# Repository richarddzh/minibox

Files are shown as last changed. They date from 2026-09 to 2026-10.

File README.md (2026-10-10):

# Minibox

| 目录 | 内容 |
|---|---|
| [`models`](models/enclosure-v2.md) | 四件式 3D 外壳模型、打印文件、尺寸说明及模型检查脚本 |
| [`assets`](assets) | 开发板[尺寸与天线图](assets/esp32s3_devkit_01.jpg)、[5.08 mm 接线端子](assets/crimp_terminal.jpg)、麦克风、功放、RTC、[TFT SPI](assets/tft_spi.jpg)、[摇杆](assets/joystick.jpg)与[三键键盘](assets/keypad.jpg)参考图片（TFT 型号与当前固件配置未核对） |
| [`docs`](docs/hardware-connections.md) | 主控、屏幕和摇杆的模块参数、GPIO 接线及供电注意事项 |
| [`kicad`](kicad/README.md) | KiCad 10 双层模块载板：[正面图例](kicad/renders/minibox-carrier-front-legend.png)、[背面图例](kicad/renders/minibox-carrier-back-legend.png)、GPIO 丝印与 Gerber；实物核对后方可制板 |
| [`esp32_idf_s3n16r8`](esp32_idf_s3n16r8/README.md) | ESP32-S3 N16R8 的麦克风、按钮、屏幕和扬声器测试固件 |

固件项目参考 `C:\gitroot\talking-alarm` 的 ESP-IDF 结构，独立构建，
不依赖该目录；当前默认测试 GPIO4/5/6/7 按钮，以 GPIO5 控制录放音。
当前接线为 RTC SDA=GPIO15、SCL=GPIO16，INMP441 SD=GPIO21，
MAX98357 GAIN=GPIO42、SD/MODE=GPIO47；GPIO17 悬空 NC，
摇杆按压焊脚保持 NC，GPIO42 不用于摇杆按压。

模型文档中的导出和检查命令均在 `models` 目录执行：

```powershell
Set-Location C:\gitroot\minibox\models
python -m unittest discover -s .\tests -p test_mesh_checks.py
```

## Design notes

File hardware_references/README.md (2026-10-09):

# Reference archive

本目录按用户要求保留集成工程的原始资料及关键图纸，方便换机。
PDF 保留原版权声明；TXT 和 PNG 为查阅用提取，不替代原 PDF。
`manifest.json` 记录 SHA-256、大小及 PDF 页数，以便核对迁移完整性。

| 归档文件 | 来源/用途 |
|---|---|
| esp32-s3-wroom.pdf | [Espressif](https://www.espressif.com/sites/default/files/documentation/esp32-s3-wroom-1_wroom-1u_datasheet_en.pdf)，N16R8 模块 |
| max98357.pdf | [Analog Devices](https://www.analog.com/media/en/technical-documentation/data-sheets/MAX98357A-MAX98357B.pdf)，裸功放 |
| inmp441.pdf | [TDK 产品](https://invensense.tdk.com/products/digital/inmp441/)，底部声孔/九焊盘；归档 PDF 为此前获取副本 |
| ap63203.pdf | [Diodes](https://www.diodes.com/assets/Datasheets/AP63200-AP63201-AP63203.pdf)，3.3V 降压 |
| ds3231.pdf | [Analog Devices](https://www.analog.com/media/en/technical-documentation/data-sheets/DS3231.pdf)，SN 内置晶体版本 |
| ch340.pdf | [WCH](https://www.wch.cn/downloads/CH340DS1_PDF.html)，C 型内置时钟及 3.3V 接法 |
| thb001p.pdf | C&K THB001P，[LCSC C2685355](https://www.lcsc.com/product-detail/C2685355.html)，裸摇杆针位/机械图 |
| cpg151101d13.pdf | HanElectricity CPG151101D13，[LCSC C49234235](https://www.lcsc.com/product-detail/C49234235.html)，MX 开关 |
| myoung-bs-12-b3aa003.pdf | MYOUNG，[LCSC C964723](https://www.lcsc.com/product-detail/C964723.html)，CR1220 座极性和尺寸 |
| sn74lv1t34.pdf | [TI](https://www.ti.com/lit/ds/symlink/sn74lv1t34.pdf)，RGB 电平转换 |
| tps25947.pdf | [TI](https://www.ti.com/lit/ds/symlink/tps25947.pdf)，已撤销的 eFuse 研究，非当前 BOM |
| tlv7034.pdf | [TI](https://www.ti.com/lit/ds/symlink/tlv7034.pdf)，已撤销的分立 CC 检测研究 |
| tlv431.pdf | [TI](https://www.ti.com/lit/ds/symlink/tlv431.pdf)，已撤销的 CC 参考电路研究 |
| sn74lvc2g02.pdf | [TI](https://www.ti.com/lit/ds/symlink/sn74lvc2g02.pdf)，已撤销的 CC 窗口逻辑研究 |
| sn74lvc1g11.pdf | [TI](https://www.ti.com/lit/ds/symlink/sn74lvc1g11.pdf)，逻辑研究参考 |
| sn74lvc1g02.pdf / sn74lvc1g08.pdf / sn74lvc1g27.pdf / sn74lvc1g32.pdf / sn74lvc14a.pdf | TI 逻辑研究，未采用或已撤销，非当前 BOM |
| panasonic-zk.pdf | Panasonic 储能电容研究，已撤销，非当前 BOM |
| tusb320.pdf / tusb320lai.pdf | [TI](https://www.ti.com/lit/ds/symlink/tusb320lai.pdf)，未采用的 Type-C 控制器研究；内部 Rd 不可与额外 5.1k 并联 |
| pcf8563.pdf / rkjxv.pdf | 早期 RTC/摇杆研究，**不是当前 BOM** |

USB 实选 HRO TYPE-C-31-M-12，[LCSC C165948](https://www.lcsc.com/product-detail/C165948.html)。
供应商 PDF 返回访问限制，未将错误页伪装成 PDF，也没有归档该型号 STEP。
方向判断使用 KiCad 实际封装坐标；生产前仍须工厂核对实物图纸。

标准符号/封装来自 KiCad 10 库，版权归上游作者，遵循上游
CC-BY-SA 及电路设计例外（见库许可证）。项目自建 INMP441、THB001P、
CR1220 封装由对应器件图纸推导；标准库复制和修改不改变
上游许可。本地缓存不等于完整 3D 模型归档。

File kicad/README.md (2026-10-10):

# Minibox carrier v1.2 — 2026-10-10

This is the user's actual `kicad` carrier, not the separate integrated design.
Open `minibox-carrier.kicad_pro` in KiCad 10. There is **no schematic**:
PCB DRC/net checks do not constitute ERC or schematic-parity verification.
The direct-solder revision is implemented; final review is documented in
[the Chinese HTML guide](carrier-revision.html) and [revision checklist](layout-revision-plan.md).
**Engineering-review files are not permission to manufacture or order.**

## Layout and parts

The board is **94.5 × 117 mm, R5**, four copper layers, nominal 1.6 mm.
Four Ø3.0 mm NPTH holes have **84.5 × 107 mm** center spacing;
KiCad centers are (10,8), (94.5,8), (10,115), (94.5,115) mm.
Each hole has a 3.5 mm-radius/square conservative all-layer copper keepout.
Ø3.0 mm is a tight M3 fit: check screw size/tolerance and the new enclosure.
Bounding-rectangle area is only 1.28% smaller than the old 100 × 112 mm board.

| Placement | Required reservation |
|---|---|
| ESP32 | USB left, antenna right; estimated body stays inside PCB |
| RTC | Upright, battery included in 27.5 × 12 mm reservation; 3.03 mm to ESP32 estimate |
| MAX98357 | Flat 27 × 24 mm reservation; bottom Y=72, above keycap top Y=80.5 |
| Red boundary | Y=76; upper bodies ≤74, lower operation envelopes ≥78 |
| Joystick JS1 | Vertical, center (16.8,95.5); **30 mm diameter** motion may overhang 3.20 mm; body/pad copper retain ≥1 mm to the left copper boundary |
| Microphone | Center (44.455,90.25), Ø19.5 mm envelope; top Y80.5; horizontal maximin clearance to all keycaps and joystick motion is approximately 3.40 mm |
| Four keys | Standard 19.05 mm pitch both ways; lower row moves right 1.425 mm, retaining 8.10 mm left stagger and 0.20 mm to the screw square |
| Keycaps | Maximum accepted envelope 18 × 18 mm; neighboring gap 1.05 mm |
| Wire entries | J8/J9 left, J7 right; external wire/tool clearance still requires a fit check |

SW1–SW4 use **HanElectricity CPG151101D13 / C49234235**; JS1 uses
**YTL YV13S-L7.85-B10Ka(60)-0-DL01 / C37323747**.
Their local footprints are traced to the exact linked drawings, not generic
MX/joystick substitutes. The joystick has a press mechanism but **it is intentionally
unused**; switch and mounting leads have no net; **GPIO42 now controls amplifier GAIN**.
Reference PDFs and layout images are in [`hardware_references`](../hardware_references/carrier-revision-references.md).
The exact parts lack precise supplied 3D models; renders must not be mistaken
for complete assembled-product models. Module envelopes and keycap size are
acceptance reservations, not measured/verified models.

J11/J12 cable sockets are removed. Remaining female strips: 1×22 two,
1×14 one, 1×7 one, 1×6 one, **1×3 two**, totaling seven strips/77 contacts.
J3 is two separate 1×3 sockets, row spacing 7.62 mm, **not** a normal 2×3 socket.
Three 5.08 mm screw terminals, four direct-solder switches, one direct-solder
joystick, and two 0402 resistors complete the assembly. All components install
from the front; THT leads solder from the back.
J7 is **KANGNEX WJ500V-5.08-03P-14-00A / C72334**; J8/J9 are
**WJ500V-5.08-2P / C8465**. Exact local footprints include the 0.60 mm joining
lug, 10 mm body depth, 14.07 mm height, and a tolerance-aware courtyard.
J8/J9 move left2.5/up3.94 mm from the prior version, with anchors
(11.5,48.56)/(11.5,61.06). J8's actual body top aligns with the estimated
ESP32 body bottom at Y45.97; their wire entries and electrical order are unchanged.
The selected terminal holes are **Ø1.50 mm**, with unchanged Ø2.60 mm pads
and 0.55 mm radial annular rings. No original Phoenix 3D model is reused
to impersonate the selected WJ500V; current renders show its holes/outline,
not an exact terminal body.

## GPIO and Type-C

Keys → GPIO4/5/6/7 (active-low, internal pulls); RTC SDA/SCL →15/16;
MIC_SD →21; amplifier GAIN/SD_MODE →42/47; GPIO17 is NC. I2S WS/BCLK/DIN →39/40/41;
joystick VR1/VR2 wipers →1/2; LCD remains GPIO9–14.
Actual front silkscreen identifies each module/terminal signal and its GPIO
using digits only, for example `SDA15`, `BCLK40`, `DIN41`, and `KEY1 4`.
Power pins retain `3V3`/`5V`/`GND`; disconnected pins retain `NC`.
Labels are on `F.SilkS`, not just the non-printing fabrication layer.
See [the authoritative wiring table](../docs/hardware-connections.md).
RTC front-view order is CLK/INT/SCL/SDA/3V3/GND; only functional net names
and labels changed, retaining both original copper paths. INMP441 front-view
left top-to-bottom is L/R(GND), WS39, SCK40; right is GND, 3V3, SD21.
The lower-row centre reaches approximately58% of the upper-left key width:
the requested approximate2/3 position would overlap the lower-right screw square
with18 mm keycaps. The screw exclusion takes priority without moving the hole.
The joystick's leftmost pad copper is X7.22 mm:1.22 mm from the X6 mm
copper-pour boundary and2.22 mm from the board edge. The body gap is1.05 mm.
Octal-memory GPIO35/36/37 are unused, as are USB19/20 and UART43/44.
GPIO39–42 cannot simultaneously be used for external four-wire JTAG.
Actual clone RGB firmware remains GPIO48; official v1.1 uses38, requiring
physical board identification, not an automatic firmware change.
The requested independent GPIO audit checked all44 J1/J2 pads against the
[official v1.1 J1/J3 table](https://docs.espressif.com/projects/esp-dev-kits/zh_CN/latest/esp32s3/esp32-s3-devkitc-1/user_guide_v1.1.html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):
no mapping errors or peripheral conflicts were found. Verify the clone's
actual pinout/RGB before production. The user has tested the actual INMP441
module and confirmed no additional SD pull-down is needed; keep the carrier,
firmware and BOM unchanged. This does not establish the module's internal
resistor arrangement or apply to other module variants.

External Type-C VBUS/GND →J8; independent CC1/CC2 →J9 pads1/2.
R1/R2 each pull their own CC to GND through **5.1 kΩ, 0402, 1%**.
Do not short CC1/CC2 or parallel Rd already present on a Type-C breakout.
This identifies a ordinary **5 V sink**, not USB-PD or a 3 A guarantee.
No USB data traces are routed. Check regulator current and USB/external-5V
backfeeding before connecting two sources.

## Routing and manufacturing review

F.Cu signals/GND; In1 continuous GND; In2 separated power corridors/GND;
B.Cu signals/GND. I2S prefers F.Cu/In1, with limited B.Cu/In2-ground-reference
branches. The router checks actual filled reference copper every ≤0.1 mm
outside necessary same-net antipads and requires one connected In1 region.
Signal vias receive nearby GND stitching. This is not a signal-integrity test.
Ground stitching was pruned from41 to23 vias after rerouting;18 redundant
vias were removed, with candidate-by-candidate connectivity/refill checks.
The current manifest records the final counts: retain return paths within
3 mm of every signal/power via and connections to separate ground-copper regions.
Do not add periodic stitching along same-layer I2S traces merely for their length;
the continuous reference plane carries their return current.

Signals/clearance **0.20/0.20 mm**, 3V3 feeders0.65 mm, 5V feeders0.80 mm;
ordinary vias **0.60/0.30 mm**. Copper-edge0.50 mm; PTH hole spacing0.45 mm;
Track-to-other-net pad clearance is **0.30 mm**, or **0.50 mm** at 5V pads.
The upper keys retain their previous positions; rightmost keycap-to-edge gap0.60 mm.
These tighter mechanical edge margins require an enclosure/cap tolerance check.
silk ≥1.0 mm with0.15 mm strokes. Header holes1.0/pads1.7 mm;
terminal holes1.5/pads2.6 mm; switch holes1.5/pads2.1 mm.
Do not treat signal width or these power feeders as a 3 A qualification.
Actual factory stackup/copper thickness, temperature rise and power bottlenecks
remain review items. [Domestic JLC capability rules](../docs/jlc-pcb-design-spec.md)
distinguish limits from recommendations.

Actual latest DRC/mechanical metrics and hashes belong in
`assembly\manifest.json` and `drc.json`;
an absent report or failed gate means export is incomplete.
Only a clean saved board may pass `export_revision.py`.
The exporter checks all plated-pad/via centers on all four copper CAM layers
against the saved PCB, and checks PTH/NPTH drill coordinates and diameters using
the same lower-left origin. This is digital alignment, not factory registration certification.
R1/R2 use verified UNI-ROYAL 0402WGF5101TCE/C25905, 5.1 kΩ ±1%;
domestic catalog stock is not reserved. Full-assembly BOM now identifies all
17 physical pieces with C numbers, including the five LAIL female-strip sizes.
Factory insertion/soldering approval, actual fit and final supply leave the BOM
**review-only**, even if DRC is clean.

### JLC placement-library mapping

Use `assembly\positions-jlc-review.csv` for the selected
domestic JLC library, together with the full BOM and the unchanged Gerber ZIP.
`positions-all-review.csv` records KiCad pad centres/footprint angles; it is
**not directly interchangeable** with the JLC file. In the factory library,
the seven female strips have a different zero angle and JS1 has a different
head datum. The exporter fits numbered library pads to actual saved PCB pads,
including the two separate J3 strips, and rejects mismatched parts or geometry.
`jlc-placement-review.json` records each angle, origin and pad-fit residual.
It also records the KiCad centre/angle and the factory origin/angle corrections.
`jlc-saved-placement.json` preserves the actual factory-saved, refreshed readback
for this board hash. Generated placements are checked against that snapshot at
the website's coordinate precision. After changing the layout, regenerate from
the new PCB: reuse library datum definitions, never copy old absolute positions.
The old snapshot is then historical evidence, not approval of the new layout.

This corrects assembly instructions, not copper or holes. Gerber has no
component-library rotation/model mapping; do not rotate PCB footprints or
change Gerber geometry to repair a factory preview. Missing J4/J6 3D models
are not missing parts. Verify the website's rotation convention and saved
positions against the actual Gerber pads before approving factory DFM.
The files remain engineering review inputs, not production approval.

Regenerate only these placement files without rerouting or re-exporting CAM:

```powershell
& 'C:\Program Files\KiCad\10.0\bin\python.exe' .\kicad\export_jlc_positions.py
```

## Current outputs and Git history

| Current revision | Purpose |
|---|---|
| `renders\assembly-layout.svg` | Reservation layout, not exact assembled geometry |
| `renders\minibox-carrier-front.png` / `back.png` | Genuine saved-board renders |
| `renders\minibox-carrier-isometric.png` | Genuine saved-board perspective |
| `renders\minibox-carrier-front-legend.png` / `back-legend.png` | Current Chinese material legends and board/hole dimensions |
| `assembly` | DRC, manifest, SMT BOM/CPL, separate THT positions, pin map |
| `fabrication` | Four-copper-layer Gerbers and separate PTH/NPTH drills |
| `fabrication\minibox-gerber-review.zip` | PCB CAM review archive |

Only fixed current paths are retained. Previous quote CSVs, dated revision
directories and older archives are recoverable from Git history, not alternate
submission inputs. The manifest records PCB/artifact hashes rather than a date
as a version identifier. Do not embed the current commit SHA in generated files:
it would describe the pre-export commit and change again when those files commit.
No order, upload, purchase or payment is authorized by these files.

## Reproducible commands

From `C:\gitroot\minibox`, after explicitly backing up the routed board:

```powershell
& 'C:\Program Files\KiCad\10.0\bin\python.exe' .\kicad\generate_board.py --replace-routed
& 'C:\Program Files\KiCad\10.0\bin\python.exe' .\kicad\route_board.py
& 'C:\Program Files\KiCad\10.0\bin\python.exe' .\kicad\prune_ground_vias.py
& 'C:\Program Files\KiCad\10.0\bin\python.exe' .\kicad\export_revision.py
```

Generation replaces routing, so its default guard refuses to overwrite tracks.
Inspect every command's result; do not continue after a failure.
For PNGs, use KiCad `pcb render --side top|bottom --quality basic` (high is optional).
Then run `python .\kicad\add_render_legends.py`; its dimensions are read
from the saved PCB, and the legends now correctly identify four copper layers.
After updating renders or documentation, run `python .\kicad\package_review.py`
to refresh `assembly\minibox-assembly-review.zip` and all artifact hashes.
Every PCB/part change requires the full export, not only the coordinate command.
The full exporter now also renders the saved board's front/back/isometric PNGs
and regenerates both Chinese dimension/legend images before packaging.
`render_source_board_sha256` binds that render batch to the exported PCB.
After partial rerouting, the pruning command removes only redundant GND vias,
refilling and checking each candidate's connectivity and actual I2S reference
copper. It preserves a GND return via within3 mm of every signal/power via.
Its reduction report is in `assembly\ground-stitching-review.json`; run the
full export afterwards to renew DRC, renders, CAM, placements and hashes.

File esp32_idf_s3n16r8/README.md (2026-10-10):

# ESP32-S3 N16R8 microphone test

当前固件配套 2026-10-09 载板改版，开机初始化 ST7796 屏幕，
显示 GPIO4/5/6/7 四个按钮的状态。旧载板不能直接使用本接线配置。
**按住 GPIO5** 按钮立即开始录音（消抖约 30 ms），最多录制 3 秒；
录满会停止采集并等待松开。**松开 GPIO5** 后从 MAX98357 播放录音。
播放期间的按键不触发新录音，播放完成并松开后可再次测试。GPIO4 和
GPIO6、GPIO7 只显示按键状态，不触发录音；不需要摇杆。
串口会报告麦克风采样数、幅度和音频错误。先前的电台模块代码仍在工程，
但当前启动不连接 Wi-Fi，也不播放电台。

## 接线

| 模块 | 信号 | ESP32-S3 |
|---|---|---|
| 四个直焊机械轴 | 两个常开触点 | 分别接 GPIO4/5/6/7 与 GND，不接 VCC |
| INMP441 麦克风 | SD / WS / SCK / L/R | GPIO21 / GPIO39 / GPIO40 / GND |
| MAX98357 放大器 | DIN / LRC / BCLK | GPIO41 / GPIO39 / GPIO40 |
| MAX98357 放大器 | SD/MODE / GAIN | GPIO47 / GPIO42 |
| 摇杆（当前不初始化） | X / Y | GPIO1 / GPIO2 |
| 摇杆按压（不使用） | K | 按压焊脚 NC，驱动不配置按压 GPIO；GPIO42 用于功放 GAIN |
| RTC（当前未实现驱动） | SDA / SCL | GPIO15 / GPIO16 |
| 未连接 GPIO | GPIO17 | 悬空 NC，不配置 |

INMP441 正面视角左列从上到下为 L/R、WS、SCK，右列为 GND、VCC、SD；
此处描述信号位置，不改变模块物理焊盘编号。

直焊机械轴按下接地，必须使用 GPIO 内部上拉及低有效配置。若改接高有效模块，
先在 `idf.py menuconfig` → `Minibox hardware test` 关闭
`GPIO4/5/6/7 buttons pressed at low level`，再构建烧录。不要让按钮
OUT 超过 3.3 V；四路按钮共地。录音和回放共用 GPIO40/39 时钟线，
固件先释放麦克风 I2S 通道再启用放大器。GPIO47 在回放时使能放大器；
GAIN=GPIO42 默认高阻；菜单中的 12 dB 选项将 GPIO42 输出为低电平。
扬声器接 SPK+/SPK-，模块按额定电压供电。
屏幕 GPIO9–14、完整模块参数和注意事项见
[`docs/hardware-connections.md`](../docs/hardware-connections.md)。
GPIO40/41 没有 ADC，不能用于摇杆 X/Y；摇杆配置默认值已改为
GPIO1/2，按压功能关闭。旧本地 `sdkconfig` 必须同步轴配置。编译检查会拒绝
摇杆与键盘或音频引脚冲突的配置。现有实物接线必须与新分配同步，
不能只更新固件而保持原接线。

## 构建与观察

使用 ESP-IDF 5.3.5 PowerShell 环境：

```powershell
Set-Location C:\gitroot\minibox\esp32_idf_s3n16r8
idf.py build
```

明确准备覆盖板上固件时才执行 `idf.py -p COM8 flash`，之后可执行
`idf.py -p COM8 monitor` 查看串口（`Ctrl+]` 退出）。烧录会同时写入
SPIFFS 字体分区；屏幕缺字或初始化失败时核对字体镜像、GPIO9 背光和
供电。电台模式曾在 Wi-Fi 启动时触发欠压复位，本测试不启动 Wi-Fi；
如仍发生 brownout，请先检查 USB 线、供电和外设负载，而非关闭欠压保护。
构建或串口日志不能代替现场检查屏幕、麦克风和扬声器。

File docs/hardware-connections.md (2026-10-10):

# 模块参数与接线

本文集中维护 Minibox 的实际模块接线。修改硬件时同步更新本文和固件配置，
避免文档与接线不一致。

## 主控：ESP32-S3 N16R8

| 参数 | 值 |
|---|---|
| 芯片 | ESP32-S3，实板识别 revision v0.2 |
| Flash | 16 MB，Quad SPI，3.3 V |
| PSRAM | 8 MB，Octal，3.3 V |
| 固件 Flash 配置 | DIO，80 MHz |
| 固件 PSRAM 配置 | Octal，40 MHz |
| 当前电脑串口 | **COM8**，USB-Enhanced-SERIAL CH343 |
| 串口日志 | UART0，115200 波特率 |
| 固件项目 | [`esp32_idf_s3n16r8`](../esp32_idf_s3n16r8/README.md) |

COM8 是当前 Windows 分配的端口，更换电脑或 USB 接口后可能变化。
GPIO19/20 保留给原生 USB；不使用 GPIO35/36/37，以避免与 N16R8
Octal PSRAM 冲突。

## 按载板布局分配 GPIO

依据 [ESP32-S3-DevKitC-1 v1.1 官方排针表](https://docs.espressif.com/projects/esp-dev-kits/zh_CN/latest/esp32s3/esp32-s3-devkitc-1/user_guide_v1.1.html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)
分配：左侧摇杆使用 GPIO1/2 的 ADC1，左侧功放的时钟和 DIN 使用
GPIO39/40/41，RTC 使用 SDA15 / SCL16；四个机械轴使用 GPIO4/5/6/7，
屏幕仍使用 GPIO9–14。GPIO40/41 **没有 ADC**，不能直接读取模拟摇杆。
GPIO0/3/45/46 启动配置脚、GPIO19/20 原生 USB、GPIO43/44 UART0、
GPIO35/36/37 Octal 存储器，以及 GPIO38/48 板载 RGB 候选脚均不接外设。
GPIO39–42已用于I2S及GAIN，不能同时使用这些排针做外部四线JTAG调试。
GPIO42 接功放 GAIN，摇杆按压功能不用；GPIO8/17/18 悬空 NC。
GPIO21 接麦克风 SD。官方 v1.1 的 RGB 使用 GPIO38，
当前实板固件仍保持 GPIO48，须按实际开发板确认，不因网页版本自动改动。

与旧载板相比，音频、键盘、摇杆及 RTC 的 GPIO 分配已变化；
**新 PCB、固件和实物线缆必须配套使用**，不要混用旧接线。

载板外部 5 V 正极先接三针开关的电源端，外部 GND 接开关 GND；
开关负载端给开发板 **5V** 排针及 MAX98357A VIN 供电。开发板的
**3V3** 排针再给屏幕、麦克风、RTC 和摇杆供电；机械轴仅接 GPIO/GND。
载板 J8 为 5.08 mm 双位接线端子（正面从上到下：5V 输入、GND），
J7 为 5.08 mm 三位接线端子（正面从上到下：开关 GND、
开关负载端、开关电源端）；请优先按焊盘号及网名核对，不沿用旧方向。
J9 是独立 CC1/CC2 双位端子；J8/J9 进线向左，J7 进线向右。
键盘轴及摇杆直接焊接；其余模块维持 2.54 mm 母座。
[`接线端子参考图`](../assets/crimp_terminal.jpg)仅确认节距，
购料前还要核对所购接线端子的实物针脚与 KiCad 封装。
端子采购型号为 KANGNEX：J7 使用 WJ500V-5.08-03P-14-00A / C72334，
J8/J9 使用 WJ500V-5.08-2P / C8465。按厂家图纸采用 Ø1.50 mm 孔，
本体深 10.00 mm、高 14.07 mm，封装包含 0.60 mm 拼接凸耳和公差空间。
2026-10-10，J8/J9 相对上一版左移2.5/上移3.94 mm，锚点为
(11.5,48.56)/(11.5,61.06) mm；J8本体上沿Y=45.97与ESP32估计下沿平齐。
J7 锚点 (88,65) mm 不变，全部进线方向及引脚网名不变。
载板所有排母和接线端子均从正面插装、背面焊接，采用双面开窗的
镀通孔焊盘：排母孔径 1.0 mm、焊盘 1.7 mm；J7/J8/J9 孔径 1.5 mm、
焊盘 2.6 mm，径向焊环 0.55 mm。四层版本的 GND 焊盘通过热焊盘连接内层地平面，
包括 J1 第 22 脚及 J5 第 6 脚，不再依赖原双层板的专用地线走线。
模块信号引脚丝印保留功能名称并标注
连接的 GPIO 编号，编号只写数字，例如 SDA15、BCLK40、DIN41、KEY1 4；
未连接信号标为 NC。实际标签位于 F.SilkS，不仅是 F.Fab 装配标注；
标签以正面视角为准，键轴触点另标数字与 GND，摇杆两轴标 X 1 / Y 2。
为背面手工焊接留出余量，J7 第 1/2 脚和 J8 第 1 脚的 5V 焊盘
在全部四个铜层与 GND 覆铜及其他网络保持至少 0.5 mm 铜间距；
其余覆铜采用 0.35 mm 间距，普通走线相互间距 0.20 mm；
走线到异网焊盘至少 0.30 mm，5V 焊盘仍至少 0.50 mm。
3.3 V 由开发板上的稳压器产生，而非 ESP32-S3 芯片自行转换。
必须核实实际开发板稳压器的可用电流，以及 USB 与外部 5 V
同时连接时是否会反灌；不能把开发板的 3V3 脚接到开关负载 5 V。

2026-10-09 改版外形为 **94.5 × 117 mm、R5 圆角**。
相对旧 100 × 112 mm，包围矩形面积减少约 1.28%，不是大幅压缩。
四个 Ø3.0 mm NPTH 安装孔为 (10,8)、(94.5,8)、(10,115)、(94.5,115)；
中心距 **84.5 × 107 mm**。旧外壳孔位不能沿用。
ESP32 USB 朝左，天线朝右；估算本体完整留在板内，四层天线禁铜区
X=81–99.5、Y=20.6–42.1 mm。估算外形不等于厂商机械图，实物须复核。
RTC 位于 ESP32 上方，含电池预留 27.5 × 12 mm，至 ESP32 约 3.03 mm；
MAX98357 平放预留 27 × 24 mm，下缘 Y=72，上排键帽上缘 Y=80.5。
水平分界线 Y=76，两侧各留 2 mm 安装隔离带：上方本体不超过 Y=74，
下方操作包络不早于 Y=78；该约束不禁止信号走线跨分界。
四轴中心距 19.05 mm，下排相对上排左错8.10 mm；
18 × 18 mm 是键帽允许最大包络，不是已确认键帽型号，邻帽间隙 1.05 mm。
上排不动，最右键帽距板边0.60 mm；下排两键右移1.425 mm，中心为
(62.75,108.55)/(81.8,108.55)，与右下螺丝方形保护区留0.20 mm。
整排中心对齐左上键宽度约58%处：精确2/3会与该螺丝区冲突，未缩小18 mm键帽。
摇杆竖放，中心(16.8,95.5)，相对上一版左移3.95/上移2 mm；
最左焊盘铜边X=7.22 mm，距X=6 mm左侧覆铜边界1.22 mm，
距X=5 mm板边2.22 mm；实体至覆铜边界1.05 mm，不把焊盘挪到板边。
预留 **直径30 mm / 半径15 mm** 活动圈允许越出板边3.20 mm，
但实体和焊接孔位不越界；至左下螺丝方形保护区约1.34 mm。
麦克风预留圈中心(44.455,90.25)、直径19.5 mm；
上沿 Y=80.5，与上排键帽齐平，不高于键盘。
固定该Y时，水平移动采用最大化最近控制件边缘间隙的位置：
至最近键帽及摇杆活动圈均约3.40 mm，而非仅比较中心距离。
靠近板边的新间隙是用户指定移动后的接受包络，须用外壳、帽沿和公差实测。
模块外形及 RTC 厚度是安装接受包络，必须用实际模块及电池确认。
麦克风安装两个独立 1×3 母座，排距 7.62 mm，不是普通 2×3 母座。
保留母座总计 7 条、77 个接点；另装三个压线端子、四个机械轴、
一个摇杆及两个 0402 电阻。所有器件从正面安装，插件背面焊接。
四层为顶层信号 / In1 连续 GND / In2 电源走廊及 GND / 底层信号；
I2S 顶层参考 In1，必要的底层分支参考 In2 地通道，换层附近缝合地。
本轮重布线后地过孔由41个减至23个，删除18个冗余孔；
候选删除逐次填铜检查，数量及报告以本版manifest为准。保留所有信号/电源
过孔 3 mm 内的地回流孔，以及连接分区地铜的孔。不再沿同层 I2S 走线
按固定间距增加地孔；同层走线依靠连续参考地平面回流。
信号 0.20 mm，3V3 0.65 mm，5V 0.80 mm，普通过孔 0.60/0.30 mm；
这些电源宽度不构成 3 A 载流承诺。名义板厚 1.6 mm，实际铜厚、
叠层、热设计及四层报价须经工厂复核。
实际状态、效果图及资料见 [`kicad/README.md`](../kicad/README.md)。

### Type-C 5 V 识别

外部 Type-C 母座的 VBUS/GND 接 J8，CC1/CC2 分别接 J9 第 1/2 脚；
R1/R2 各为 5.1 kΩ、0402、1%，独立从各 CC 拉到 GND，不得短接 CC1/CC2。
该电路只是普通 5 V 受电端 Rd 标识，不进行 USB-PD 协商，也不保证 3 A。
使用的外接 Type-C 小板若已带 Rd，不得再并联本板电阻。
本载板不接 USB 数据线。焊好后断电测量每条 CC 对地约 5.1 kΩ，
再用限流电源检查 5 V 极性、开关和稳压输出。

## 屏幕模块：ST7796 SPI

| 参数 | 值 |
|---|---|
| 控制器 | ST7796 |
| 显示分辨率 | **480 × 320**，横屏 |
| 显示朝向 | 横屏交换坐标轴（MV），清除 MX/MY 镜像；BGR 开启时 MADCTL=0x28 |
| 接口 | SPI，模式 0，SPI2_HOST |
| 默认 SPI 时钟 | 40 MHz，可配置为 1–40 MHz |
| 屏幕驱动 | 乐鑫 `espressif/esp_lcd_st7796` 1.4.0，纯 ESP-IDF |
| 像素格式 | RGB565，16 bit，高字节先发送 |
| 字体 | 24 px 中英文抗锯齿字体，存放在 SPIFFS，见[字体说明](display-fonts.md) |
| 默认色序 | BGR，可配置 |
| 默认反色 | 关闭，可配置 |
| 背光控制 | 默认高电平点亮，可配置极性 |
| 背光调制 | 无 PWM；启动点亮后保持恒定电平 |

| 屏幕引脚标识 | ESP32-S3 引脚 | 作用 |
|---|---|---|
| LED / BL | **GPIO9** | 背光控制 |
| SCK / CLK | **GPIO10** | SPI 时钟 |
| SDI / MOSI | **GPIO11** | 主控向屏幕发送数据 |
| DC / RS | **GPIO12** | 命令 / 数据选择 |
| Reset / RST | **GPIO13** | 硬件复位，低电平有效 |
| CS | **GPIO14** | 片选，低电平有效 |
| SDO / MISO（若有） | 不接 | 当前固件只写屏幕，不读取 ID |
| GND | GND | 与主控共地 |
| VCC | 3.3 V | 用户指定屏幕使用 3.3 V；实际模组额定范围和开发板 3.3 V 稳压器负载能力仍须核实 |

用户确认屏幕排针顺序与 [`tft_spi.jpg`](../assets/tft_spi.jpg)
相同：1 VCC、2 GND、3 CS、4 RESET、5 DC/RS、6 SDI(MOSI)、
7 SCK、8 LED、9 SDO(MISO)、10 T_CLK、11 T_CS、12 T_DIN、
13 T_DO、14 T_IRQ。当前固件不用 SDO 和触摸功能，9–14 脚不接。
参考图标为 **2.8 英寸 240×320**，本项目屏幕记录为
**4 英寸 480×320**；只据用户确认采用排针顺序，屏幕实际控制器、
排距、孔位和供电仍需核实，不能据参考图推断显示模组完全相同。

屏幕逻辑信号必须兼容 **3.3 V**。GPIO9 只能连接背光控制输入：
如果模块 LED 引脚是裸背光供电端，需采用额定限流和晶体管/MOSFET 驱动，
不能直接由 GPIO 承担背光电流。

屏幕接线常量位于
[`main/app_config.h`](../esp32_idf_s3n16r8/main/app_config.h)。
SPI 时钟、色序、反色和背光极性位于
`idf.py menuconfig` → `Minibox hardware test`。

## 四个直焊机械键盘轴

SW1–SW4 使用用户指定 HanElectricity **CPG151101D13 / C49234235**，
每轴触点 1 接各自 GPIO、触点 2 接 GND，按下闭合，无 VCC 接点。
取消 J11/J12 母座。触点孔 Ø1.50 mm，中心定位 NPTH Ø3.90 mm；
孔位由该型号图纸核对，不采用带额外 LED/定位柱的通用 MX 封装。

| 模块信号 | ESP32-S3 接线 | 当前功能 |
|---|---|---|
| SW1 触点 1 | **GPIO4** | 屏幕显示按下/松开 |
| SW2 触点 1 | **GPIO5** | 按住录音，松开回放 |
| SW3 触点 1 | **GPIO6** | 屏幕显示按下/松开 |
| SW4 触点 1 | **GPIO7** | 屏幕显示按下/松开 |
| 各轴触点 2 | **GND** | 共地；不能接 3.3 V |

默认按下输出低电平，使用 GPIO 内部上拉，每 10 ms 采样并做 30 ms
消抖。直焊轴必须保持菜单 `GPIO4/5/6/7 buttons pressed at low level`
开启；高有效选项仅保留给兼容的外接模块。

## 直焊摇杆：YV13S-L7.85-B10Ka(60)-0-DL01

JS1 为用户指定 YTL **C37323747**。六个电位器引脚为 Ø1.0 mm PTH，
VR1 滑动端 X2 接 GPIO1、VR2 滑动端 Y2 接 GPIO2；各自端点 1 接 GND，
端点 3 接 3.3 V。四个固定焊脚及四个按压焊脚保持无网络。
该型号本身有按压开关，但用户决定不用；按压焊脚保持 NC，**GPIO42 用于功放 GAIN**，
固件不配置或读取按压 GPIO。当前应用不初始化摇杆，两轴实体方向、
旋转后的正负方向与校准仍须装配后核对，不能当成已通过硬件测试。
GPIO1/2分别是ADC1_CH0/CH1。ESP32-S3在12 dB衰减下的标称有效测量
上限约2.9 V，3.3 V供电的电位器上端可能饱和；启用摇杆时需要端点标定，
不能将全程读数视为线性电压计。

## RTC：PCF8563T

载板 J5 SDA 接 GPIO15、SCL 接 GPIO16；
VCC 接 3.3 V、GND 共地；
CLK 和 INT 保留物理孔位但不接信号。确认模块的 I2C 上拉接到 3.3 V，
没有上拉时须补齐。固件 `RTC_SDA_PIN` / `RTC_SCL_PIN` 已预留对应编号，
当前应用尚未初始化 RTC，也没有新增 RTC 驱动。

## 麦克风：INMP441（I2S）

模块正面视角：左列从上到下为 **L/R、WS、SCK**，
右列从上到下为 **GND、VCC、SD**（VCC 即下表的 VDD）。
这是信号位置说明，不重新定义模块物理焊盘编号。

| 模块信号 | ESP32-S3 接线 | 作用 |
|---|---|---|
| SD | **GPIO21** | 麦克风串行数据输入 |
| WS | **GPIO39** | 声道选择 / 帧时钟 |
| SCK | **GPIO40** | 位时钟 |
| L/R | GND | 选择左声道，与固件的左声道采集一致 |
| VDD | **3.3 V** | 按模块额定电压供电，不接 5 V |
| GND | GND | 共地 |

录音使用 16 kHz、32-bit I2S 左声道采样，转换为 16-bit 单声道 PCM。
SD 是麦克风输出，不能与放大器 DIN 相接。
用户已实测当前INMP441模块，确认不需要额外增加SD下拉电阻。
本载板和固件保持不新增下拉，BOM不增加元件；取消此项生产前待确认条件。
该结论适用于已测试的实际模块，不据此推断模块内部是否已有下拉，
也不推广到裸芯片或其他模块型号。

## 扬声器放大器：MAX98357（I2S）

| 模块信号 | ESP32-S3 接线 | 作用 |
|---|---|---|
| DIN | **GPIO41** | 音频数据输出 |
| BCLK | **GPIO40** | 与麦克风 SCK 共用位时钟 |
| LRC / LRCLK | **GPIO39** | 与麦克风 WS 共用帧时钟 |
| VIN | **开关输出 5V（5V_SW）** | 载板 J4 第 7 脚接 J7 第 2 脚，并与开发板 5V 共用该网络；核对模块额定范围，逻辑信号仍为 3.3 V |
| GND | GND | 与主控和麦克风共地 |
| SD / MODE | **GPIO47** | 平时输出低电平关断；播放时输出 3.3 V 高电平使能左声道 |
| GAIN | **GPIO42** | 默认设为无上下拉的输入（高阻），模块使用约 9 dB 默认增益；可在菜单切换为输出低电平（约 12 dB） |
| SPK+ / SPK- | 扬声器两端 | 不将扬声器负极接主控 GND |

播放使用 16 kHz、16-bit 双声道（同一单声道样本送至左右声道），
适配放大器不同声道选择配置。**只接 DIN/BCLK/LRC 不够**：
VIN 和 GND 必须有正确供电，确认 SD/MODE 没有被拉低（关断）。
GPIO47 控制 SD/MODE，只在播放 I2S 数据时拉高；GPIO42 控制 GAIN，
默认高阻，不对模块施加 3.3 V；如需提高增益，可在
`idf.py menuconfig` → `Minibox hardware test` 启用 12 dB 设置。
这两个引脚不能再用作摇杆输入；不应同时将 SD/MODE 硬接 3.3 V 或 GND。
若实际模块并非 MAX98357A，请先核对其 SD/MODE 与 GAIN 的电气定义。
供电和扬声器阻抗须符合模块额定值；不要直接由 ESP32 GPIO 驱动扬声器。
GPIO40/39 仅供这两个模块共享，固件先停止并释放麦克风 I2S 通道，
再配置放大器 I2S 通道，两者**不会同时工作**。空闲和录音时放大器
SD/MODE 拉低、DIN 保持低电平。

## 音频半双工测试

按住 GPIO5 按钮后，稳定 30 ms 立即开始录音；继续按住最多录制
**3 秒**，满时停止采集并等待松开。松开后播放本次录音，提前松开则
立即停止录音并播放。播放期间新的按钮操作不触发新录音；播放完毕、
GPIO5 松开后重新就绪。GPIO4/6/7 不参与音频控制。
屏幕显示四个按钮和录音、等待松开、播放或错误状态。
录音在 8 MB PSRAM 中使用 **96000 字节（约 94 KiB）** 的缓冲区，
不写入 Flash；音频报错时屏幕保持错误状态，排查串口日志后复位。
未连接麦克风或声道选择不正确时可能录到静音。
若串口显示 `Mic: ... nonzero=...` 且 `Playing ...`，却没有声音，
优先测量放大器 VIN 对 GND 电压及播放期间 SD/MODE 对 GND 电压（约 3.3 V），
然后检查 SPK+/SPK-、扬声器阻抗与 DIN=GPIO41；I2S 软件调用成功
不能证明模块已经上电或解除关断。

## 板载 RGB LED

| 参数 | 值 |
|---|---|
| 控制引脚 | **GPIO48** |
| 控制方式 | WS2812 单线时序，RMT 输出 |
| 固件行为 | 启动时发送全零 RGB 数据，将板载灯熄灭，随后保持引脚低电平 |

仅拉低 GPIO 不会清除 WS2812 已锁存的颜色，因此固件会先发送黑色数据。
GPIO48 与屏幕背光 GPIO9 独立；关闭板载灯不影响屏幕。
板上若还有独立电源指示灯，则不能通过 GPIO48 关闭。

## 接线检查与上电

1. 断电检查 GPIO9–14 的屏幕信号顺序，确认 LED 是控制端还是供电端。
2. 检查四个机械轴触点分别接 GPIO4/5/6/7 与 GND，无 VCC；CC1/CC2 各自 5.1 kΩ 下拉。
3. 检查麦克风 SD=21、WS=39、SCK=40，放大器 DIN=41、LRC=39、BCLK=40、
   SD/MODE=47、GAIN=42，RTC SDA=15/SCL=16；
   GPIO17 悬空 NC，摇杆按压焊脚 NC，INMP441 L/R 接 GND，
   扬声器两端只接放大器输出。
4. 连接开发板 USB-UART 接口，在当前电脑使用 COM8 烧录。
5. 上电确认屏幕显示四个按钮状态；按住 GPIO5 录音，松开后听回放。

完整的构建、烧录及测试操作见
[`固件说明`](../esp32_idf_s3n16r8/README.md)；
模块机械尺寸及外壳安装参数见
[`模型尺寸说明`](../models/module-dimensions.md)。

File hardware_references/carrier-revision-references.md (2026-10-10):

# 载板改版元件资料

核对日期：2026-10-09。用于 `C:\gitroot\minibox\kicad` 的布局改版，
不是生产批准文件。原 `hardware\_references` 已合并到本目录，
重复文件逐一核对 SHA-256 后去重，原有资料及索引保留。
PDF 版权及使用条件归原作者；本目录只保存设计参考副本。

| 元件 | 数量 | 已核对的信息 | 来源 |
|---|---|---|---|
| HanElectricity CPG151101D13 | 4 | 立创 C49234235，直插机械键盘轴；孔位及定位孔须按 PDF 核对 | [立创商品页](https://item.szlcsc.com/51650377.html) |
| YTL YV13S-L7.85-B10Ka(60)-0-DL01 | 1 | 立创 C37323747，插件-14P、21 × 17 mm，10 kΩ、自复位 | [立创商品页](https://item.szlcsc.com/39051754.html) |
| 5.1 kΩ R0402 电阻 | 2 | CC1/CC2 独立 Rd；UNI-ROYAL 0402WGF5101TCE / C25905，±1%；保留原选型 | [用户最新指定商品页](https://item.szlcsc.com/26648.html) |
| CC1/CC2 接线端子 | 2 个接线位 | 拟用一个双位端子；5.08 mm 节距沿用现有端子系列，实际型号待定 | 用户要求；不能据现有 J7/J8 推断实购端子完全相同 |

## 本地文件

- `datasheets/cpg151101d13.pdf`：原归档副本，8 页；
  已核对当前商品页仍指向该型号的手册。
  当前公开下载地址：
  <https://atta.szlcsc.com/upload/public/pdf/source/20250618/D1C12809F8EDF275373534C56A4C291D.pdf>。
- `datasheets/yv13s-l7.85-b10ka-60-0-dl01.pdf`：从精确型号商品页下载，8 页。
  <https://atta.szlcsc.com/upload/public/pdf/source/20240806/1B8487ADF5BD9B353C3D03081821B46D.pdf>。
- `drawings/cpg151101d13-6.png`、`drawings/cpg151101d13-8.png`：
  原归档的机械图查阅副本，以 PDF 为准。
- `drawings/requested-layout.png`：用户提供的清晰布局图。

| PDF | 字节数 | SHA-256 |
|---|---|---|
| cpg151101d13.pdf | 3197551 | e49ad1b9f11d9e9d84fdec678f7172b31c23b63f83691d27e11b6a447deb1824 |
| yv13s-l7.85-b10ka-60-0-dl01.pdf | 638156 | 954709ccaf0202879e64b1c17a8ba384c11486283fe826515f4fd022c0393874 |

## 电气及装配注意

摇杆电位器手册给出的额定值为 AC 50 V 或 DC 5 V，按键接点额定值为
DC 12 V / 50 mA；不要把按键接点的 12 V 误用为模拟轴供电。
本项目两轴电位器端点接 3.3 V/GND，滑动端分别接 GPIO1/2，
该型号具有按压按键：第 1 页 S1/S2 常开开关，第 6 页开关机械性能。
用户决定**不使用按压功能**，GPIO42改接功放GAIN，不作按压预留；
按压焊脚保持无网络，不需要猜测手册未标明的物理触点分组。
PCB 中 SWA/SWB/SWC/SWD 按设计均无网络，固定脚 M1–M4 亦不擅自接地。
14 个物理引脚不等于 14 个独立信号。

## CC 下拉电阻采购标识

R1/R2：**UNI-ROYAL 0402WGF5101TCE / C25905**，
5.1 kΩ、±1%、英制0402/公制1005。
[LCSC 型号页](https://www.lcsc.com/product-detail/C25905.html)与官方检索结果
匹配这些参数；这是型号确认，不是国内嘉立创装配库存或价格承诺。
生产前仍核对国内选料、回流规格及备料。每条 CC 独立一个 Rd，不并联已有 Rd。

原厂手册记录焊锡性 235±5 °C、3±0.5 秒，焊锡耐热性 260±5 °C、
5 秒；这些是测试条件，不是整件可经过 SMT 回流炉的证明。
按键轴及摇杆拟从正面插装、背面焊接，电阻放正面贴装。

CC1 和 CC2 各自通过一只 5.1 kΩ 接 GND，不能短接两条 CC，
也不能用一只电阻共用。仅适用于外接 Type-C 母座把两条 CC 独立引出的情况。
若外接母座已有 Rd，不得重复并联；若只有 VBUS/GND 两线，
此板上的电阻无法替代缺失的 CC 连接。
Rd 用于声明受电端，不是 PD 控制器，也不保证获得 3 A。
本目录不记录实时价格或库存承诺。

## 全焊装配采购候选

以下为选料记录，不是工厂生产批准。用户已选择 WJ500V 两位/三位端子，
PCB 和审核 BOM 已适配；不表示已经采购或获准生产。
普通商城有商品、装配库有库存、封装兼容、工厂承接是四个独立核对项。
库存与报价随时变化，下单时重新查询。

| 位号 | 数量 | 精确型号 | 立创编号 / 国内装配目录 |
|---|---:|---|---|
| J1/J2 | 2 | LAIL-PM2.54-22P-L | [C54973843](https://www.jlc-smt.com/lcsc/detail/C54973843.html) |
| J3A/J3B | 2 | LAIL-PM2.54-3P-L | [C54973828](https://www.jlc-smt.com/lcsc/detail/C54973828.html) |
| J4 | 1 | LAIL-PM2.54-7P-L | [C54973832](https://www.jlc-smt.com/lcsc/detail/C54973832.html) |
| J5 | 1 | LAIL-PM2.54-6P-L | [C54973826](https://www.jlc-smt.com/lcsc/detail/C54973826.html) |
| J6 | 1 | LAIL-PM2.54-14P-L | [C54973850](https://www.jlc-smt.com/lcsc/detail/C54973850.html) |
| J7 | 1 | WJ500V-5.08-03P-14-00A | [C72334](https://www.jlc-smt.com/lcsc/detail/C72334.html) |
| J8/J9 | 2 | WJ500V-5.08-2P | [C8465](https://www.jlc-smt.com/lcsc/detail/C8465.html) |

五种排母均在国内装配目录显示为扩展库。22P 用户指定件的机械图已读取：
本体长 56.38±0.30 mm、宽 2.50±0.20 mm、高 8.50±0.20 mm，
针脚长 3.00±0.20 mm、截面 0.60×0.25 mm，节距 2.54 mm，推荐孔 Ø1.02 mm。
现板排母孔 Ø1.00 mm，须结合成品孔公差、针脚公差、全排定位和模块插入高度核对。
另外四种针数已逐份读取精确商品页的机械图，节距、宽、高、针脚和推荐孔一致。
3P/6P/7P/14P 本体长度分别为 8.12/15.74/18.28/36.06 mm，图示公差均 ±0.30 mm。
这些核对仍不代替全排针脚实物配合和工厂装配批准。
J3 必须是两个独立 1×3，不是普通 2×3。

WJ500V 两位和三位精确商品页指向同一厂家系列图：
严格 5.08 mm 节距；针脚截面 0.90×0.80 mm；厂家推荐孔 Ø1.50 mm，
本体深 10.00 mm、高 14.07 mm，长度 N×5.08 mm，另有拼接凸耳。
原板端子孔 Ø1.30 mm，且 F.Fab 使用 Phoenix 通用外形，不能直接替换。
用户现已明确采用 WJ500V，J7/J8/J9 七孔改为 Ø1.50 mm，保留 Ø2.60 mm 焊盘；
本地封装包含真实 10 mm 本体深度、拼接凸耳以及 0.50 mm 公差/0.25 mm 装配余量。
2026-10-10，J8/J9相对上一版左移2.5/上移3.94 mm，进线向左及网名不变；
本体上沿与ESP32估计下沿对齐。相关电源/CC入口重新布线，
实际DRC、机械门槛、四层CAM与钻孔对齐以当前manifest为准。

本地新增参考副本：

- `datasheets/lail-pm2.54-22p-l.pdf`：
  <https://atta.szlcsc.com/upload/public/pdf/source/20260526/5D0113ABF8CBF84CECFA584A6B591EE8.pdf>。
- `datasheets/lail-pm2.54-3p-l.pdf`：
  <https://atta.szlcsc.com/upload/public/pdf/source/20260526/F3D3938F29D8A6EAE0E0D2BECC10646B.pdf>。
- `datasheets/lail-pm2.54-6p-l.pdf`：
  <https://atta.szlcsc.com/upload/public/pdf/source/20260526/6E3B6C74074951B2DAB1C0B345B54AFF.pdf>。
- `datasheets/lail-pm2.54-7p-l.pdf`：
  <https://atta.szlcsc.com/upload/public/pdf/source/20260526/D00015F7937B9DDCB4D54B862B49BB0D.pdf>。
- `datasheets/lail-pm2.54-14p-l.pdf`：
  <https://atta.szlcsc.com/upload/public/pdf/source/20260526/E301E5DB0DC2B32F8C4DF97E16C2D142.pdf>。
- `datasheets/wj500v-5.08-series-candidate.pdf`：
  <https://atta.szlcsc.com/upload/public/pdf/source/20260331/4C76CA2ACF4350D93F8DAE8387658BA0.pdf>。

型号搜索可能返回 5.00 mm 的 KF301/KF128/DG301/WJ301V 或无关电阻。
不得仅凭搜索词“5.08”认定实际节距，也不得用“邮寄专用”条目满足商城供料要求。

### 未采用的 Phoenix 两位备选（适配前核对记录）

用户进一步提供的 [MKDS 1,5/ 2-5,08 商品页](https://item.szlcsc.com/5848879.html)
对应 Phoenix Contact **1715721 / C5183929**。
[国内装配目录](https://www.jlc-smt.com/lcsc/detail/C5183929.html)可查到精确型号。
厂家图纸第 2–3 页与实际 J8/J9 核对结果：节距 5.08 mm、推荐孔 Ø1.30 mm、
本体深 9.80 mm、进线侧到引脚中心 4.60 mm、端部到首脚中心 2.54 mm，
均匹配适配前的 Phoenix 两位封装。高度 13.80 mm、焊脚长 3.50 mm。
曾作为不改板的直接匹配候选；用户后续选择 WJ500V，不把这个备选放入采购 BOM。

这是固定式 PCB 螺钉端子，厂家不是把它定义为需要另配插头的插拔端子；
不能仅按商城“插拔式”分类采购额外配件。它只有两位，不能替代三位 J7。
此兼容性记录不代表用户选择了这个备选、已采购或工厂已批准插件焊接。
本地手册 `datasheets/phoenix-mkds-1.5-2-5.08.pdf`：
<https://atta.szlcsc.com/upload/public/pdf/source/20220930/5ACAA47A5DCD35493AC7A52B30D3CF94.pdf>。

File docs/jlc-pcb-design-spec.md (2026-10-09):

# 嘉立创工艺规格与 Minibox PCB 设计规范

核对日期：2026-10-09。适用于嘉立创国内站常规 FR-4 PCB 和 Minibox 四层板。
本文是相关工艺参数的摘要，不是工厂验收承诺；下单时以所选板厚、铜厚、
阻焊颜色、服务类型和工程审核为准。特殊工艺不能直接套用常规数值。

## 官方来源

| 来源 | 用途 |
|---|---|
| [PCB/SMT 工艺能力](https://www.jlc.com/portal/vtechnology.html) | 本文数值来源；分别查看“PCB工艺能力”和“SMT工艺能力”标签 |
| [层压结构说明](https://www.jlc.com/portal/server_guide_36372.html) | 核对四层叠层与可选结构 |
| [层压结构工具](https://tools.jlc.com/jlcTools/#/impedanceDefaultTemplate) | 选择订单对应结构 |
| [阻抗计算工具](https://tools.jlc.com/jlcTools/index.html#/impedanceCalculatenew) | 依实际介质、铜厚、参考层计算线宽/间距 |
| [阻焊设计说明](https://www.jlc.com/portal/server_guide_34402.html) | 细间距焊盘、阻焊桥及开窗审核 |
| [拼板指引](https://www.jlc.com/portal/server_guide_71.html) | 拼板、工艺边和分板方式 |
| [邮票孔拼板说明](https://www.jlc.com/portal/server_guide_10181.html) | 圆角板拼板与连接桥设计 |

已直接读取官方工艺能力页的 PCB、SMT 两张表。其余链接是该页提供的
进一步核查入口，不表示本文已验证所有可选工艺。不要用海外 JLCPCB
站点参数、促销价格或旧截图代替国内站当前订单规则。

## PCB 加工能力与推荐设计值

以下单位为 mm，铜厚单位为 oz；1 mil = 0.0254 mm。
“官方能力”可能是极限或收费选项；“项目推荐”是设计裕量，不是官方极限。

| 项目 | 官方能力/条件 | Minibox 推荐设计 |
|---|---|---|
| 层数、板料 | FR-4 支持 1–64 层 | 四层；选定实际叠层后再确定阻抗几何 |
| 板厚 | 0.4–4.8，实际以系统可选项为准 | 优先评估 1.6；先核对连接器、外壳及叠层 |
| 外/内层铜厚 | 多层外层 1/2；内层 0.5/1/2 | 不假定内层与外层等厚；载流按订单铜厚计算 |
| 多层 1 oz 最小线宽/线距 | 0.09/0.09；BGA 局部线宽可达 3 mil | 常规信号 0.20/0.20；细间距逃线需单独审核 |
| 多层 2 oz 最小线宽/线距 | 0.15/0.15 | 换铜厚必须重新检查线距、阻焊和阻抗 |
| 线宽公差 | ±20% | 不以极限线宽做大电流路径 |
| 1 oz 焊盘边到线边 | ≥0.10；多层 BGA 局部 ≥0.09 | 常规 ≥0.20；封装内部特殊间距单独确认 |
| 多层机械钻孔 | 最小 0.15，属非常规且费用高；推荐最小孔 ≥0.20 | 普通过孔钻孔 0.30 |
| 普通过孔焊盘 | 最小内/外径 0.15/0.25；外径比内径大 ≥0.10，推荐大 ≥0.15 | 外径/钻孔 0.60/0.30；径向焊环 0.15 |
| 过孔孔边间距 | ≥0.20 | ≥0.25，并保留制造裕量 |
| 多层有铜插件孔焊环，1 oz | 径向 ≥0.20 为建议值，极限 0.15 | ≥0.20；不得沿用过孔的 0.10 最小焊环 |
| 插件孔孔边间距 | ≥0.45 | ≥0.45；与普通过孔区分检查 |
| 插件孔成品孔径公差 | +0.13/−0.08 | 按引脚最大尺寸、装配余量核对最小成品孔 |
| NPTH 孔径公差 | ±0.10 | 按螺钉/定位柱最大尺寸和机械公差核对 |
| 多层有铜槽 | 最小宽 0.35、长 0.70；槽长宜 ≥2 倍槽宽 | 采用器件厂家推荐孔槽，确认 PTH 属性 |
| 无铜槽 | 最小宽 1.00 | 在唯一外形/加工定义中明确，不用禁布区代替 |
| 锣边铜到边/槽 | ≥0.20 | ≥0.50；所有铜层、焊盘、过孔均检查 |
| V 割铜到分板线 | ≥0.40 | ≥0.50；圆角板优先评估锣边/邮票孔方案 |
| 锣边尺寸公差 | 普锣 ±0.20；精锣 ±0.10，有额外条件 | 将公差计入插座、螺钉和外壳间隙 |
| 板厚公差 | ≥1.0 时 ±10%；<1.0 时 ±0.10 | 1.6 板按 1.44–1.76 评估配合 |
| 丝印字高/笔画 | ≥1.00 / ≥0.10 | ≥1.00 / ≥0.15，优先更大 |
| 丝印到露铜焊盘 | ≥0.15 | ≥0.20；不压焊盘、不被器件遮挡关键极性标记 |
| 阻焊桥，1 oz | 焊盘边距 ≥0.10：绿/红/黄/蓝/紫；≥0.13：黑/白 | 精细封装优先绿色；按实际开窗检查剩余桥宽 |
| 阻焊桥，2 oz | 焊盘边距 ≥0.20，各颜色 | 铜厚变化后重新检查 |
| 阻抗公差 | 官方表列 ±10%，收费 | USB 目标 90 Ω 差分；须确认结构、几何及订单阻抗服务 |

**焊环是径向宽度**，即外径与孔径之差的一半；不能把“外径大 0.10”
误填为“径向焊环 0.10”。过孔、插件孔、NPTH 的要求也不能互换。
官方表的插件孔/NPTH 尺寸公差不应直接当作所有过孔的通用公差。

官方能力表说明 2025 年 6 月起使用 LDI，焊盘与阻焊开窗按 1:1 制作，
也允许客户资料按单边 ≥0.02 设计后由工程调整。应结合实际封装与工厂
审核选择开窗，不能机械地给所有焊盘扩大同一个数值。
“焊盘边距门槛”不是最终阻焊桥宽；要看开窗扩张后的真实间隔。

过孔双面盖油/帐篷覆盖不等于树脂塞孔、填平和电镀盖帽。
普通四层板不默认包含盘中孔工艺；焊盘内钻孔、QFN 散热孔和细间距
焊盘附近的孔应确认吸锡、平整度、阻焊及钢网方案，未确认则避免盘中孔。

## SMT 服务：不要混用经济型与标准型

下表取自同一官方页面的 SMT 标签；封装代码沿用官网标记，下单须核对实际尺寸。

| 项目 | 经济型 | 标准型 |
|---|---|---|
| 焊接面 | 单面，贴片+插件 | 单/双面，贴片+插件 |
| PCB 层数 | 2/4/6 | 表列无限制，仍需订单审核 |
| 板厚 | 0.8–1.6 | 表列无限制，仍受 PCB 工艺约束 |
| 尺寸 | 10×10 至 470×570 | 70×70 至 460×510 |
| 数量 | 样板 ≤30(50) 大片，按平台具体方案确认 | 2 片起贴 |
| 出货方式 | 单板、邮票孔拼板 | 单板、邮票孔拼板、V 割拼板 |
| 工艺边 / Mark 点 | 官网表列不需要 | 需要 |
| 最小封装 / IC 引脚间距 | 0402 / 0.40 | 01005 / 0.35 |
| BGA 球间距 | 0.50 | 0.30 |
| 回流温度 | 255±5 °C，不可调 | 可选择低/中/高温范围，按器件与工艺确认 |
| SPI / AOI | 官网表列无 | 官网表列单独检测 |

100×88 mm、四层、正面装配在上述尺寸/层数范围内，
**但不意味着全部器件已获准贴装**。必须核对具体 MPN、立创料号、
库存、封装、焊接温度、极性、供应方式和插件/异形件工序。
LCD 母座、摇杆、MX 开关、电池座、端子及 USB 固定脚应逐项确认，
不能把“支持插件”理解为所有插件都自动完成或已包含费用。

标准型工艺边按官方 PCB 表中 SMT 说明至少 5 mm，Mark 直径 1 mm、
定位孔 2 mm，光点到板边 3.85 mm；光点距离口径、位置、数量及
阻焊避让应按工厂模板确认。经济型不能被误写为必须有这套工艺边。
工艺边通常加在拼板上，不得未经确认改动成品板外形。

## Minibox 四层布局与布线规则

### 叠层和回流

- F.Cu：器件及主要信号；In1.Cu：连续 GND；In2.Cu：电源及必要的 GND 参考区；
  B.Cu：辅助信号。`kicad_ex` 所有器件在正面，背面不新增器件。
- 连续地层不表示可以忽略天线禁铜、NPTH、孔槽和机械安全区域。
  ESP 天线禁区按模块数据手册在相关层实施。
- I2S 优先 F.Cu，参考相邻 In1 GND。B.Cu 旁边是 In2：
  若 In2 分割电源，底层高速信号不得跨分割；优先改回顶层，
  必要时规划连续 In2 GND 通道并验证其与主地的连接。
- 信号换层时安排附近 GND 回流过孔，连接实际参考地；距离按几何和
  信号边沿评估。不要把孤立、悬空的地过孔当作回流路径。
- GND 包地是辅助，不能替代完整参考平面。包地必须连主地、适当缝合，
  避免浮铜、狭长地颈和断续围栏；不得为包地强行压缩信号间距。

### 几何与信号质量

- **本项目禁止直角和锐角走线**，采用 45° 转角或圆弧。
  这是用户要求和项目规范，官方能力表没有将直角列为统一拒收条件。
  应检查同层相邻线段的真实转角、T 分支和铺铜尖角，不只看路由器设置。
- USB 差分对先布；保持成对、同层、相同参考、尽量相同换层次数，
  减少脱耦段、支线、无必要过孔和保护器件造成的不对称。
  Type-C 重复数据引脚要正确合并，不能横穿另一网络而短路。
- USB 的 90 Ω 是电气目标；当前候选 0.20 线宽/0.25 间距不是阻抗合格证明。
  必须按工厂叠层计算，再核对器件脚扇出、邻近铜和过孔。
  长度差预算按 USB PHY/保护器件资料和实际速率确定，不编造通用阈值。
- I2S 按信号上升沿而不是只按音频采样率评估；源端阻尼靠近真正驱动端，
  BCLK/WS 的分支尽量短，保持麦克风数据与扬声器数据方向正确。
  不强行把所有 I2S 线做等长蛇形线，按器件建立/保持时间制定预算。
- MAX 功放输出为开关功率信号，不是 I2S；扬声器两线均不是 GND。
  远离 INMP 麦克风、其供电和 I2S；核对麦克风声孔、板孔和装配方向。
- 降压输入电容、开关回路、电感、输出电容与反馈按芯片推荐布局；
  SW 铜面积控制在必要范围，反馈远离 SW，不交给自动布线器随意绕行。
- 3 A 路径不能默认使用 0.20 信号线宽。根据实际铜厚、层别、长度、
  温升、压降和热环境计算线宽/铜面与过孔数量；检查焊盘入口、保险丝、
  二极管、连接器及热焊盘的最窄瓶颈。引用 IPC-2152 等方法时记录条件。

### 布局与装配

使用器件真实 courtyard 和最大实体/装配包络，而不只看丝印或包围矩形。
核对键帽、电池、插头、螺钉、工具操作及外壳公差；正面放置本身不等于无冲突。
去耦靠近电源引脚、回地短；地铜不能侵入天线及声学/机械禁区。
不得为解决布线困难擅自增加电源管理器件或删掉必要保护和去耦。

## KiCad 规则落地和发布门槛

将上述规则落实到 Board Setup、网络类及必要的自定义 DRC 规则。
特别注意：**全局最小间距、网络类间距、封装局部覆盖是不同约束**；
网络类 0.20 不表示全局已设为 0.20。插件孔焊环/孔间距应单独检查，
不能仅凭全局过孔规则判断合格。丝印高度、笔画和到焊盘距离也须显式设置。
原载板 `kicad` 为避让异网焊盘，将普通焊盘局部铜间距设为 0.30 mm、
5V 焊盘保留 0.50 mm；走线相互间距仍为 0.20 mm。
这是该载板的实际设置，不是新增的工厂极限或 `kicad_ex` 已同步的声明。

核查时发现 `kicad_ex` 的全局文字门槛仍为 0.80/0.08，低于本文的官方
1.00/0.10；全局孔间距 0.25 也不能替代插件孔 0.45 检查。
这是待落实项，本文没有修改 PCB 规则或宣称现有布线达标。

发布前必须：重新填充全部铜区；ERC、DRC、未连接和原理图一致性检查；
额外检查直角、差分几何、信号参考层、载流瓶颈、机械干涉及真实 BOM。
所有问题修复；确实必要的例外须逐项记录理由并获确认，不得整类屏蔽。
**零 DRC 不等于阻抗、EMC、载流、声学或装配全部合格。**

工厂资料应包括四个铜层及所需阻焊/丝印/外形 Gerber、分开的 PTH/NPTH
钻孔文件、BOM、CPL/坐标、装配图、极性/Pin 1 说明、叠层及阻抗说明、
插件/异形件清单。钢网开口按工厂要求确认；审核 Gerber 和装配预览，
验证 CPL 原点、单位、正反面和旋转角，不直接假定 KiCad 角度适配工厂。

未完成布线或料号审核的导出件必须标记“草稿，不可生产”。
上述文档和 skill 的建立不改变 `kicad_ex` 尚未达到生产发布门槛的状态。

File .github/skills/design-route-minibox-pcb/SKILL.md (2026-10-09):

---
name: design-route-minibox-pcb
description: 'Design, route, review, and prepare Minibox KiCad PCBs for domestic JLC manufacturing, including four-layer grounding, I2S, USB, power routing, and front-side assembly.'
argument-hint: 'Specify the KiCad project and whether to inspect, place, route, or prepare manufacturing files.'
user-invocable: true
disable-model-invocation: false
---

# Minibox PCB 设计与布线

用于 Minibox PCB 设计、布局、布线、包地检查、嘉立创 DFM 和生产资料准备。
只完成用户授权的范围；检查任务不擅自改板，不自动下单、付款、commit 或 push。

## 首先读取

- [仓库说明](../../instructions.md)。
- [权威硬件接线](../../../docs/hardware-connections.md)。
- [嘉立创工艺规格与项目规范](../../../docs/jlc-pcb-design-spec.md)。
- 目标工程 README、原理图、PCB、项目规则及本地符号/封装库。

`kicad` 是原载板，`kicad_ex` 是独立集成方案；不得改错工程或互相覆盖。
工厂参数摘要有核对日期；生产准备前重读官方能力页并确认订单选项。
将工厂极限、工厂建议、项目推荐和实际已设置值分开，不凭记忆填写数字。

## 工作流程

1. **建立基线。** 查看 Git 状态，保留已有修改；确认实际 PCB、原理图、
   网络、已布线路径和层叠，不只相信生成脚本。将临时备份和报告放会话
   artifacts，避免生成器覆盖已有布线。执行需要的基线 ERC/DRC，
   记录违规、未连接和原理图一致性分别的数量。
2. **明确制造条件。** 选择国内站经济型/标准型、板厚、铜厚、颜色、
   表面处理、通孔/特殊工艺和装配面。经济型不强行要求标准型工艺边/Mark；
   标准型按工厂模板准备。精确 MPN、封装、库存和回流条件未确认不能发布。
3. **设置规则。** 根据工艺文档配置全局约束和网络类：常规信号
   0.20 mm 线宽/间距，普通 0.60/0.30 mm 过孔，铜到锣边至少 0.50 mm。
   单独落实插件孔焊环/孔间距、NPTH、丝印和阻焊规则；特殊封装例外
   逐项核查，不降低全板标准掩盖局部问题。电源和 USB 不沿用普通线宽。
4. **先布局后布线。** `kicad_ex` 元件全部正面；检查真实 courtyard、
   天线禁铜、声孔、键帽、电池、连接器插拔、螺钉/工具空间和外壳公差。
   去耦及降压关键元件先布局，避免用全局自动布局解决电源环路。
5. **先关键网后普通网。** 先降压局部回路、USB 差分和源端扇出，再 I2S、
   SPI 等关键网，随后控制、电源分配和普通网。每阶段保存并检查，
   不因后续失败丢弃已验证的布线。不以增加复杂电路代替合理布局。
6. **建立平面与回流。** 四层为 F.Cu 信号 / In1 GND / In2 电源及必要
   GND 区 / B.Cu 信号；按模块数据手册保留天线禁区。检查所有高速信号
   下方的真实参考铜，避免跨分割，添加有效回流过孔并清除浮铜。
7. **闭环验证。** 最终填铜后重新执行 ERC、DRC、原理图一致性和未连接
   检查；额外审查直角、参考层、差分、载流和装配。修复全部问题；
   合理例外需记录并确认，禁止批量忽略整类错误。
8. **准备资料。** 仅在发布门槛满足后导出 Gerber、PTH/NPTH 钻孔、
   工厂格式 BOM/CPL、装配/极性图和叠层说明；逐一检查 CAM 和贴装预览。
   未完成件明确标记“草稿，不可生产”，不能包装成最终下单包。

## 每次改板的同步交付

布局、封装、选型或引脚变化后，不能只保存PCB。同步生成来源、实际采购
型号/C编号BOM、CAD参考坐标、工厂专用CPL、中心/角度修正报告及装配图；
使用已验证的库原点/零角定义，从实际新版编号焊盘计算，不复制旧绝对坐标。
同步Gerber、钻孔、DRC、manifest和完整审核包，检查所有文件哈希配套。
工厂网页已保存结果仅对其绑定PCB哈希有效；新布局必须重新核对。

载板使用固定`kicad\assembly`和`kicad\fabrication`路径，历史交给Git，
不创建日期revision副本，不保留会混淆的旧下单文件。运行
`kicad\export_revision.py`完成整套导出，再用`kicad\package_review.py`
在更新渲染/文档后刷新审核包；脚本失败必须修复或明确交付阻塞。
不为同步资料重新生成/覆盖已布线PCB，不把零DRC当作生产批准。
下单操作中得到的通用经验（含sub-agent验证结果）回写下单skill，
具体ID与坐标修正留在工程交付文件。

## 必须执行的布线约束

- **不允许直角或锐角转弯**，使用 45° 或圆弧；审查真实连通几何、
  T 分支和铜区尖角，自动布线设置不是合格证据。
  这是用户要求，不编造成嘉立创统一拒收规则。
- I2S 优先顶层参考 In1 连续 GND。底层参考 In2，若分割电源导致断流，
  改走顶层或规划连通主地的 In2 GND 通道；换层就近提供有效地回流。
- 包地不能替代参考平面；两侧地铜必须实际连接、适当缝合，避免浮铜、
  细长地颈和不必要的电容负载。根据真实信号边沿分析，不只看采样率。
- 源端阻尼靠近真正驱动端；共享 BCLK/WS 缩短支线，检查 MIC_SD 与
  AUDIO_DIN 方向。按器件时序确定长度预算，不为了“等长”随意蛇形。
- USB 按实际工厂叠层设计 90 Ω 差分；线宽/间距未经计算不得宣称达标。
  保持对称参考和换层、减少脱耦/支线，检查 Type-C 重复脚合并、
  TVS 引脚连接和差分长度差。器件资料决定预算，不指定无依据阈值。
- 3 A 输入、二极管 OR、开关和降压供电按铜厚、压降、温升计算铜面/
  线宽/过孔数量，检查最窄入口和热连接，不能默认 0.20 mm。
- 降压关键回路遵守芯片推荐布局，SW 与反馈分离；功放输出远离麦克风
  和其信号/供电。不得把扬声器负输出接 GND。
- 全部贴片在正面不代表所有焊接仅需 SMT；插件/异形件与 USB 固定脚
  要逐项确认工厂工序、温度和费用。

## Windows / KiCad 操作

本机 KiCad 10：

```powershell
& 'C:\Program Files\KiCad\10.0\bin\kicad-cli.exe' sch erc --output '<会话目录>\erc.txt' .\kicad_ex\minibox-integrated.kicad_sch
& 'C:\Program Files\KiCad\10.0\bin\kicad-cli.exe' pcb drc --schematic-parity --output '<会话目录>\drc.txt' .\kicad_ex\minibox-integrated.kicad_pcb
```

替换 `<会话目录>` 为当前实际 artifacts 目录；其他工程替换输入文件。
先核对本机 CLI 选项。不要为 PCB 工作引入固件构建或额外测试框架。
命令成功退出不保证报告无违规，必须读取各类结果与未连接数量。
填铜在 PCB 编辑器或已验证的 KiCad API 流程完成，DRC 命令不替代填铜。

使用脚本时保留 PCB 所有未涉及内容和连接关系；本工程曾遇到
`pcbnew` 原生对象删除的 SWIG 所有权问题，避免对快照对象批量调用
`board.Remove()`。需要安全文件编辑时复用 `kicad_ex\kicad_sexpr.py`，
只修改目标项，重新加载并执行 DRC/一致性检查。
不要导入会立即执行生成的 `generate_project.py`，也不要对已布线板
运行布局生成器；同步生成来源时保留实际布线。

自动布线只能作为辅助。使用本地工具，不上传私有设计到在线路由服务，
关闭分析上传并保护关键手工布线；验证实际只用获准的信号层。
若自动布线未收敛，保留有效成果并明确剩余问题，不声称已完成。

## 交付判定

分别报告工厂规则核对、PCB 实际整改、DRC/未连接结果和待确认条件。
零 DRC 不能代替阻抗、热设计、EMC、装配公差或硬件实测。
不编造库存、工厂批准、最终报价或生产就绪状态。

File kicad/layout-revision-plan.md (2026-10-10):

# 载板纠错与重新发布实施计划

2026-10-10；只修改 `kicad` 模块载板，不修改独立集成工程或历史外壳。
以下对应用户十项要求。所有阶段都以实际保存 PCB 为依据；不使用布局生成器
覆盖已有布线。工厂审核、订单提交、付款与实物验收分别记录，不混为完成。

## 1. 基线与保护

- 检查 Git 状态；将实际 PCB、项目和基线 DRC 备份到会话 artifacts。
- 读取真实焊盘、网名、四层铜区、规则、采购型号及已核验的嘉立创库 datum。
- 保持板框 94.5×117 mm、R5、四个安装孔和上排键位置不变。
- 本工程无原理图，只能执行 PCB DRC/网络核验，不能宣称 ERC 通过。

## 2. 电气纠错

| 用户项 | 修改与验证 |
|---|---|
| 1 RTC | 正面左至右 CLK/INT/SCL/SDA/VCC/GND；SDA15、SCL16。交换 RTC 网络的功能名称，不改两条铜线几何；比较基线与新版端点、层、线宽和过孔。同步实际丝印、生成来源、固件及当前文档。 |
| 2 GPIO | MAX GAIN→42，MIC SD→21；ESP GPIO17 焊盘无网、无铜线。GAIN 默认高阻、SD/MODE47 和半双工时钟不变。 |
| 3 麦克风 | 正面左上至下 L/R=GND、WS39、SCK40；右上至下 GND、3V3、SD21。保持两个独立1×3母座及7.62 mm排距，重新布线和标注；逐焊盘检查，不镜像模块。 |

## 3. 机械布局

| 用户项 | 实施及边界 |
|---|---|
| 4 摇杆 | 向左贴近边缘；后续要求左侧距铜皮边界至少1 mm，按更保守的实体与焊盘均满足落实：中心(16.8,95.5)，实体至X=6 mm覆铜边界1.05 mm、焊盘铜约1.22 mm。只允许 Ø30 活动圈越界；较旧板左移3.95/上移2 mm以避螺丝方形，不改安装孔。 |
| 5 下排键 | 两键一起右移，保持19.05 mm节距和行距。这里“第二排中心”解释为整排中心，不是左下键中心。精确2/3需右移3 mm，会使18 mm键帽侵入右下螺丝区1.375 mm；无人响应澄清时优先不重叠，右移1.425 mm，保留0.20 mm方形区间隙，整排中心落在左上键约58%宽度处。不得宣称已精确达到2/3。 |
| 6 麦克风距离 | 固定Y=90.25 mm，按最终摇杆活动圈及四个18 mm键帽，数值最大化水平移动时的“最小边缘间隙”。保存最优X、目标间隙及比邻位置检验。 |
| 7 电源端子 | J8/J9左移并上移，J8真实本体上沿对齐ESP32估计本体下沿Y=45.97 mm；保持两组间距、针脚网络和进线朝左，J7保持朝右。检查实际封装凸耳、公差courtyard、铜到边及分界带。 |

## 4. 布线与验证

- 只删除/重布受移动或改网影响的网络；保留 RTC、屏幕和无关已验证布线。
- 信号0.20 mm，3V3 0.65 mm、5V 0.80 mm；普通过孔0.60/0.30 mm。
- 走线至异网焊盘至少0.30 mm，5V焊盘至少0.50 mm；不降低全局规则。
- 检查45°转弯、I2S实际In1/In2参考地、换层回流；填铜后执行全严重级DRC。
- 后续要求减少不必要地过孔：逐个候选删除/填铜，保留每个信号/电源换层
  3 mm内地回流、实际GND连通及I2S参考铜，不为减少数量删除必要回流孔。
- 新增/更新发布门槛：实际GPIO和麦克风六针、下排/螺丝区、摇杆实体在板内而
  活动圈可越界、麦克风水平最大最小间隙、电源本体上沿及左右进线。
- 固件增量构建，不烧录；复查所有当前接线说明，不修改历史记录来冒充新版本。

## 5. 嘉立创资料（用户项8）

- 用已有精确MPN/C编号和工厂库编号焊盘重新求新版绝对坐标与角度，保留逐孔残差。
- 全BOM/CPL包含17个物理件，J3拆成两个1×3；不把仅两个电阻的SMT清单用于全装配。
- 导出四层Gerber、阻焊/丝印/外形、PTH/NPTH，逐铜层和钻孔对位核验。
- 更新装配图、正反/斜视渲染、中文图例、中心/角度报告、manifest和全审核ZIP。
- 旧网站快照只属于旧PCB哈希；新版必须上传、预览、存档、刷新并读回。

## 6. 网站订单（用户项9）

- 优先复用已登录浏览器；不读取磁盘凭据，不模拟认证。
- 先核对国内站当前工艺和旧订单阶段。旧记录保留，优先新建新版，避免误取消。
- 新CAM上传只使用纯Gerber ZIP；制作5片、装配5片，所有17件/片均列入。
- 核对采购匹配、插件工艺、2D焊盘及3D朝向、中心/角度读回、实际报价与待审核项。
- 数量和费用范围已获用户授权；提交、取消或删除等具体动作仍遵循工具确认规则。
  不付款。认证或必要确认无法取得时，保存准备成果并明确阻塞，不能编造订单。

## 7. 发布（用户项10）

- 确保导出文件与最终PCB哈希配套；检查无凭据、无关修改或缓存混入。
- 将本次修改提交至当前main并普通push，不建分支、不强推、不改写历史。
- 若remote已前进，停下报告而不是擅自rebase。报告实际订单阶段和未完成项。

## 验收记录

最终实测值、DRC、CAM对位和文件哈希以 `assembly/manifest.json`、
`assembly/drc.json` 及嘉立创坐标报告为准。零DRC不代替载流、工厂工艺批准、
模块/键帽/摇杆帽实物配合或完整功能测试。

本轮地孔优化：41→23，删除18个；所有信号/电源过孔的地回流距离仍≤3 mm。
固件增量构建通过且未烧录。RTC两线及LCD各线与基线逐段几何相同。

网站进度：已复用登录并配置新版5片PCB表单、手动订单/生产稿确认。
PCB页面报价￥241.70，快递支付时核定；尚非全装配总价。
正式提交所需具体确认未能取得，因此未创建新版PCB/SMT订单，
未上传新版CAM/BOM/CPL至绑定订单，未核验新版网站3D或刷新读回。
旧未付款订单和旧哈希的网站快照保留，不作为新版验证。

独立GPIO审计：按用户指定官方v1.1 J1/J3表逐一核对实际载板44个焊盘，
44/44覆盖、错配0、缺失0、外设GPIO冲突0；载板J2对应官方J3。
GPIO1/2为ADC1_CH0/CH1；GPIO39–42占用四线JTAG信号，USB19/20保留。
仍待实物确认克隆板RGB48/官方RGB38差异及模块电气前提：
INMP441当前实际模块已由用户实测确认无需增加SD下拉，取消该待确认项；
PCB、固件和BOM不新增元件，不推断模块内部电阻配置。
GAIN42保持高阻或输出低，不能输出高；摇杆上端超过ADC标称有效范围须标定。
出处：[官方排针表](https://docs.espressif.com/projects/esp-dev-kits/zh_CN/latest/esp32s3/esp32-s3-devkitc-1/user_guide_v1.1.html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)、
[ESP-IDF GPIO](https://docs.espressif.com/projects/esp-idf/en/v5.3.5/esp32s3/api-reference/peripherals/gpio.html)、
[ESP32-S3规格书](https://www.espressif.com/sites/default/files/documentation/esp32-s3_datasheet_en.pdf)、
[INMP441手册](https://www.invensense.tdk.com/en-us/download-resource/ds-inmp441-00-inmp441-datasheet)。

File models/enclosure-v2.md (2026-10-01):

# 四件式外壳与打印

当前模型以 [`minibox-enclosure.scad`](minibox-enclosure.scad) 为准。坐标为 X 左右、Y 前后、Z 向上，单位 mm。整体外形约 **120 × 171 × 143**；前部操作台高 32。前面屏幕板竖直（与底面 90°），背部从其顶端以半径 111 的四分之一圆弧连接到高 32 的后侧直壁。两个 Ø12 Type-C 孔在后侧**直壁**，中心为 X=50/70、Z=21；不在底面或圆弧上。

| 部件 | SCAD `part` | 用途 |
| --- | --- | --- |
| 底壳 | `bottom` | 底面落地；左右开放导槽、底部止挡、接缝承托、合盖螺母座 |
| 前盖 | `lid` / `lid-print` | 键盘、摇杆、开关、音频及竖直屏幕窗口；后者是侧立打印朝向 |
| 圆弧后盖 | `rear-lid` / `rear-lid-print` | 单独的四分之一圆弧，四颗螺丝固定；后者是侧立打印朝向 |
| 屏幕固定板 | `screen-bracket` / `screen-bracket-print` | 两侧四个屏幕 M2.5 螺母座；后者**板面平放、柱子向上**打印 |

前盖与后盖在圆弧前段 Y≈97.96 分开，沿 Y 方向预留 **0.5 mm** 接缝；底壳在接缝下面有 1.5 mm 承托带。盖板周边继续使用 0.5 mm 侧向装配间隙。圆弧后盖在 Y=114、139 附近左右各有一颗 Ø3.2 通孔，与底壳上沿圆弧法线方向的 Ø4.7、深 5.2 胶粘螺母盲孔对齐；曲面螺丝头不设平底沉孔，宜使用带垫片的圆头螺丝。前盖原有四个水平合盖螺丝孔和沉孔保留。

固定板厚 **3 mm**，正反导筋之间的开放细槽宽 **3.6 mm**，板的两个表面在装配方向各留 **0.3 mm**；左右侧与盖板承托圈的净距至少 0.6 mm。两边从上方滑入、底部落在止挡上，**不需要将板塞进封闭方孔**。固定板底边 Z=25，底部模组的暂定最高包络 Z=20.6；中部没有从板底下垂到地板的支撑。板后部与屏幕背面暂定包络留约 1 mm 空隙，四个螺母柱朝前承托屏幕 PCB，安装面到盖板内面的法向距离仍为 6 mm。

屏幕右侧两颗螺丝之间预留约 **10 × 43 mm** 开口供排针与线束穿过；对应的右导筋在该高度中断，不会在开口后面形成挡板。右侧连接边至少 **4 mm**、顶部横梁 **6 mm**、板厚 **3 mm**，没有 1–2 mm 的悬空细丝。排针插头实际长宽和出线弯曲半径尚未实测：打印前应以实物校验 10 × 43 mm 的通道。

在 `models` 目录使用已安装的 OpenSCAD 导出并检查：

```powershell
python .\tests\check_enclosure.py --openscad "C:\Program Files\OpenSCAD\openscad.com" --output .
python -m unittest discover -s .\tests -p test_mesh_checks.py
```

命令生成四份装配坐标的 `.3mf`、四份摆好打印朝向的 `.stl`，以及各自的 `-y-up.stl` 兼容版本。3MF 保留装配坐标，不会自动落到打印平台；Y-up STL 仅给使用 Y 向上的查看器，不是普通 Z 向上切片文件。检查包含四件封闭连通网格、装配尺寸、固定板与底壳无实体碰撞、从上方插入的路径、前后盖接缝及右侧排针通路；名义接触的底部止挡除外。

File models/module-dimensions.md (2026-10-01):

# 模块尺寸与孔位

> **模型版本提示：** 下文记录的是此前 60° 斜屏、两件式外壳的历史尺寸，
> 不适用于当前打印。屏幕现为竖直、背部为四分之一圆弧，分为底壳、
> 前盖、圆弧后盖与屏幕固定板四件。当前结构、装配公差和导出命令见
> [`enclosure-v2.md`](enclosure-v2.md)；模块自身的孔距等实测数据仍可参考下文。

所有尺寸单位均为 **mm**。

## 1. 3 键位机械键盘模块

| 项目 | 规格 |
| --- | --- |
| 外形尺寸（长 × 宽 × 高） | 57.4 × 27.2 × 20.6 |
| 安装孔数量 | 4 |
| 安装孔直径 | Ø3 |
| 孔距（长向 × 宽向） | 53.34 × 22.86 |
| 四个安装孔的几何中心（平均位置） | 与模块几何中心一致 |
| 上方盖板开孔（长 × 宽） | 57.4 × 20.2 |
| 开孔距模块上缘 / 下缘 | 4 / 3 |
| 开孔距模块左缘 / 右缘 | 0 / 0 |
| 盖板至螺母安装柱顶的距离 | 5 |

模型按上缘朝屏幕（+Y）、下缘朝前端（−Y）安装。开孔中心比模块中心向下缘偏移 0.5 mm；四个安装孔仍以模块中心对称分布，不随开孔偏移。开孔使用上述名义尺寸，不再附加旧版每边 1 mm 的扩大余量。

5 mm 安装距离按柱顶至盖板内表面计算，不是至盖板外表面。当前盖板内表面 Z=25 mm，键盘柱顶 Z=20 mm，底板内表面 Z=4 mm，因此键盘柱高为 16 mm。为给新增水平合盖孔留位置，键盘整体前移 1.9 mm：模块及安装孔中心为 (84, 30.1)，开孔中心为 (84, 29.6)；开孔边界为 X=55.3–112.7、Y=19.5–39.7 mm。模块内部的孔距和窗口偏心量不变。

## 2. 摇杆模块

| 项目 | 规格 |
| --- | --- |
| 外形尺寸（长 × 宽 × 高） | 30 × 40 × 未知 |
| 安装孔数量 | 4 |
| 安装孔直径 | Ø3 |
| 孔距（长向 × 宽向） | 21 × 28 |
| 靠下缘一排孔中心距模块下缘 | 4.5 |
| 靠上缘一排孔中心距模块上缘 | 7.5 |
| 盖板开孔 | 圆孔 Ø29 |
| 圆孔中心距模块左缘 / 下缘 | 13.8 / 14.9 |
| 盖板内表面至螺母安装柱顶 | 5 |

长向 30 mm 对应左右 X，宽向 40 mm 对应前后 Y；上缘朝屏幕（+Y），下缘朝前端（−Y）。孔组中心不等于模块中心：两排孔的平均位置为距下缘 18.5 mm，即相对模块中心向下缘偏 1.5 mm。左右孔距保持 21 mm，左右边距尚未实测，暂按左右居中（各 4.5 mm）布置。

圆孔中心相对模块中心为 X 偏左 1.2 mm、Y 向下缘偏 5.1 mm，不能套用孔组中心。为给新增水平合盖孔留位置，摇杆整体前移 1 mm：当前模块中心 (31, 29)，孔组中心 (31, 27.5)，圆孔中心 (29.8, 23.9)；四孔位置为 X=20.5/41.5、Y=13.5/41.5 mm。Ø29 圆孔使用名义尺寸，不额外扩大；它的左侧投影超出 PCB 左缘 0.7 mm，这是给定尺寸的结果。

柱顶同样按距盖板内表面 5 mm 定位：柱顶 Z=20 mm、底板上方柱高 16 mm。模块外形保持原位，仅孔柱及其螺母孔按偏心孔组布置，圆孔独立定位。

## 3. 4 英寸 TFT 屏幕模块

| 项目 | 规格 |
| --- | --- |
| 驱动芯片 | ST7796 |
| 分辨率 | 480 × 320 |
| 显示区域（长 × 宽） | 55.68 × 83.52 |
| 模块尺寸（长 × 宽 × PCB 加屏体厚度） | 61.74 × 108.04 × 5 |
| PCB 厚度 / 屏体厚度 | 2 / 3 |
| 横屏显示区距 PCB 左缘 / 右缘 | 10 / 14.52 |
| 安装孔数量 | 4 |
| 安装孔直径 | Ø3 |
| 孔距（长向 × 宽向） | 54.9 × 101.9 |
| 盖板可视窗口外接尺寸 | 85.52 × 57.68 |
| 窗口直边相对显示区域的外扩量 | 上下左右各 1 |
| 窗口中心相对 PCB 中心 | 横向左移 2.26；纵向暂按居中 |
| 盖板可视窗口四角半径 | R6 |
| 安装耳承托面至盖板内表面的法向距离 | 6 |
| 屏体正面至盖板内表面的预留 | 1，供亚克力薄膜及装配 |

横屏 PCB 左缘 X=5.98 mm，显示区 X=15.98–99.50 mm，中心 X=57.74 mm，而非 PCB 中心 X=60 mm。窗口直边外接范围为 **X=14.98–100.50 mm、沿斜面 43.78–101.46 mm**；PCB 和四个安装孔不随窗口左移，横向孔位仍为 X=9.05/110.95 mm。显示区上下边距未提供，暂保持纵向居中，各 3.03 mm。

安装耳承托 PCB 背面，其顶面至盖板内表面的 **6 mm 沿盖板法线测量**，由 PCB 2 mm、屏体 3 mm、薄膜与装配预留 1 mm 组成，不是全局竖直方向 6 mm。斜面外表面法向坐标为 0，盖板内表面为 −3 mm，安装耳顶面为 −9 mm，PCB 正面为 −7 mm，屏体正面为 −4 mm。四个安装耳和盲孔随厚度同步定位，其他模块的暂定 PCB 厚 1.6 mm 不变。薄膜厚度与胶层合计需容纳在这 1 mm 预留内，未生成薄膜卡槽。

## 4. ESP32 开发扩展板模块

| 项目 | 规格 |
| --- | --- |
| 实测外形尺寸（长 × 宽 × 高） | 68 × 58 × 未知 |
| 旋转 90° 后安装外形（左右 X × 前后 Y） | 58 × 68 |
| 安装孔数量 | 4 |
| 安装孔直径 | Ø3 |
| 实测孔距 / 旋转后孔距（X × Y） | 58 × 49 / 49 × 58 |
| 四孔几何中心 | 与模块几何中心重合 |
| 螺母安装柱高度（底板内表面以上） | 5 |
| 与其他模块及独立固定座的间距 | 至少 10，贴侧壁屏幕斜撑单列 |
| 与贴侧壁屏幕斜撑的安装间隙 | 至少 2.5，按紧凑侧边单独检查 |
| 与后面板直壁段的间距 | 至少 20，当前 20.9 |
| 与右侧面包板的边缘间距 | 10 |
| 与相应平直侧壁的间距 | 6.1；底部圆角处另检查至少 1 |
| 左右位置 | 左侧 ESP32、右侧面包板，前缘对齐 |

模块平放在键盘和摇杆后方的底板上，不另开盖板窗口。按要求旋转 ESP32 90°，**外宽保持 120 mm，不加宽**；侧壁间距经确认可以收紧后，改为真正左右并排，取消原来的前后串排方案。ESP32 当前中心 **(37.5, 96.7)**，完整外形范围 **X=8.5–66.5、Y=62.7–130.7 mm**；面包板位于其右侧，X 从 76.5 mm 开始，两板相隔 10 mm，前缘均为 Y=62.7 mm。

前部最后方的中排固定座止于 Y=52.7 mm，两板前缘与它相隔 **10 mm**；距摇杆 PCB 后缘 13.7 mm、键盘 PCB 后缘 19 mm，这些差异来自前部模块本身长短不同，不额外叠加多圈余量。上方开关和音频模块按实际三维包络避让，不再将它们的整个平面投影都留空。

ESP32 至后壁的目标间距为 **20 mm**，两板之间及前方仍为 10 mm。外壳深度为 **154 mm**，后侧平直内壁 Y=151.6 mm，距 ESP32 后缘 **20.9 mm**；不足 1 mm 的额外值来自深度取整，并给后壁底边圆角留出余量。后面板距离按直壁段计算，侧壁转角采用紧凑侧向余量。面包板短 21 mm，其后侧自然多出相应空间。后排安装座保持 10 mm 厚，75° 曲面最低根部约 Z=48.99 mm，不伸到底板。贴侧壁屏幕斜撑检查至少 **2.5 mm** 安装空隙，根部内收嵌入侧壁，避免为了支撑而抬高屏幕。**自身安装柱及承托底面属于安装接触**，ESP32 柱高保持 5 mm。

四孔位置为 **X=13/62、Y=67.7/125.7 mm**，孔距随 PCB 一起旋转为 X 向 49 × Y 向 58 mm，不改变实测孔距。底板内表面 Z=4 mm，柱高 5 mm，因此柱顶 Z=9 mm。安装座与底板实体相连，仍使用 Ø4.7 × 深 5.2 mm 胶粘螺母孔：孔底 Z=3.8 mm，进入底板 0.2 mm，底下保留 3.8 mm 实体。

**该模块建议使用 M2.5 × 6 mm 短螺丝，不沿用其余模块的 10 mm 螺丝。** 按暂定 PCB 厚 1.6 mm，6 mm 螺丝拧入约 4.4 mm，适合 5 mm 螺母；10 mm 螺丝会在此浅孔顶底。实际板厚、垫片和螺母顶部位置需复核，模型会拒绝超出浅孔余量的螺丝长度参数。

ESP32 板高、插接后的开发板堆叠高度、排针和接插件外伸量尚未提供。预览暂按 PCB 厚 1.6 mm、PCB 上方器件高 10 mm 显示，即顶部 Z=20.6 mm；这是待复测的包络，不代表真实板卡高度。

## 5. 后壁 Type-C 面板母座

| 项目 | 规格（mm） |
| --- | --- |
| 数量 / 排布 | 2 个，后壁中央横向排布 |
| 底壳开孔直径 | Ø12，光孔，不打印螺纹 |
| 两孔中心距 | 20 |
| 母座螺纹段直径 / 长度 | Ø10.5 / 14.5 |
| 外侧头部直径 / 厚度 | Ø13.8 / 2 |
| 六角螺母螺纹规格 | M11 |
| 六角螺母外径 / 厚度 | 14 / 3 |

孔轴线垂直后壁，左右关于外壳中线对称：当前孔中心 X=50/70 mm、Z≈62.06 mm（后壁总高的一半），外壁 Y=154 mm，内壁 Y=151.6 mm。未额外开沉孔，后壁厚度保持 2.4 mm。

安装方向按头部在外、螺纹段伸入壳内、螺母在内设置：螺纹段内端到 Y=139.5 mm，外侧头部伸至 Y=156 mm。Ø12 孔相对 Ø10.5 螺纹段每侧留 0.75 mm，Ø13.8 头部压边每侧只有 0.9 mm；这是所给尺寸的直接结果，需确认实物头部能可靠压住孔边。

“六角外径 14 mm”尚未区分对边或对角尺寸，尺寸记录保持原值。干涉检查保守按对边 14 mm 换算外接圆 Ø16.17 mm、厚 3 mm 的包络；不据此更改实际开孔。预览仅涵盖已给出的头部、螺纹及螺母，不包含未提供尺寸的接线端和线缆弯曲空间。

## 6. 屏幕下方开关、麦克风与喇叭

三孔位于同一块 **60° 平直斜面**，不是弯曲过渡面，孔轴垂直该斜面。沿斜面的距离以操作台与斜面的理论交点为零，向屏幕方向为正。

| 从左到右 | 开孔直径 | 本体已知尺寸 | 孔中心 X / 沿斜面距离 | 孔边至屏幕完整 PCB 下缘 |
| --- | --- | --- | --- | --- |
| 喇叭 | Ø23.5 | 本体 Ø23 | 30 / 22 | **8** |
| 麦克风 | Ø5 | 未提供 | 60 / 22 | 17.25 |
| 开关 | Ø21 | 未提供 | 90 / 22 | 9.25 |

三个孔中心在外表面的全局 Y=69 mm、Z≈47.05 mm。按最新要求，孔边到屏幕完整 PCB 边缘沿面测量的最小间距改为 **8 mm**，不是只避开显示窗口。喇叭孔下缘距下部圆弧切点约 4.48 mm，三个孔均完全落在直线斜面内。左右相邻孔边之间分别留 15.75 mm 和 17 mm，所有开孔距上盖外缘至少 2 mm。

屏幕沿斜面的中心现在为 **72.62 mm**（基准中心 46 mm 加偏移 26.62 mm）。相对中心为 99 mm 的高版沿面下移 **26.38 mm**，全局向前 13.19 mm、降低约 22.85 mm；窗口、PCB 和四个安装耳同步移动。屏幕完整 PCB 下缘到喇叭孔边为 **8 mm**。斜面长度缩为 **111 mm**，角度仍为 60°；总高从 146.65 降至 **124.13 mm**。宽 120 mm、深 154 mm 不变，其他模块和三个功能孔位置不变。

屏幕可视窗口外接尺寸为 **85.52 × 57.68 mm**（相对可视区域上下左右各加 1 mm），中心相对 PCB **左移 2.26 mm**。保留此前指定的 **R6 圆角**，在斜面局部平面内定义并贯穿 3 mm 盖板。1 mm 余量指四条直边；R6 圆角仍会遮住显示区域的部分角部，不能据此声称完整矩形显示区四角均无遮挡。窗口下直边距喇叭孔边约 10.03 mm，完整 PCB 下缘距孔边仍为 8 mm。

仅按已给尺寸生成通孔，不擅自添加开关锁止槽、喇叭卡扣或麦克风固定柱。喇叭与孔径差 0.5 mm，**通孔本身不能固定喇叭**，需实物确认压边、胶粘或支架方案。内部包络暂用：喇叭 Ø23 × 深 10 mm，麦克风 Ø5 × 深 10 mm，开关 Ø21 × 深 20 mm，均自盖板内表面向内；这些深度及开关/麦克风本体直径不是实测值，不含接线空间。

## 7. 面包板

| 项目 | 规格 |
| --- | --- |
| 外形尺寸（左右 X × 前后 Y × 高） | **35 × 47 × 未知** |
| 安装孔与固定方式 | 未提供，不生成固定孔 |
| 位置 | 旋转后的 ESP32 扩展板右侧，前缘对齐 |
| 中心 X / Y | 94 / 86.2 |
| 外形范围 | X=76.5–111.5、Y=62.7–109.7 |
| 左缘至 ESP32 完整 PCB 右缘的间距 | **10** |
| 与其他模块及非自身固定结构的间距 | **至少 10**，按暂定包络检查 |
| 与右侧平直内壁的间距 | **6.1**，底部圆角处另检查至少 1 |

面包板安装区域位于底板内表面 Z=4 mm。预览和避让检查暂按 **10 mm 高**的矩形实体（顶部 Z=14 mm）预留；这是未实测的占位高度，不包含插入元件、跳线和可能的胶垫。未添加卡扣、螺丝孔或额外支柱，实物高度与固定方式确定后需重新检查。

ESP32 旋转后，两板与中间通道合计占宽 103 mm。120 mm 外宽扣除两面 2.4 mm 壁厚后净宽 115.2 mm，剩余 12.2 mm 分给两侧，各留 **6.1 mm**，实现 **ESP32 左、面包板右**真正并排。6.1 mm 是平直内壁间距，底部 R9.6 内圆角会向内占用一部分；另对完整面包板体积及至少 1 mm 的侧向余量检查实际壳体，不能把 6.1 mm 当成最低处的真实间隙。两板之间的 10 mm 通道不放置支柱。

当前底壳与盖板总深度均为 **154 mm**，保持并排布局；深度由较长 ESP32 板、前部固定座和至少 20 mm 后壁间距共同决定。

## 螺丝与螺母

| 类型 | 规格 | 内径/直径 | 外径 | 长度 |
| --- | --- | --- | --- | --- |
| 螺母 | M2.5 | 内径 2.5 | 4.5 | 5 |
| 螺丝 | M2.5 | 直径 2.5 | — | 10 |

ESP32 扩展板的 5 mm 安装柱另建议配 M2.5 × 6 mm 螺丝，尚非已提供的实物规格。

## 外壳设计

OpenSCAD 参数化模型见 [`minibox-enclosure.scad`](minibox-enclosure.scad)。

- 按手绘图布局：左侧摇杆、右侧 3 键键盘，上方为横屏。
- 当前整体尺寸约为宽 **120 × 深 154 × 高 124.13 mm**，操作台高 28 mm。前部固定座至板边 10 mm、ESP32 后缘至后面板直壁 20.9 mm。屏幕 PCB 到喇叭孔边间距为 8 mm，窗口 R6 圆角，统一采用 `$fn=32`。
- 屏幕斜面与水平面夹角为 60°；斜面两端的直线延长线夹角为图中的 120°。
- 底部四个三维角采用真正的 **R12 球面过渡**，不再用三个圆柱切面相交形成尖角。球心距相邻两侧外壁和底面各 12 mm，内球面同心偏置为 **R9.6**，保持侧壁标称厚 2.4 mm；平直底板厚 4 mm。球面与底边圆柱圆角及竖向圆角相切，外壳宽度、深度、总高不变。两处 120° 转折仍为 R10，前后上缘仍为 R6。
- 外壳为底壳和上盖两件式。摇杆和键盘柱顶 Z=20 mm、柱高 16 mm，距盖板内面 5 mm。屏幕四个安装耳厚 10 mm，顶面到盖板内表面沿法线为 6 mm；斜撑按 **75°（相对水平面）**计算，10.65 mm 悬挑对应至少 39.75 mm 下降量，根部厚 2 mm；下排根部默认 Z≈12.41 mm，12 mm 屏体参数回归方案约 Z=7.91 mm。根部横向完全嵌入 2.4 mm 侧壁，而非多占用壳内 1.2 mm；斜撑与底部模块按完整包络留至少 2.5 mm 安装空隙。上盖没有模块固定柱。
- 上盖有横向屏幕窗口、左侧摇杆 Ø29 偏心圆孔、右侧键盘偏心长方形窗口，以及屏幕下方喇叭、麦克风、开关三个圆孔。共 **6 个**合盖台阶孔（四角和控制模块后侧左右各一个）全部位于水平面、轴线竖直；三个新增功能孔位于平直斜面而非圆弧。
- 后排两个固定座均为 **10 mm 厚安装座 + 约 62.14 mm 高平滑曲面**，从盖板内面向下共约 72.14 mm，连接左右侧壁而不伸到底板。曲面两端逐渐转为竖直，最缓处也达到 **75°**。前角座及中间两座仍直达底板。角座前后宽度 7 mm，中间座宽度 7 mm，Ø4.7 螺母孔周围至少保留 1.15 mm 实体。
- 模块支柱与壳壁或合盖角座之间不超过 5 mm 的窄缝用实体过渡填满，包括键盘右侧支柱到侧壁的缝隙。填充跟随各模块柱高做到柱顶，不侵入模块包络，也不填掉必要的装配、活动间隙。
- 底壳上方完全敞开，开口切削体向壳外延伸，避免共面布尔运算留下零厚度面或预览“薄膜”；支撑结构与外轮廓实体相交裁剪，不破坏底部圆角。
- 横屏后，PCB 尺寸为 X 向 108.04 × 斜面方向 61.74 mm；孔距对应为 101.9 × 54.9 mm；显示区域对应为 83.52 × 55.68 mm。
- 壁厚 2.4 mm、底厚 4 mm，上盖厚 3 mm；周边侧向装配间隙改为每侧 **0.5 mm**。上盖四角采用 **R6**，底壳配合开口采用同心 **R6.5**，避免圆角处的间隙变小。保持外壳宽度、深度、总高和底部圆角不变。
- 六个合盖孔的上层为 **Ø4.5 × 深 1.4 mm** 的平底螺丝头沉孔，下层为 **Ø3 × 厚 1.6 mm**，不是锥形沉头。胶粘螺母孔保持 **Ø4.7 × 深 5.2 mm**；除 ESP32 外，尾端盲孔总深 8.8 mm，适配沉入后拧入约 8.4 mm 的 M2.5 × 10 mm 螺丝。ESP32 仍单独使用 5.2 mm 浅盲孔和短螺丝。
- 键盘中心为 X=84、Y=30.1 mm，摇杆中心为 X=31、Y=29 mm。两模块左右仍留 9.3 mm；键盘距相邻固定座至少留 2 mm 平面余量，摇杆左沿距左前角座外缘 2.5 mm。避让检查使用完整模块包络及额外 2 mm 平面余量。
- 键盘窗口按补充尺寸改为 **57.4 × 20.2 mm**，上缘留 4 mm、下缘留 3 mm、左右为 0 mm，中心朝前偏移 0.5 mm。完整 PCB 外形仍用于内部避让，穿盖部分包络按偏心窗口设置。键盘按总高 20.6 mm 预留包络，柱高调整后默认顶端 Z=40.6 mm，比操作台高 12.6 mm。
- ESP32 扩展板旋转 90° 后在底板左侧，由 4 个高 5 mm 的安装柱固定；右侧并排预留 35 × 47 mm 面包板，两板相隔 10 mm，平直侧壁间距各 6.1 mm，前部间距 10 mm、后壁间距至少 20 mm。其他模块与独立固定座仍按 10 mm 检查，贴侧壁屏幕斜撑单独按 2.5 mm 安装间隙检查。
- 后壁按补充要求默认开两个 Ø12 Type-C 母座孔，中心距 20 mm；原有可选 16 × 10 mm 走线孔仍默认关闭，可通过 `enable_cable_opening = true` 单独开启。

### 基础配置

| 配置 | 当前值（mm，角度除外） | SCAD 参数 |
| --- | --- | --- |
| 外壳宽度 | 120，不加宽 | `case_width` |
| 外壳深度 | 154，按并排布局及至少 20 mm 后壁间距计算 | `case_depth` |
| 外壳总高 | 约 124.13 | `rear_height` |
| 操作台外表面高度 | 28 | `deck_height` |
| 盖板厚度 | 3 | `panel_thickness` |
| 底壳底板厚度 | 4 | `floor_thickness` |
| 底壳侧壁标称厚度 | 2.4 | `wall` |
| 底部外球角 / 边圆角半径 | 12（原 6 的两倍） | `bottom_radius` |
| 底部内球角半径 | 9.6，同心偏置，安装座附近允许加厚 | `bottom_radius - wall` |
| 前后上缘外圆角半径 | 6 | `rim_radius` |
| 上盖四角半径 | 6 | `lid_corner_radius` |
| 两处转折外轮廓圆弧半径 | 10 | `bend_radius` |
| 斜屏角度 | 60° | `slope_angle` |
| 斜面长度 / 屏幕相对基准沿面偏移 | 111 / 26.62 | `slope_length` / `screen_shift_along` |
| 三个功能孔至屏幕 PCB 最小距离 | 8，喇叭孔边处取到该值 | `screen_port_clearance` |
| 屏幕窗口外接尺寸 / 四角半径 | 85.52 × 57.68 / R6 | `tft_view` / `tft_window_clearance` / `tft_window_radius` |
| 显示区距 PCB 左缘 / 右缘 | 10 / 14.52 | `tft_view_side_margins` |
| 窗口横向偏心量 | −2.26（左移），按左右边距推导 | `screen_window_offset` |
| 窗口每方向合计外扩量 | 2，即每侧 1 | `tft_window_clearance` |
| 屏幕 PCB 厚度 / PCB 上方屏体厚度 | 2 / 3 | `screen_pcb_thickness` / `screen_stack_above_pcb` |
| 屏体至盖板内面预留 | 1，薄膜与装配共用 | `screen_front_clearance` |
| 屏幕承托面至盖板内面的法向距离 | 6 | `screen_mount_gap` |
| 所有斜撑最小坡角（相对水平面） | 75°，四个屏幕斜撑和两个后排曲面支撑 | `support_angle` |
| 盖边侧向装配间隙 | 每侧 0.5，两侧共 1 | `joint_clearance` |
| 全周承托台阶内伸量 | 1.5 | `support_lip_width` |
| 承托台阶实体厚度 | 1.5 | `support_lip_thickness` |
| 承托台阶顶面距当地外表面 | 3，等于盖厚 | `panel_thickness` |
| 合盖螺丝数量 | 6，全部位于水平面 | `shell_fasteners()` |
| 盖板通孔 / 头部沉孔直径 | 3 / 4.5 | `lid_screw_diameter` / `lid_counterbore_diameter` |
| 沉孔深度 / 下层剩余厚度 | 1.4 / 1.6 | `lid_counterbore_depth` |
| 所有开孔距盖板外边缘的最小余量 | 2，包含圆角及沉孔外缘 | `lid_min_edge` |
| 后壁 Type-C 孔径 / 中心距 | 12 / 20 | `typec_hole_diameter` / `typec_hole_spacing` |
| 面包板左右 / 前后尺寸 | 35 / 47 | `breadboard_size` |
| 两块底部模块的边缘间距 | 10 | `floor_board_gap` |
| 两块底部模块至其他模块和独立固定座的间距 | 至少 10，自身安装支撑除外 | `floor_module_clearance` |
| ESP32 至后壁的目标间距 | 至少 20，当前直壁段 20.9 | `esp32_rear_clearance` |
| 两板外侧至相应平直侧壁 | 各 6.1，居中分配剩余宽度 | `floor_side_inset - wall` |
| 内圆角处最小侧向检查余量 | 1 | `floor_side_clearance` |
| 贴侧壁屏幕斜撑至底板模块的安装间隙 | 至少 2.5 | `screen_brace_clearance` |
| 后排两个短安装座实体厚度 | 10，保留盲孔底厚 1.2 | `rear_mount_depth` |
| 后排短座下方曲面高度 / 水平伸出 | 约 62.14 / 11.1，左右镜像 | `rear_brace_rise()` / `shell_mount_columns()` |
| 后排曲面最小坡角（相对水平面） | 75°，分段面不小于此值 | `brace_ease()` |
| 后排两个固定座最低侧壁根部高度 | 约 48.99 | `column_root_z()` |
| 面包板暂定占位高度 | 10，待实测 | `breadboard_height` |
| 全局圆周分段数 | 32 | `$fn` |

厚度指平直区域的标称值；圆角、安装柱及加强填充处属于实体过渡，并非处处等厚。底部四个球角及侧壁由同一个凸包生成：底部球心位于 Z=12 mm，另一组同半径球体位于外壳顶部以上，让球面赤道与竖直侧壁共用轮廓。内外球心相同，通过半径差保持壳厚；底板平直区另保留 4 mm，安装座连接处允许更厚。上盖的顶部曲线不随底部球角改变。

按最新要求，全局精度提高为 **`$fn = 32`**。球面、圆孔、R6 圆角和侧面圆弧均使用此设置；侧面圆弧按角度分配分段，最少 4 段。球面网格包含两极和赤道，保持底面 Z=0 和平直底厚 4 mm。圆孔为 32 边形，对边尺寸约为标称直径的 99.52%（Ø3 约 2.986 mm、Ø12 约 11.94 mm）；仍应结合打印公差试装。

### 上盖配合与承托

上盖平面投影外廓宽 114.2 mm、前后跨度 141 mm；对应底壳配合开口宽 115.2 mm、跨度 142 mm，前后左右各留 0.5 mm。尺寸以顶部配合开口为基准，不以底壳外尺寸为基准。圆角也采用平行偏置，R6 上盖对应 R6.5 开口。

全周台阶从配合开口向内伸 **1.5 mm**，扣除 0.5 mm 侧向间隙后，上盖有效搭接宽度为 1 mm。台阶顶面沿当地盖板法线位于外表面下 **3 mm**，水平段为垂直下 3 mm；台阶实体厚 **1.5 mm**，即占据表面下 3–4.5 mm 的带状实体，与壳壁和圆角过渡实体连成一体，不是零厚度面。承托面与盖板底面贴合，不再留 0.5 mm 垂直悬空间隙；0.5 mm 是周边防卡死的侧向装配间隙。

合盖孔位为 X=9/111 mm，前排 Y=11 mm、中排 Y=49.2 mm、后排 Y=143 mm。前排和中排在低位水平板，后排在顶部水平折边；中排螺丝头及余量范围止于下部圆弧起点之前。四角 Ø4.5 沉孔距 R6 外缘的最小实体余量约 2.25 mm；所有模块窗口、Ø3 通孔及 Ø4.5 沉孔均按至少 2 mm 外边距检查。

后排短座顶面 Z≈121.13 mm，10 mm 厚实体下接平滑曲面，最低根部 Z≈48.99 mm。Ø4.7 螺母孔深 5.2 mm，螺丝尾端让位盲孔总深 8.8 mm，最深孔下仍留 1.2 mm 实体。螺母规格和盖板台阶孔不变；支撑保持 75°，不伸到底板。

曲面保留两端切线竖直的三次缓动轮廓，其最大导数为 1.5，故高度按“水平伸出 × 1.5 × tan(75°)”计算，确保最缓处达到 75°，而非只让首尾连线达到 75°。默认随 `$fn=32` 使用 32 段，逐段检查坡度；0.2 mm 层高时每层外伸上限约 0.054 mm。支撑从已打印侧壁逐层长出，但具体材料、线宽、散热及切片设置仍需确认，不保证所有打印参数下都无需辅助支撑。

导出 STL 前，将模型顶部的 `part` 设置为：

- `"bottom"`：底壳
- `"lid"`：上盖（装配坐标）
- `"lid-print"`：上盖侧立并落在 Z=0 平台上
- `"bottom-y-up"`：底壳转为 Y 向上坐标，供采用该坐标约定的网站使用
- `"lid-y-up"`：将 `lid-print` 的侧立姿态转为 Y 向上坐标
- `"assembly"`：装配预览
- `"exploded"`：上盖向上移开的拆分预览

`show_modules = true` 显示半透明模块空间包络，包含 PCB、面包板占位、器件主体、伸出上盖的操作部分及两个 Type-C 母座的头部/螺纹/螺母，仅用于 F5 预览，不会导出到 STL。

### 盖板连续性与预览缝线

盖板由同一个连续的 3 mm 厚折弯带状实体裁切外形，再统一扣除开孔；不是多片面板拼接。检查包括单一连通分量、封闭流形、每条网格边恰有两片相邻面、面片方向一致，以及左右连续边条跨越两处转折的实体探针。

装配模式里盖板与底壳周边的 **0.5 mm 安装缝是设计间隙**，不是盖板断裂；曲面上的明暗分段也不等于透明裂缝。非凸侧面挤出及平面掩模显式设置 `convexity=10`，提高 F5 预览的遮挡计算深度，不改变实体。可用 `part="lid"` 单独查看盖板，并用 F6 或 STL 判断几何，不能仅凭装配预览中的接触面细线判断断裂。

### 网格精度与底壳缺陷修正

旧底壳虽然在精确坐标下通过边共享与连通检查，但包含 **7 个三点共线的零面积三角面**及亚微米级短边。旧检查仅判断三顶点是否不同，漏掉了共线退化；仅在 3MF 中保留更多小数也不能修复源网格。上传端舍入或合并近邻顶点后，这些碎面可能进一步形成坏边或开放轮廓。尚未在原检测网站复测，不能据此认定网站的四项报告均由同一原因触发。

修正方式为：球形底角和竖直侧壁改为单一凸包，不再拼合两套近重合轮廓；底部圆角只由球形包络定义，不再与侧面另一个采样圆角重复裁切；安装柱补缝凸包的矩形端点向固定座内部缩进 0.02 mm，保持实体交叠并避开重合边；侧面圆弧坐标在布尔运算前稳定到 0.000001 mm，消除相切端点的三角函数误差。外形标称尺寸、孔位、壁厚和装配朝向不变，不用自动补洞来封住功能孔。

检查现同时覆盖零面积/重复面、STL 法线与顶点绕序一致性、按共享边连通的单壳体、每个顶点周围的单一闭环，以及正体积。额外将导出坐标分别舍入至小数点后 6、4、3 位，再检查退化面、边/顶点流形、壳体数量及面片翻转，防止精度变化重新引入缺陷。底壳与盖板的 STL、Y 向上 STL 和原始装配坐标 3MF 均使用这些检查。

修复版本另经 MeshLab 独立检查：每个文件 1 个连通壳体，边界边、非流形边、非流形顶点、未闭合孔洞、自相交面均为 0。这里的“孔洞”指网格没有封闭的边界，不是两个 Type-C 设计通孔。检测器自身有 10 个单元测试，覆盖开放边、反面、倒置壳、重复面、共线退化、独立壳、仅顶点相接的壳、短边及舍入后退化。

### STL 导出与朝向

模型、导出文件及检查脚本均位于仓库的 `models` 目录。本文所有命令均先执行
`Set-Location C:\gitroot\minibox\models`，再运行；相对链接以本文所在目录为准。

仓库中的 `bottom.stl` 为底壳，底面位于 Z=0；`lid.stl` 为独立上盖，使用 `part="lid-print"` 的侧立落地朝向，**不是装配坐标**。两者均为毫米单位的二进制 STL，采用 `$fn=32`，不含模块预览实体。装配查看请使用 SCAD 的 `"assembly"` 模式。

**网站兼容版本：`bottom-y-up.stl`、`lid-y-up.stl`。** 根据“带两个 Type-C 孔的后壁显示在顶部，底面显示在后方，而左右方向正常”的描述，网站可能使用 Y 向上坐标。兼容版相对原 STL 绕 X 轴旋转 **−90°**，再平移至非负坐标；坐标变换为 X 保持、原 Z 变为新 Y、原 Y 反向变为新 Z。因此底面位于 **Y=0**，底壳后壁朝 −Z，左右不变。这是旋转，不是镜像，尺寸、孔位及实体体积不变。STL 本身不携带“哪个轴朝上”的元数据，网站是否适用仍需上传确认。

原版 `bottom.stl`、`lid.stl` 保持不变，继续供通常采用 Z 向上的切片软件使用；不要把 Y 向上兼容版直接当作已摆正的 Z 向上打印文件。上盖兼容版保留原来的侧立打印姿态，只转换坐标轴，并非装配朝向。回归检查验证兼容版的封闭连通性、体积、轴向尺寸，以及原底面和后壁分别转到 Y=0 和 Z=0。

重新导出时不必修改源文件的默认预览模式：

```powershell
& "C:\Program Files\OpenSCAD\openscad.com" --export-format binstl -D 'part="bottom"' -o .\bottom.stl .\minibox-enclosure.scad
& "C:\Program Files\OpenSCAD\openscad.com" --export-format binstl -D 'part="lid-print"' -o .\lid.stl .\minibox-enclosure.scad
& "C:\Program Files\OpenSCAD\openscad.com" --export-format binstl -D 'part="bottom-y-up"' -o .\bottom-y-up.stl .\minibox-enclosure.scad
& "C:\Program Files\OpenSCAD\openscad.com" --export-format binstl -D 'part="lid-y-up"' -o .\lid-y-up.stl .\minibox-enclosure.scad
```

### 独立 3MF 文件（原始装配坐标）

`bottom.3mf` 和 `lid.3mf` 使用原始 CAD 坐标：**X 左右、Y 前后、Z 向上，单位毫米**，分别由 `part="bottom"` 和 `part="lid"` 导出。没有 Y 向上转换，也没有侧立、自动落地或其他装配变换；每个文件只包含对应的一个实体，不含模块预览。

底壳范围为 X=0–120、Y=0–154、Z=0–124.1288 mm；盖板范围为 X=2.9–117.1、Y=6.5–147.5、Z=25–124.1288 mm。**`lid.3mf` 与侧立的 `lid.stl` 姿态不同**：3MF 保留盖板装配位置，因此最低点 Z=25 mm，不直接位于打印平台。打印前应在切片软件中选择所需朝向并落地；若要保留两个部件的装配关系，导入时不要自动居中或落地。

这些文件是几何模型，不包含打印机、材料、支撑或切片参数。旧模型曾在 OpenSCAD 2021.01 原生 3MF 导出时因近邻顶点舍入出现退化；目前已修复源几何，仍使用下面的命令先导出并严格验证临时二进制 STL，再完整保留坐标打包为标准 3MF，确保两个格式使用同一网格。回归检查确认毫米单位、单实体、无额外摆放变换、封闭连通网格，并逐个核对三角面顶点坐标及方向与原始装配坐标 STL 完全一致。临时文件自动清理，现有 STL 不会被覆盖。

```powershell
python .\tests\check_enclosure.py --openscad "C:\Program Files\OpenSCAD\openscad.com" --output . --3mf-only
```

### 尚需实物复测的参数

草图没有标注圆角半径，当前底部 R12、上缘 R6、转折 R10 是设计值，并非实测值。键盘和摇杆窗口尺寸、偏心位置及柱顶安装距离已补充；屏幕 PCB 加屏体共 5 mm（2+3 mm）及显示区左右边距已补充。显示区上下边距、屏幕后部接插件、摇杆总高、其他模块 PCB 厚度和摇杆安装孔左右边距仍待实测，不能据此认定已验证实物装配。

屏幕单独使用实测 PCB 厚 **2 mm**、屏体厚 **3 mm**；其他模块 PCB 仍暂用 1.6 mm。屏幕 PCB 正面到盖板内面为 4 mm，PCB 背面承托安装面到盖板内面为 **6 mm**，均沿盖板法线计量。屏幕后侧仍保守预留 4 mm 器件/接线检查包络，其范围距离 PCB 四边各缩进 8 mm；它是未实测的额外空间，不计入已确认的 PCB 加屏体 5 mm。增大 `screen_stack_above_pcb` 会把屏幕安装面向内移，并按需增加外壳深度，避免后部合盖柱挡住屏幕；极端修改仍应重新运行干涉检查。

摇杆总高仍暂设 30 mm，穿盖部分用以实际圆孔中心定位的 Ø29 圆柱包络表示，不再使用居中的 22 × 22 mm 方形包络。键盘与摇杆窗口外的周边器件没有实测高度，预览均暂按 PCB 上方 2.4 mm 的可用包络显示（5 mm 安装距离扣除暂定 PCB 厚 1.6 mm 和 1 mm 余量），不沿用旧版 7 mm 假设。包络表示可用空间，不代表已测量的器件外形。实际按键行程、摇杆全行程包络、显示区纵向偏心量及接插件位置需实测后调整。键盘总高 20.6 mm 按模块底部至最高点解释。

螺母采用胶水固定，不按热熔压入设计。Ø4.7 孔适配外径 4.5 mm、长度 5 mm 的圆柱螺母，并预留 0.2 mm 直径间隙；涂胶时避免堵塞螺纹和尾端让位孔。正式打印前建议先试打螺母孔，并检查 10 mm 螺丝的有效拧入长度。底壳底面落地打印，前排和中排合盖加强柱从底板连续生长；后排两个短固定座及屏幕耳的斜撑从侧壁逐层长出。斜向螺母孔顶部等局部仍需在切片软件检查并按需增加支撑，不能视为无支撑打印保证。上盖可用 `"lid-print"` 侧立打印，并按切片预览增加裙边和窗口处支撑。

### 模型回归检查

布尔避让检查分为屏幕与壳体、接口与盖板、底板布局、屏幕安装、装配与固定座、支撑与螺母孔六组，分别输出进度和失败组名；不再把所有探针放进一次大型运算后无进度等待。每组保留原检查内容，并分别验证 3 mm 和 12 mm 屏体参数。

`tests\check_enclosure.py` 按 `$fn=32` 实际导出底壳、上盖及侧立上盖，检查封闭连通网格、孔位、沉孔、2 mm 开孔外边距、圆角、0.5 mm 装配间隙、1.5 mm 宽且厚的承托圈及装配干涉。独立坐标检查屏幕高度、PCB 到喇叭孔边 **8 mm** 间距、左移 2.26 mm 的 **85.52 × 57.68 mm** R6 窗口及直边各 1 mm 余量、PCB 厚 2 mm、屏体厚 3 mm、安装耳承托面到盖板内面的 **6 mm 法向间距**，以及盖板两侧边条的跨转折连续性。底板模块之间空通道 10 mm，其他模块和独立固定结构使用 10 mm 扩展包络；侧壁和承托沿至少 1 mm，贴侧壁屏幕斜撑至少 2.5 mm，自身安装接触除外。前间距 10 mm、后壁间距 20–21 mm 不变；所有支撑检查 75° 及实体连接。检查默认实测 3 mm 屏体，并保留 12 mm 屏体的参数回归案例（不是实物厚度）；两者 PCB 厚均为 2 mm。忽略 0.02 mm 内的名义贴合面；这不代替实物装配或材料强度测试。

```powershell
python -m unittest discover -s .\tests -p test_mesh_checks.py
python .\tests\check_enclosure.py --openscad "C:\Program Files\OpenSCAD\openscad.com" --output "$env:TEMP\minibox-enclosure-check"
```

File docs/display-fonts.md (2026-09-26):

# 显示字体与刷新

## 原生像素字体

屏幕始终按 **480 × 320** 原生分辨率输出。原来的低清晰度来自 3×5 字形放大，
不是屏幕分辨率不足；现使用 **24 px、16 级灰度抗锯齿** 字体，逐像素合成到
RGB565 画面，不再放大低分辨率点阵。

字体由开源 Noto Sans CJK SC Regular 2.004 转换，命名为 Minibox Sans 24，
包含 **21,524 个字形**，覆盖英文及源字体支持的基本汉字区 U+4E00–U+9FFF、
常用标点等。它不是完整 Unicode 字库，不含所有罕见扩展区汉字或 emoji。
来源、版权、OFL 许可及生成方式见
[`font_data/README.md`](../esp32_idf_s3n16r8/font_data/README.md)。

测试画面包含：

- 标题：`Minibox 屏幕测试 480x320`。
- 中文方向、计数、引脚标签及中英文 K 状态。
- 底部：`中文 ABC 123 - 摇杆测试`。

## 文件系统分区

| 分区 | 起始地址 | 大小 | 用途 |
|---|---|---|---|
| factory | 0x10000 | 2 MiB | 测试固件 |
| fonts | 0x210000 | 10 MiB | SPIFFS 字体文件系统 |

字体二进制约 6.1 MiB。剩余 Flash 暂不分配，不启用 OTA。
启动时分块顺序读取字库到 PSRAM，块间让出 CPU；渲染时不再访问文件系统。
字库约 6.1 MiB，加上两份画布约 0.6 MiB，适配本板的 8 MiB PSRAM。
这样避免 SPIFFS 大文件随机寻址造成长时间阻塞和看门狗报警。
字体文件缺失、损坏或字符不受支持时明确报告错误，不静默退回粗糙字体。

标准命令不变：

```powershell
Set-Location .\esp32_idf_s3n16r8
idf.py build
idf.py -p COM8 flash
```

ESP-IDF 自动生成并烧录 `fonts.bin`，**首次安装或分区/字库变化时不要只烧录应用**，
否则新分区或字体可能缺失。挂载失败不会自动格式化字体分区。
字库已正确烧录且未变化、只修改 C 代码时，可用 `idf.py -p COM8 app-flash`
更新应用，避免重复写入大字库。
已提交转换后的字体，因此普通构建无需下载字体或安装 Pillow/fontTools。
首次字体烧录比只有应用程序时更久。

## 闪烁排查

运行时以 16×16 像素块检测变化，仅合并相邻变化块并提交小矩形。
数字变化不再重写整条 480 像素扫描行，相同帧不发送。
X/Y 仅显示 -1.00～1.00 的两位小数，不显示抖动的原始 ADC 计数。
中心从零启动时小于 0.05 不进入显示；偏移回到 0.02 以内才显示 0.00，
形成迟滞，避免中心死区边缘来回跳动。相对上次显示值不超过 0.01 的变化
也保持原值；光标使用相同稳定值。
数字更新不超过 4 Hz；光标/按键显示最高约 10 Hz，输入采样仍为 100 Hz。
当稳定后的 X/Y、显示数字、方向和 K 状态/计数均未变化时，直接跳过整个绘制及
SPI 传输；X/Y 不变但按下 K 时仍显示按键变化。外部错误提示仍可更新。
串口的 `LCD_TX` 是启动以来已完成的画面 DMA 传输次数；保持摇杆和按键不动时
该数应保持不变，可直接确认停止刷新。
背光 GPIO9 保持恒定电平，没有 PWM 或周期性开关。

如需严格排除刷新因素，在 `idf.py menuconfig` → `Minibox hardware test`
启用 `Diagnostic: freeze display after first joystick frame` 后重新烧录。
显示第一帧测试画面后停止后续正常 SPI 写屏，摇杆仍采样并输出串口日志；
串口出现 `STATIC DISPLAY` 可确认进入诊断模式。输入故障仍允许显示错误信息。
默认关闭该选项，以保留实时摇杆测试。

如果正常采样的静态诊断画面仍整屏忽明忽暗，应用层持续刷新就不是原因，
应继续检查背光、电源、接线和面板初始化参数。未做静态对照前，
不能仅凭现象认定供电或刷新是哪一项原因。
LED 若是裸背光供电端，不能由 GPIO 直接带负载，必须遵守模块电气规格。

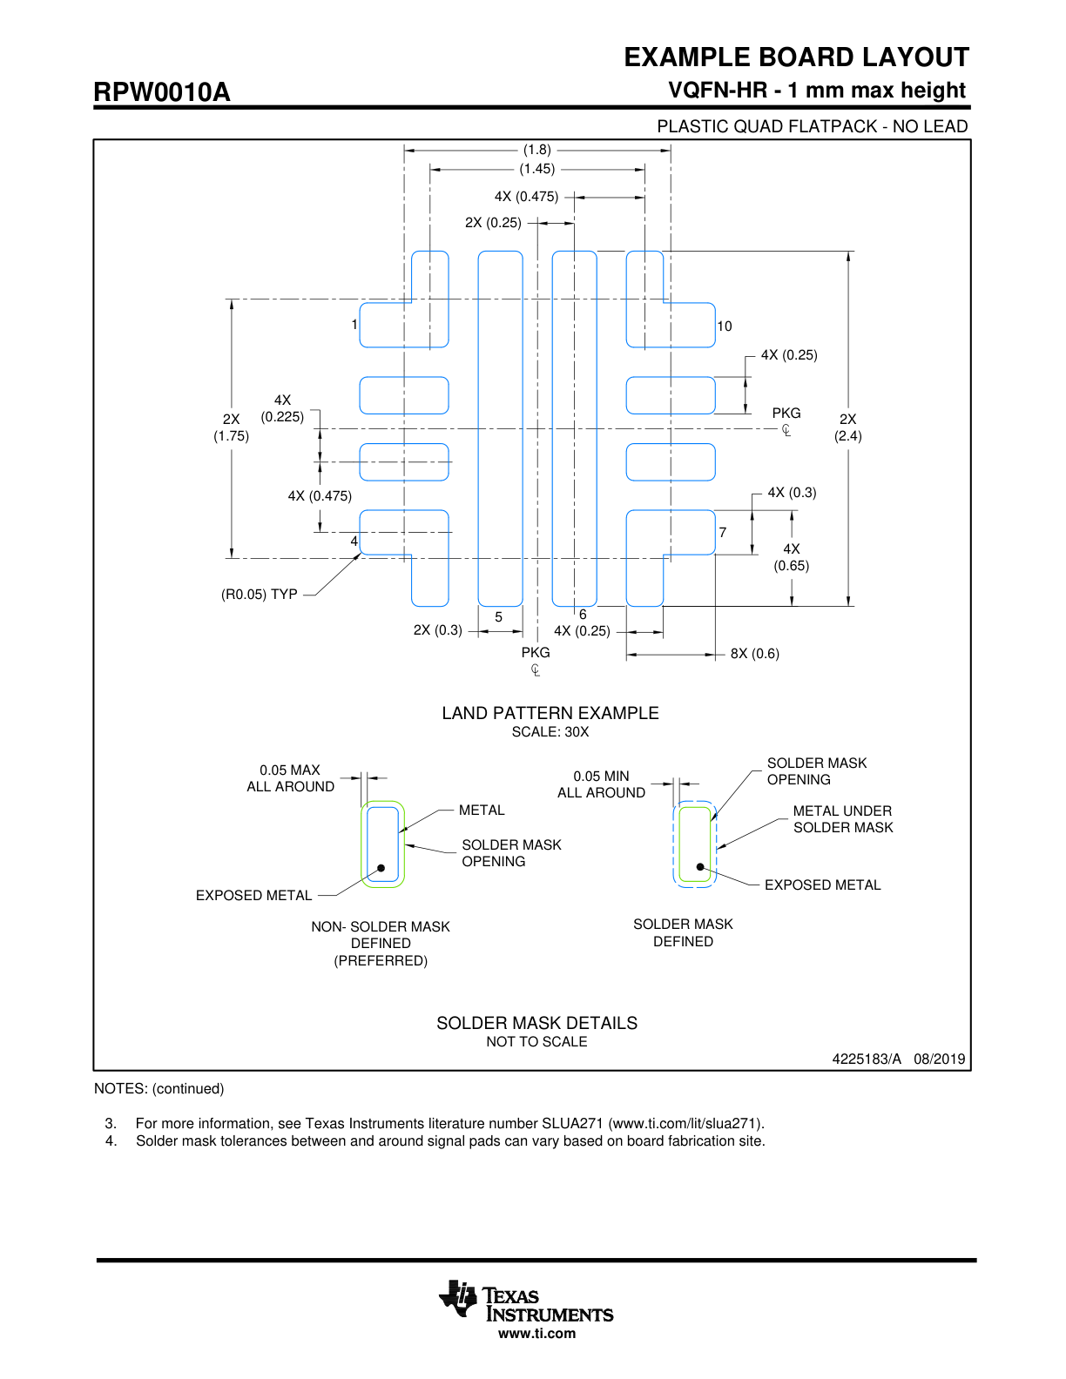
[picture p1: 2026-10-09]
hardware_references/drawings/tps25947-package-73.png

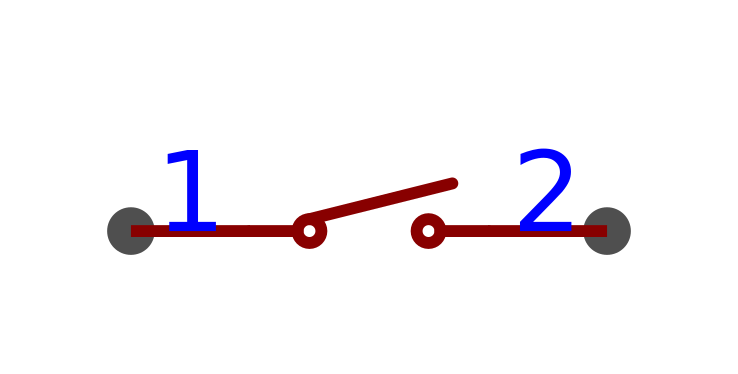
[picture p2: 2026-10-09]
hardware_references/drawings/cpg151101d13-lcsc-sch.png

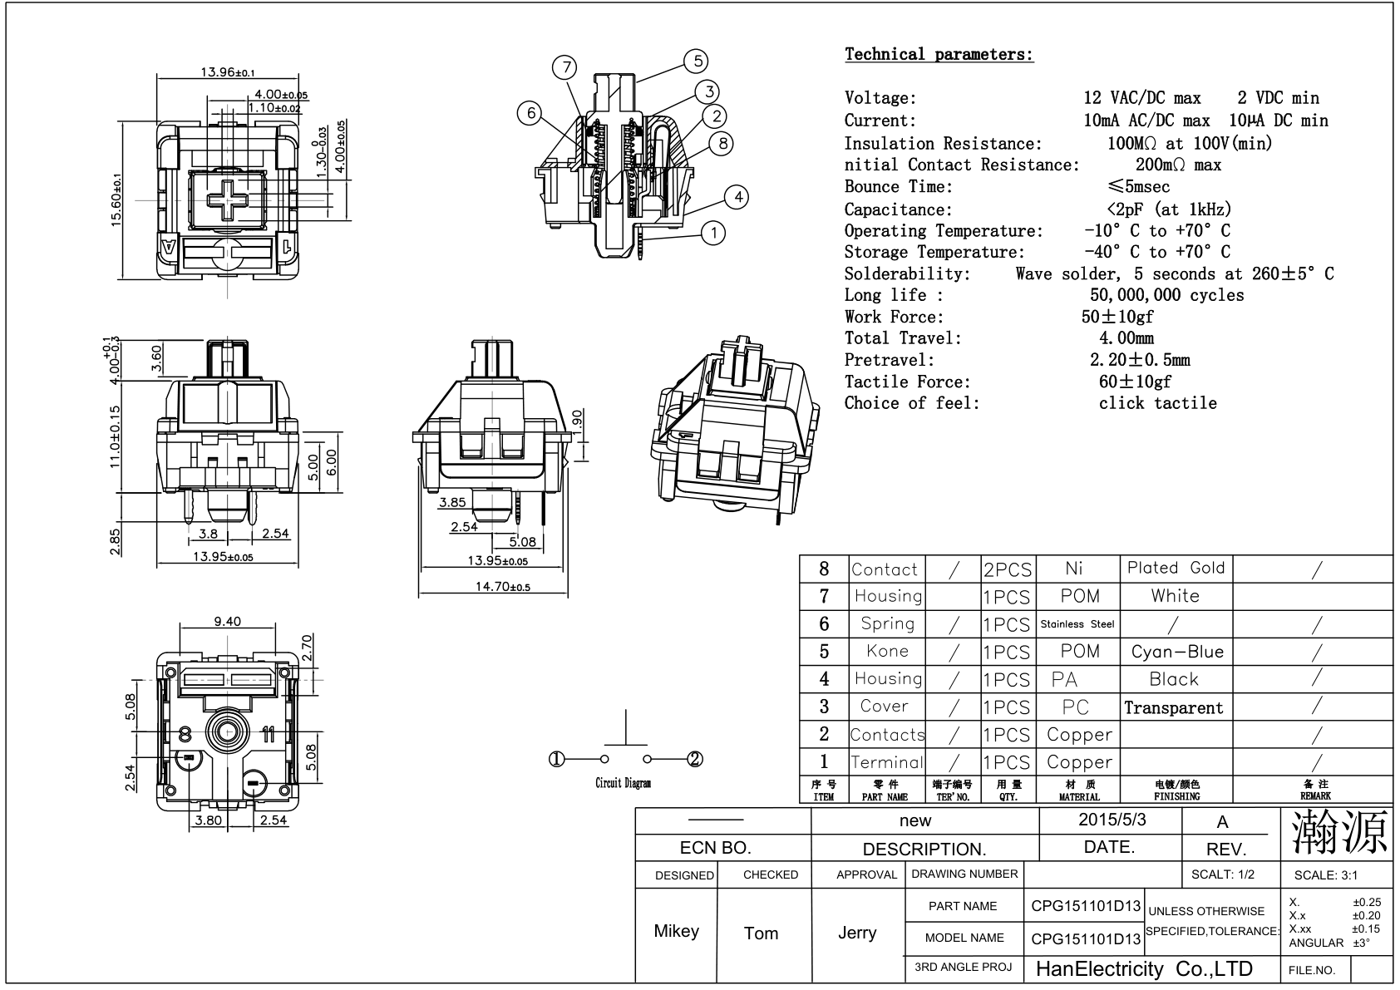
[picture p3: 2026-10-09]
hardware_references/drawings/cpg151101d13-page-8.png

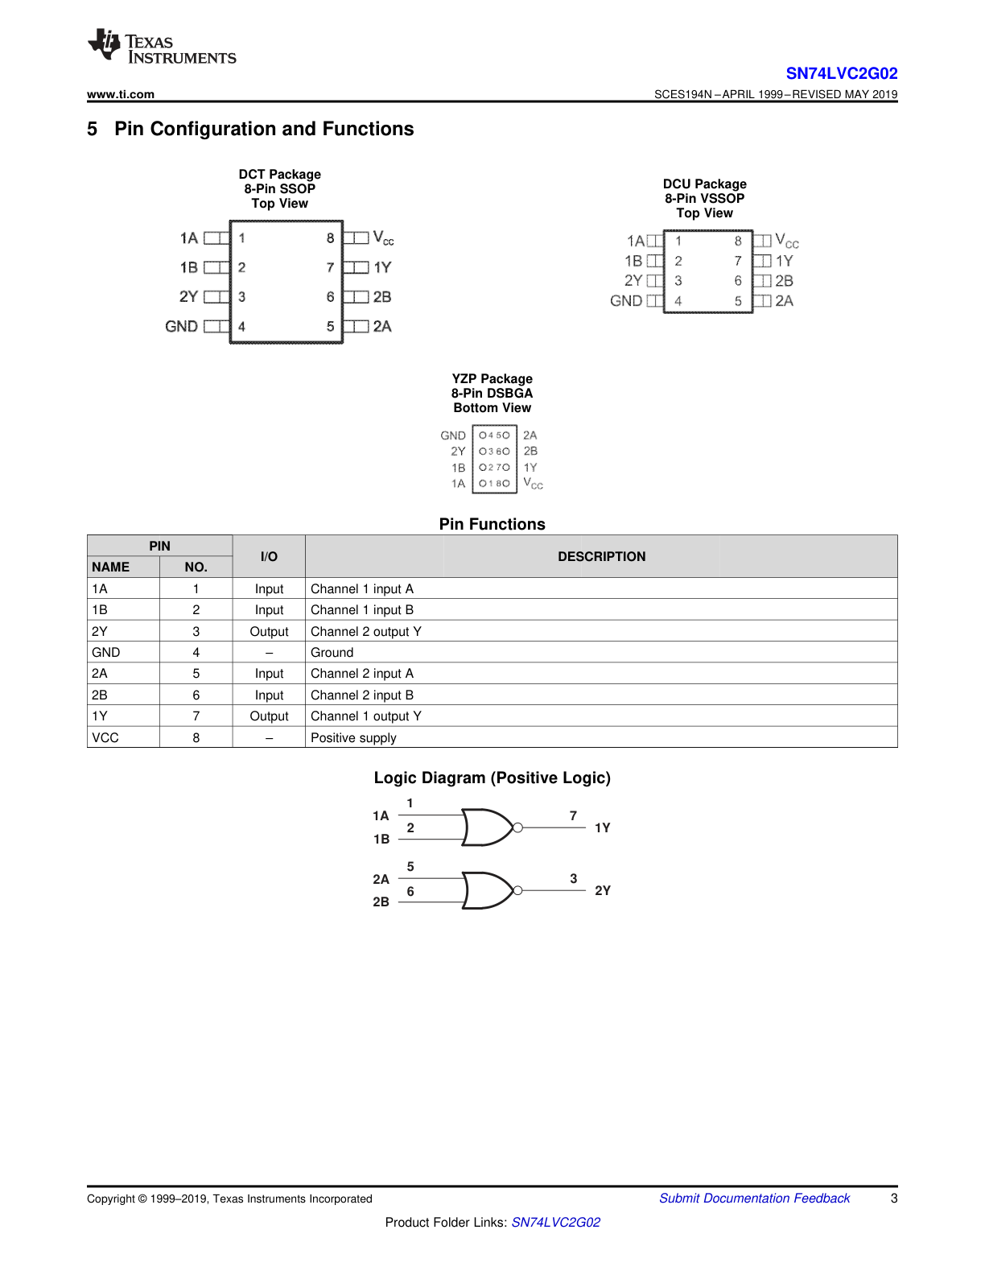
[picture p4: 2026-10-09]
hardware_references/drawings/sn74lvc2g02-pins-3.png

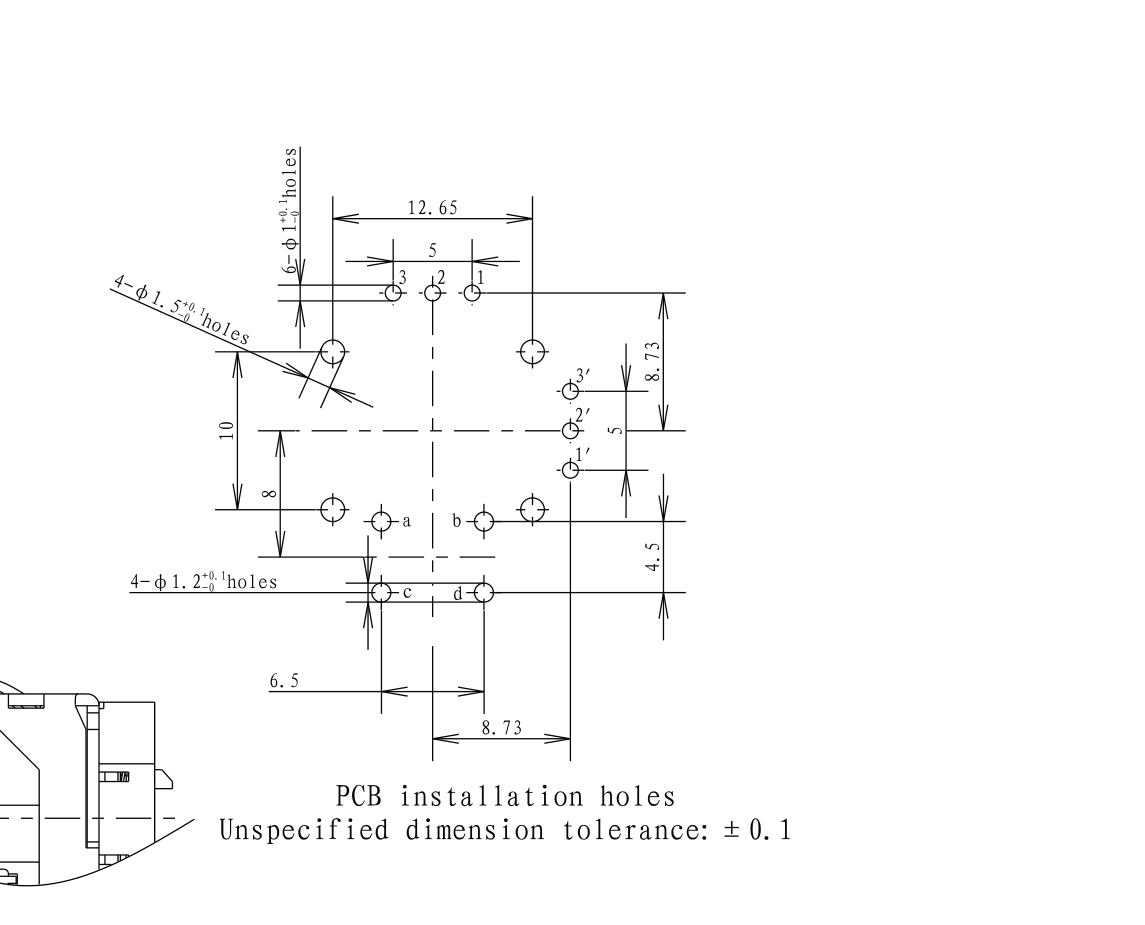
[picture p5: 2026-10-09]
hardware_references/drawings/thb001p-drill-detail.png

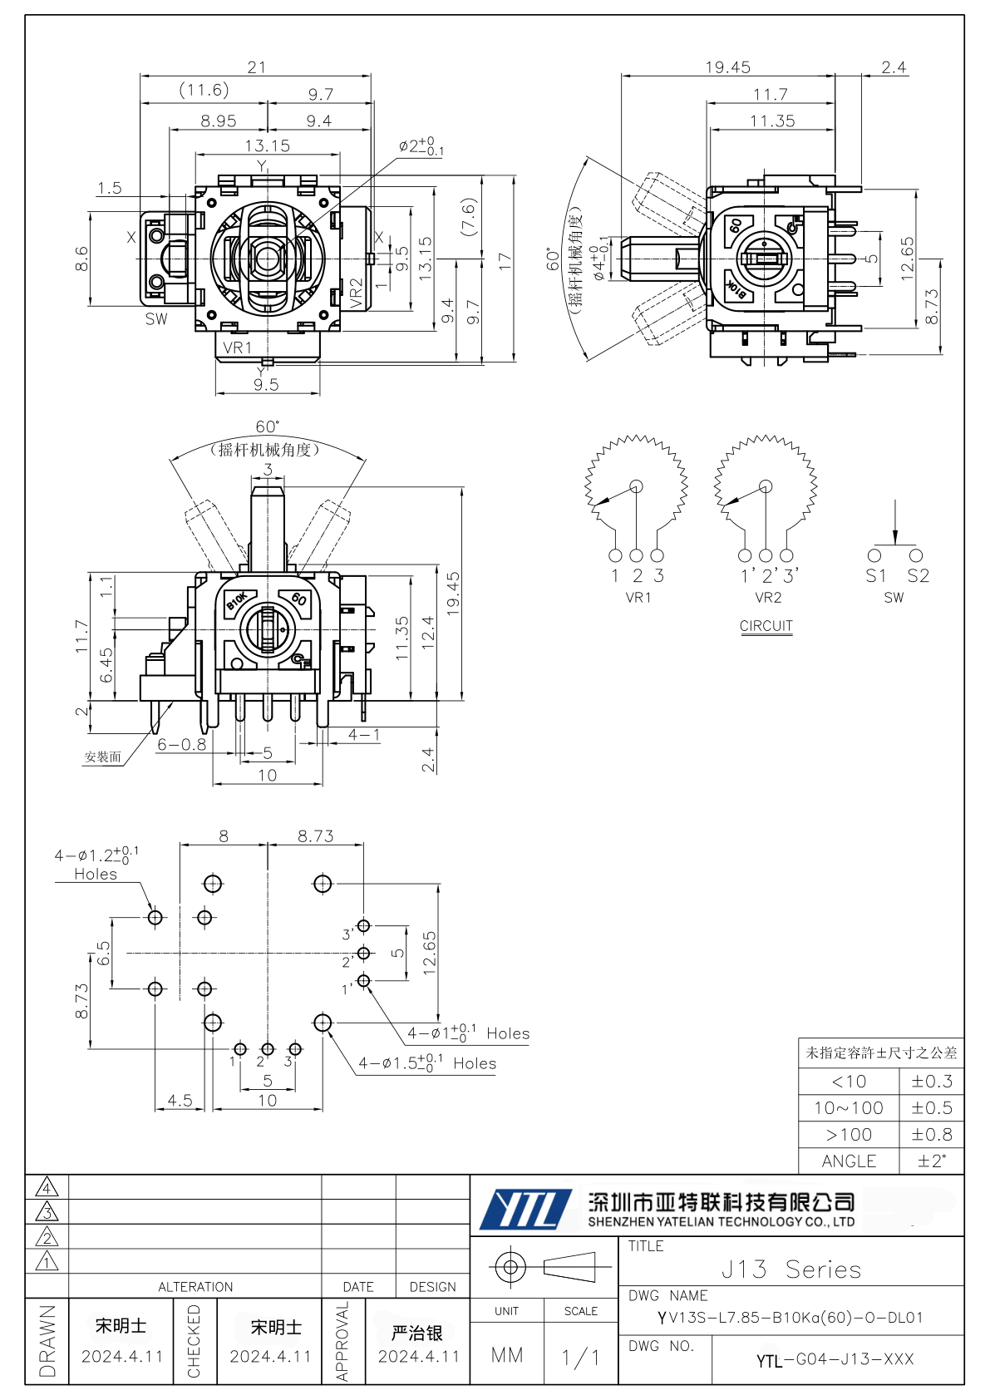
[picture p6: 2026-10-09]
hardware_references/drawings/yv13s-l7.85-b10ka-60-0-dl01-page-1.png

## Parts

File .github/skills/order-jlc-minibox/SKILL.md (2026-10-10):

---
name: order-jlc-minibox
description: 'Prepare and review domestic JLC PCB and full-assembly orders for Minibox, including KiCad Gerbers, BOM/CPL matching, through-hole parts, sourcing, quotations, and user-approved submission.'
argument-hint: 'Specify the KiCad project, board and assembly quantities, assembly scope, and whether to prepare a quote or submit an approved order.'
user-invocable: true
disable-model-invocation: false
---

# Minibox 嘉立创 PCB 与全元件装配下单

适用于嘉立创**国内站**的 PCB 制造、SMT、插件焊接及装配询价。
用户说“全部焊好”时，不得只提交贴片件清单，也不得擅自购买未确认的替代件。
本技能负责下单资料与流程；设计整改另用 `design-route-minibox-pcb`。

## 先读取并明确范围

- [仓库说明](../../instructions.md)。
- [PCB 设计与布线技能](../design-route-minibox-pcb/SKILL.md)。
- [接线和实际模块](../../../docs/hardware-connections.md)。
- [国内嘉立创工艺规范](../../../docs/jlc-pcb-design-spec.md)。
- 目标工程 README、当前 manifest、BOM、坐标、装配图和待工厂确认项。

`kicad` 是模块载板，`kicad_ex` 是独立集成工程，禁止混用资料。
确认数量、装配数量、交期、预算、板厚/铜厚/颜色/表面处理及收货信息。
“载板全焊好”与“模块也采购并组装，交付整机”不同：
载板排母焊好不等于 ESP32、屏幕、RTC、功放、麦克风模块已供货。
当前这些模块插在排母上，不应为下单方便改成直接焊接。

用户不在线时可检查、整理和准备询价；不得猜测购买数量、预算或收货地址。
报价草案可明确列出假设，不能把假设当成购买授权。
只要一块测试板时，先核对 PCB 最小制作数量和装配最小数量，两者可能不同。
不得把系统默认 5 块或最低装配 2 块当成用户授权；记录多做但不装配的板、
最低订单量与费用差异，请用户批准超过所需数量的采购。

## 官方入口与实际页面

- PCB：<https://www.jlc.com/>。
- SMT：<https://www.jlc-smt.com/order>。
- [PCB 与 SMT 下单教程](https://www.jlc.com/portal/server_guide_19.html)。
- [BOM 格式说明](https://www.jlc.com/portal/server_guide_19337.html)。
- [工艺能力](https://www.jlc.com/portal/vtechnology.html)。
- [国内 SMT 工艺能力表](https://www.jlc-smt.com/vtechnology)。
- [国内装配元器件目录](https://www.jlc-smt.com/lcsc/index)。

优先使用可用的浏览器自动化工具，先检索其工具定义，再导航、读页面。
工具不可用时再发现适合的连接器；不要用 shell 请求模拟登录或绕过网页流程。
每次操作以最新页面状态为准，不能保存并复用旧元素编号。
官方网页可能依赖 JavaScript；静态抓取只有页脚时，改读浏览器页面，
不要把抓取不到内容解释为官方没有相关服务。
先检查是否已登录，避免重复登录；不从磁盘挖掘商城密码、验证码或 Cookie。
用户自行处理需要其完成的认证，不在技能、日志或截图中保存凭据和个人信息。

## 制造与全装配门槛

1. 确认文件对应最新保存的 PCB；DRC/未连接、数字 CAM/钻孔对位、
   机械包络及待确认条件分别核对。无原理图不能声称 ERC/原理图一致性通过。
   零 DRC 不等于可生产，不把 `ENGINEERING_REVIEW_NOT_PRODUCTION_APPROVED`
   自动改成生产批准。
2. 明确全部物理安装件、精确 MPN、C 编号、数量和供料方式。
   商品商城在售不等于嘉立创装配库有货或能加工。
   核对插件针脚、孔径、排母高度、端子进线方向、极性及装配干涉。
   通用封装名称或“兼容某品牌”不能代替已确认采购型号。
3. 区分 SMT、插件/异形件和模块组装。元件从正面插装、背面焊接
   不等于“底面 SMT”；所有贴片在正面也不等于只需要贴片工序。
   摇杆、机械轴、排母和端子逐项确认手焊、选择焊或其他工艺与费用。
   用户指定全部商城供料、不邮寄时，严格排除客供路线；优先查国内
   SMT 元器件目录和备料方式，而非只查普通商城是否有同名商品。
   官方存在邮寄服务也不代表可忽略用户的“不邮寄”限制。
4. 机械轴/摇杆手册的焊锡耐热性测试不能证明整件可过回流炉；
   不能为了自动贴片把插件改报成 SMT。
   缺货需确认可用的代采/客供/备料方式及交期，不能静默省略。
5. 经济型与标准型按实际工艺、数量和报价选择，不盲目选最贵或最便宜。
   标准型的工艺边/Mark 按工厂要求处理；不强加到经济型，也不擅自扩大成品板。
   客供件、特殊插件或组装服务未经工程确认时，停在询价阶段。

## 文件与 BOM/CPL 核对

使用**纯 CAM ZIP**上传 PCB，不上传包含文档、效果图和多个历史版本的审核大包。
CAM 包应含目标板的四层铜、阻焊、丝印、外形和独立 PTH/NPTH 钻孔。
层数、板框尺寸及预览一致；多个外形、镜像或钻孔错位必须先解决。

2026-10-09 观察到 SMT 页面“PCB 源文件提取 BOM/坐标”仅列出
AD、99SE、PADS 格式；官方教程同样说明该限制。
**KiCad 使用 Gerber ZIP + 显式 BOM + 坐标上传**，不要改扩展名伪装成 AD，
也不要假定 `.kicad_pcb` 能自动提取。以后以当时页面支持为准。

BOM 的 `Comment` 填完整型号及后缀，电阻等带数值和单位；
`Designator` 与坐标文件一致且不重复，`Footprint` 不为空、不要夹备注。
位号以逗号/空格分隔，C 编号逐项核对，不能仅凭自动匹配“成功”放行。
官方说明 BOM 支持 XLS/XLSX/CSV；坐标格式依页面模板与列映射核对。

全装配必须检查**全部物理件位号集合**，不是只核对 SMT 部分：
`bom-smt-review.csv` 和 `cpl-smt.csv` 只覆盖两个电阻时不能用于全焊报价。
`bom-all-review.csv` 与 `positions-all-review.csv` 是审核输入，
缺 MPN、方向未批准时不能改名伪装成生产资料。

尤其注意复合封装：一个 PCB footprint 可能实装多个独立物理件。
完整 BOM/坐标应拆分物理位号，分别给安装坐标；
不能让系统自动匹配成不同结构的多排连接器。逐一核对条形排母原点、
旋转零角、Pin 1、端子开口及摇杆方向，不能以 CAD 数字角度代替工厂贴装预览。
坐标统一单位、原点、轴向、视角和面别，底面不要重复镜像。

## 下单顺序与确认点

1. 检查 PCB 在线预览与报价参数，准备 PCB 订单；通常再选择对应 PCB
   订单进入 SMT。没有新板订单时，不能随便选账户里的旧订单代替。
2. 上传当前 BOM/坐标并逐件匹配；未匹配、缺货、停产、替代件、插件和
   客供件全部列出处理结果。全装配范围包含的件不能设成“不贴”后声称完成。
3. 检查贴装/插装预览、工艺、数量和 DFM。
   页面有“器件组装”“贴插焊点”等选项不等于摇杆等特殊件已获承接批准。
   需要业务/工程审核时准备清单和问题，不编造客服答复。
4. 汇总 PCB、元件、贴片/插件工程、焊点、上料、治具、包装、税运及交期。
   官网旧价格示例不能当成本订单报价。报价包含的服务必须与“全焊好”一致。
5. 在提交订单、支付、采购备料或发送客服消息前，依工具的确认规则取得
   用户对具体动作的批准；至少展示最终数量、范围、总价和待确认风险。
   Autopilot 和“帮我下单”不能代替这些工具要求的具体确认。
   文件上传限于用户指定数据与嘉立创目的地，不上传凭据或无关私有文件。
6. 批准后仅执行该动作一次；超时或状态不明先查订单列表与付款状态，
   不重复提交。订单号、待审核/待付款/已付款/生产中分别报告。
   “上传完成”“报价完成”不是“下单完成”，SMT 订单也不是全部模块已组装。

## 已走通的页面与按钮路径

以下是实际使用过的国内站入口与可见标签，不是固定屏幕坐标。
直接走这些入口，不从首页重复探索；页面改版时只核对变化部分。
元素以最新快照中的角色、标签及位号行定位，不能复用旧element_index。

| 阶段 | 页面或入口 | 已知操作与检查 |
|---|---|---|
| PCB参数 | `https://www.jlc.com/newOrder/#/pcb/pcbPlaceOrder` | 按当前板填写参数及制作量；检查报价、附加服务和数量提示 |
| PCB提交检查 | 参数页的订单检查 | 补齐必填项；选择“手动确认订单”，保留人工生产稿确认 |
| PCB接入SMT | “确认并提交”／“提交PCB订单，去下SMT” | 这是提交边界，不是单纯翻页；需用户下单授权 |
| PCB状态 | `https://www.jlc.com/newOrder/#/pcb/pcbOrderList` | 用当前文件名、数量和版本找到对应记录，进入详情核实订单号、审核和支付状态 |
| SMT入口 | `https://www.jlc-smt.com/order` | 选择本工程对应PCB订单，不能用账户中其他板代替 |
| 手动资料上传 | `https://www.jlc-smt.com/order?type=smtUploadBomFile&reserveBeforeAuditOrderFlag=true` | KiCad使用显式BOM/CPL；关联订单由网站传入，不硬编码旧订单ID |
| 匹配/编辑 | `https://www.jlc-smt.com/order/smt-order-lceda` | 网站生成关联参数；勾选物料行原生checkbox，检查“核对进度” |
| BOM匹配 | SMT物料匹配页 | 上传显式BOM及坐标；核对“C编号匹配”、位号、数量及“插装”，不选择整盘采购或客供邮寄 |
| 装配编辑 | 贴装预览中的“2D”／“3D”、单位“mm” | 选中具体位号后检查中心和旋转；缺失模型时用编号焊盘，不凭矩形占位判断有无器件 |
| 已知旋转控件 | 点击位号/位号组文本 | “独立逆时针旋转”／“独立顺时针旋转”及“旋转角度”；不要用会移动组内中心的“整体逆时针旋转” |
| 批量精确坐标修正 | 悬停“更多操作” | “局部修改BOM和坐标”→“仅修改坐标”→`input[type=file]`上传工厂CPL→“确认变更”，随后重新核对材料 |
| 持久化 | “存档当前操作” | 等待“保存成功！”，刷新后逐件读回；只改画布不等于已存档 |
| SMT提交 | 最终确认页 | 本次仅到达预览，未实际提交SMT；提交后的按钮/审核路由不宣称已验证 |
| 人工工程咨询 | `https://www.jlc-smt.com/vcontact` | 官方人工业务入口；下单页“AI客服”不是人工工程承接批准 |

KiCad不走AD/99SE/PADS源文件自动提取入口。使用纯Gerber、完整BOM和
工厂专用CPL；上传控件和列映射标签随版本核对一次并记录变化，不猜文件格式。
网页最终可见报价优先于旧截图或不同用途的内部估算字段。
带C编号仍要完成物料匹配核对，不能承诺网站免去该步骤。
工厂专用CPL上传后角度直接保留，坐标按网站精度舍入；不在网页再额外
加一次库零角偏移。需要截图时可定位`#smt-engine-canvas`，但截图不能代替
逐件数值读回和实际Gerber叠加。列映射及PCB行入口的精确标签未记录，
下次只读取这些局部控件，不猜标签、不重新探索整条路径。

## 可复用的物料和封装经验

- 搜索摘要、分类名和封装名称都不是精确采购证据。打开官方商品页，
  对照完整型号、C编号、属性、库存和厂家图纸；排除邮寄专用与无货条目。
- 同系列不同针数分别核对图纸。相同节距不意味着孔径、本体、凸耳、
  高度、Pin 1或进线方向一致；推荐PCB孔径不能误当作引脚截面尺寸。
- 普通商城MOQ、PCB制作量、PCBA装配量和用料损耗分别判断。
  BOM保留单板用量，让装配数量扩展；不能重复乘数量。
- 区分实际安装数量与损耗备料；正常损耗不等于多做成品，
  更不等于整盘采购。保留页面的损耗明细和具体范围。
- 候选件不自动变成批准替代。选型后同步本地封装、PCB、BOM、CPL和CAM；
  修改局部连接时保留无关布线，不整体挪动电源干线。
- 嘉立创添加工艺边或定位孔必须核实位置。仅废边上的加工孔与成品板改孔
  不同，不能为通过订单默认接受改动成品。

## 工厂坐标映射：先在文件解决，不在网页逐件重调

下次上传前读取工程README与当前manifest，从实际保存PCB重新导出。
当前资料固定在`kicad\assembly`与`kicad\fabrication`，历史使用Git提交；
不查找日期revision目录，不使用旧quote文件。完整BOM为
`kicad\assembly\bom-all-review.csv`，上传坐标为
`kicad\assembly\positions-jlc-review.csv`，纯CAM为
`kicad\fabrication\minibox-gerber-review.zip`。
沿用已核验的采购ID、库编号焊盘和库原点定义；仅布局变化时重算绝对坐标，
不要重新找同一元件或复制上一版网页中心。

Gerber只保存实际铜、丝印、外形和钻孔，没有装配模型的旋转映射。
KiCad footprint角度不等于工厂库零角；pad平均中心也不一定是库head原点。
用编号焊盘及厂家方向，求库到实际板的旋转和原点平移：
先验证轴向、单位和正角约定，再逐孔核对，不对所有器件统一加一个角度。
不能为了修网页预览旋转正确的PCB封装或改变Gerber孔位。

需要保存并区分以下文件：

| 资料 | 正确内容与用途 |
|---|---|
| 完整BOM | 精确型号、C编号、单板物理位号及数量 |
| KiCad审核坐标 | CAD自身中心、角度及物理件拆分，作为原始依据 |
| 工厂专用CPL | 已适配指定工厂库的中心、旋转、单位和面别，用于上传 |
| 映射导出源码 | 库编号pad和datum定义，从新版PCB重新计算，不硬编码旧绝对位置 |
| 修正报告 | 原CAD值、工厂值、中心/角度差、逐孔残差、文件/PCB哈希及待确认项 |
| 工厂保存读回 | 实际存档并刷新后的值；按PCB哈希绑定，不冒充新版布局验证 |
| 纯CAM包 | 只用于PCB上传；不混入操作经验和网页取证 |
| 综合审核包 | 同版本CAM、BOM、CPL、源码及报告，逐项核对哈希 |

本工程入口为 `kicad\export_jlc_positions.py`；完整导出流程也调用它。
项目采购ID及具体坐标/角度在工程BOM、CPL和映射报告中，不放在skill里。
每次工厂网页修正都回写导出规则和文件，再比较网页保存读回；
不得让网页成为唯一保存正确参数的位置。

若上传预览异常，先查位号映射、单位、列映射、原点和旋转定义。
看似超长的连接器可能是多个模型重叠，纯色矩形可能只是模型缺失；
两者均不能代替真实板框/编号焊盘叠加。确认Gerber已加载，不把空画布、
无DFM结果或缺少模型当成方向检查通过。
验证文件一致后，网页仅做短核对、存档和刷新，不再逐件重新探索调整。

## 状态、授权和并行经验

制作数量与装配数量分别确认；系统默认或MOQ不是授权。
用户后续明确修改范围或批准提交时及时更新状态，不继续重复已解除的限制。
询价、待审核记录、正式提交、付款、备料、DFM确认、生产批准是不同阶段；
核实按钮真实后果，既不把每次翻页当成购买，也不把未付款当成无后果。
用户准备改布局时暂停生产推进，保留旧记录，不擅自取消或支付。

并行时一个agent独占浏览器，另一个维护本地文件。交接必须说明文件版本、
授权、当前页面及下一动作；收到错误截图优先修已证实问题并保存读回，
不要为了报价调查拖延明确的局部修正。用户询问状态时立即回报具体进度
和控件阻塞，不只反复说“待确认”，不编完成时间。
订单失败/超时先查现有记录，避免重复提交。账号、地址、会话ID和认证信息
不进入Git；操作日志留会话artifacts，交付文件只保留必要的脱敏工艺数据。

每次下单结束或交接时，把sub-agent实际验证的页面入口、可见按钮、
旋转/组操作区别、上传列映射、保存/刷新步骤与失败解决方式合入本skill。
没有实际走通的步骤明确标为未验证，不把建议写成经验。
下次先读这些路径，页面没变就直接复用，只探索缺失或已变化的局部。
具体元件ID、中心及角度修正仍放工程BOM/CPL/报告，不混进通用流程。

2026-10-10补充验证：PCB参数页的“检查订单”是只读参数检查，
检查抽屉列出缺项，“确认并提交”才是提交边界。当前页在该边界之前
未提供Gerber上传控件；不能因此先提交而省略必要批准，也不能拿旧PCB
订单预览冒充新版CAM验证。无批准时保存本地配套资料，明确网站新版
贴装/3D、存档读回尚未完成，旧订单不动。
“确认生产稿说明”需同时选择“需要确认生产稿”“手动确认”和
“确认2次/确认多次”，再点“确定”；仅选前两项弹窗不会关闭。
页面存在同名重复DOM id（例如层压顺序），按按钮角色或`button#...`
定位，不用不加类型的id选择器。KiCad四层Gerber含明确定义的层名时
可选“我的文件中已有层压顺序”；I2S载板无USB数据线时不冒称有阻抗要求。
选择SMT时的说明包含自动修改工艺边/Mark及圆角范围：必须在备注要求
保留成品板框/安装孔，并待工程确认，不能默许把本工程R5缩成别的半径。
报价显示的快递费为“支付时为准”，不把预估运费当成锁定总价。

## 交付说明

明确报告已完成的资料/报价/订单阶段、订单号（如有）、数量、装配范围、
付款状态和具体阻塞项。资料修改后同步对应审核包与哈希，避免旧包配新 BOM。
仅写本技能不重新导出 PCB。未经新授权不修改设计、不 commit、不 push。

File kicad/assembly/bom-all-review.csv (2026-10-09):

Comment | Designator | Footprint | Quantity | LCSC Part # | Manufacturer Part | Notes
LAIL-PM2.54-22P-L | J1,J2 | PinSocket_1x22_P2.54mm_Vertical | 2 | C54973843 | LAILAN LAIL-PM2.54-22P-L | THT; 8.5mm plastic height; assembly fit review
LAIL-PM2.54-3P-L | J3A,J3B | PinSocket_1x03_P2.54mm_Vertical | 2 | C54973828 | LAILAN LAIL-PM2.54-3P-L | THT; two 8.5mm-high strips; NOT a standard 2x3 header
LAIL-PM2.54-7P-L | J4 | PinSocket_1x07_P2.54mm_Vertical | 1 | C54973832 | LAILAN LAIL-PM2.54-7P-L | THT; 8.5mm plastic height
LAIL-PM2.54-6P-L | J5 | PinSocket_1x06_P2.54mm_Vertical | 1 | C54973826 | LAILAN LAIL-PM2.54-6P-L | THT; 8.5mm plastic height
LAIL-PM2.54-14P-L | J6 | PinSocket_1x14_P2.54mm_Vertical | 1 | C54973850 | LAILAN LAIL-PM2.54-14P-L | THT; 8.5mm plastic height
WJ500V-5.08-03P-14-00A | J7 | Minibox:WJ500V_5.08_3P | 1 | C72334 | KANGNEX WJ500V-5.08-03P-14-00A | THT; wire entry RIGHT; 1.50mm PTH
WJ500V-5.08-2P | J8,J9 | Minibox:WJ500V_5.08_2P | 2 | C8465 | KANGNEX WJ500V-5.08-2P | THT; wire entry LEFT; 1.50mm PTH
CPG151101D13 | SW1,SW2,SW3,SW4 | Minibox:CPG151101D13 | 4 | C49234235 | HanElectricity CPG151101D13 | THT; exact user-selected part; no hot-swap socket
YV13S-L7.85-B10Ka(60)-0-DL01 | JS1 | Minibox:YV13S_L7.85_B10Ka_60_0_DL01 | 1 | C37323747 | YTL YV13S-L7.85-B10Ka(60)-0-DL01 | THT; press unused; mounting leads NC
5.1k 1% 0402 | R1,R2 | R_0402_1005Metric | 2 | C25905 | UNI-ROYAL 0402WGF5101TCE | SMT TOP; actual domestic factory stock must be checked

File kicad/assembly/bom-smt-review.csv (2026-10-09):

Comment | Designator | Footprint | LCSC Part #
5.1k 1% | R1,R2 | 0402 (1005 metric) | C25905

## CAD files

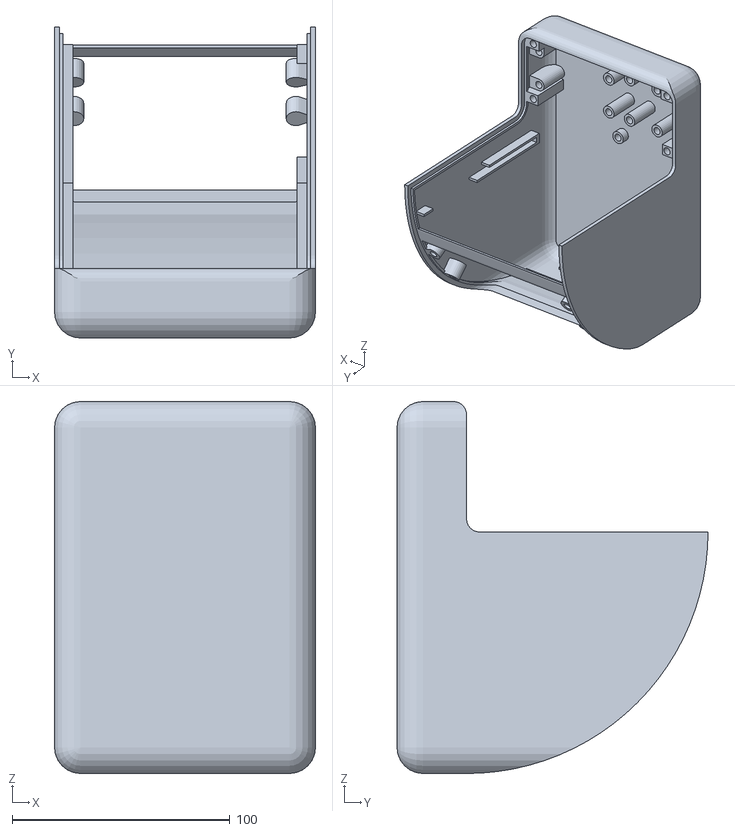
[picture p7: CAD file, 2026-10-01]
models/bottom-y-up.stl
120.0 x 143.0 x 171.0

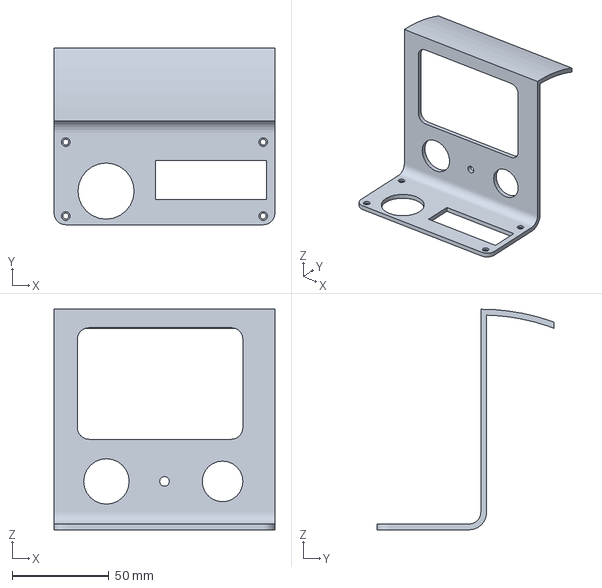
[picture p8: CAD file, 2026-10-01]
models/lid.3mf
114.2 x 91.2 x 114.0 mm

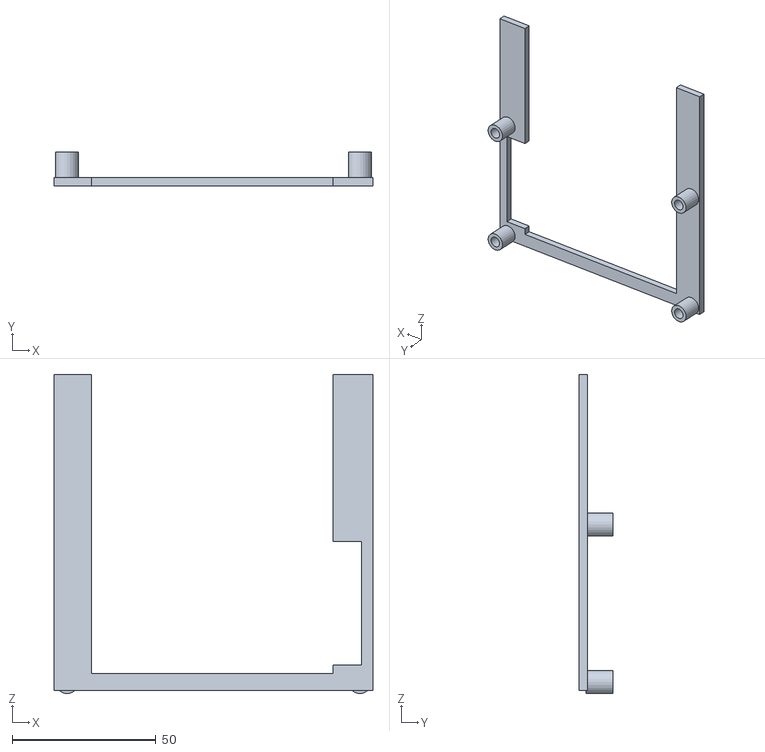
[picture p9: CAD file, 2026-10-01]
models/screen-bracket-y-up.stl
111.0 x 12.0 x 111.1

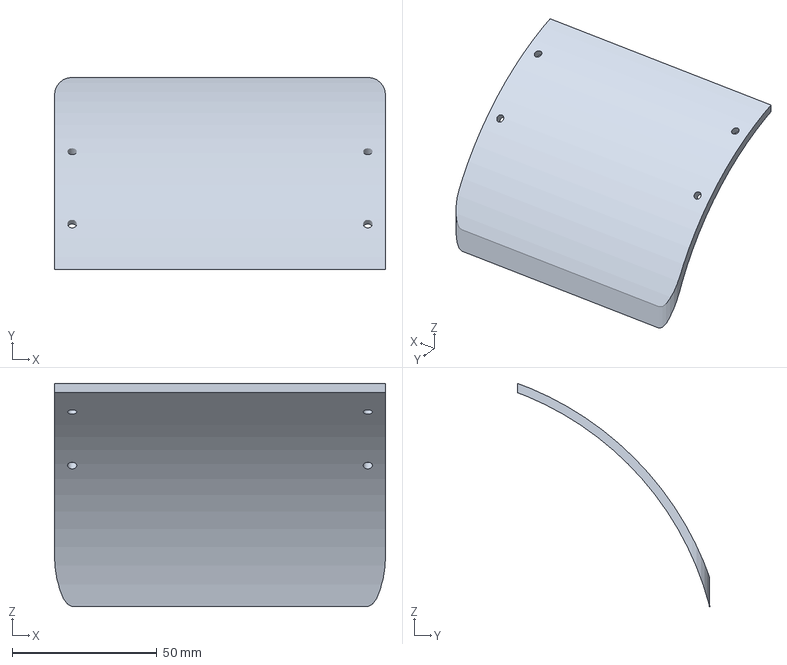
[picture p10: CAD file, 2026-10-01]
models/rear-lid.3mf
114.2 x 66.3 x 77.0 mm

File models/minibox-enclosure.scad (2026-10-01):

/*
  Sketch-based enclosure. Units: mm.
  X = left/right, Y = front/back, Z = up.
  The front screen, rear quarter-arc cover and screen bracket print separately.
  Unmeasured radii, component heights and control windows are provisional.
*/

/* [View] */
part = "screen-bracket"; // [assembly, exploded, bottom, lid, rear-lid, screen-bracket, screen-bracket-print, lid-print, rear-lid-print, bottom-y-up, lid-y-up, rear-lid-y-up, screen-bracket-y-up]
show_modules = false;
explode_height = 35;
$fn = 24;

/* [Enclosure] */
case_width = 120;
deck_depth = 60;
deck_height = 32;
slope_angle = 90;
slope_length = 111;
wall = 2.4;
floor_thickness = 4;
panel_thickness = 3;
joint_clearance = 0.5;
lid_corner_radius = 6;
support_lip_width = 1.5;
support_lip_thickness = 1.5;

/* [Rounded corners] */
bottom_radius = 12;
rim_radius = 6;
bend_radius = 6;

/* [M2.5 fasteners] */
screw_clearance = 2.8;
lid_screw_diameter = 3;
rear_lid_screw_diameter = 3.2;
lid_counterbore_diameter = 4.5;
lid_counterbore_depth = 1.4;
lid_min_edge = 2;
screw_length = 10;
insert_diameter = 4.7;
insert_depth = 5.2;
screw_tip_depth = 8.8;
module_boss_diameter = 8;
shell_boss_diameter = 9;
shell_corner_depth = 7;
rear_mount_depth = 10;
middle_boss_diameter = 7;
middle_mount_y = 49.2;
small_gap_fill = 5;

/* [Controls: joystick left, keyboard right] */
joystick_size = [30, 40];
joystick_hole_spacing = [21, 28];
joystick_center = [31, 29];
joystick_hole_bottom_margin = 4.5;
joystick_hole_top_margin = 7.5;
joystick_window_diameter = 29;
joystick_window_from_left = 13.8;
joystick_window_from_bottom = 14.9;
joystick_lid_gap = 5;
joystick_total_height = 30;
keyboard_size = [57.4, 27.2, 20.6];
keyboard_hole_spacing = [53.34, 22.86];
keyboard_center = [84, 30.1];
keyboard_window = [57.4, 20.2];
keyboard_window_top_margin = 4;
keyboard_window_bottom_margin = 3;
keyboard_lid_gap = 5;
pcb_thickness = 1.6;
module_clearance = 1;
control_clearance = 2;

/* [ESP32 expansion board: rotated 90 degrees on the rear floor] */
esp32_size = [58, 68];
esp32_hole_spacing = [49, 58];
esp32_hole_diameter = 3;
esp32_standoff_height = 5;
esp32_rear_clearance = 20;
esp32_screw_length = 6;
esp32_socket_depth = 5.2;
// Provisional component height above the PCB; measure connectors and the ESP32 stack.
esp32_component_height = 10;

/* [Breadboard: beside ESP32, with aligned front edges] */
breadboard_size = [35, 47];
floor_board_gap = 10;
floor_module_clearance = 10;
floor_side_clearance = 1; // Minimum at the inward-curving bottom wall, not the straight wall
// Provisional thickness; no fixing holes or adhesive thickness have been supplied.
breadboard_height = 10;

/* [Landscape TFT: dimensions rotated together] */
tft_size = [108.04, 61.74];
tft_view = [83.52, 55.68];
tft_hole_spacing = [101.9, 54.9];
tft_view_side_margins = [10, 14.52]; // Left and right PCB edges to the active display
tft_window_clearance = 2; // Total enlargement: 1 mm per side
tft_window_radius = 6;
screen_pcb_thickness = 2;
screen_stack_above_pcb = 3;
screen_front_clearance = 1; // Reserved for acrylic film and assembly clearance
screen_back_height = 4;
screen_back_edge_margin = 8;
screen_shift_along = 26.62;
screen_port_clearance = 8;
screen_bracket_thickness = 3;
screen_bracket_bottom = 25;
screen_bracket_top = 135;
screen_bracket_front_y = 78;
screen_bracket_side_width = 13;
screen_bracket_right_width = 14;
screen_bracket_top_width = 6;
screen_bracket_clearance = 0.3;
screen_bracket_rail_depth = 2.5;
screen_header_opening = [10, 43];

/* [Switch below the screen, right side] */
switch_hole_diameter = 21;
switch_center = [90, 22]; // X and distance along the inclined panel
// Provisional envelope inside the case, not measured switch dimensions.
switch_body_depth = 20;
switch_body_diameter = 21;

/* [Audio openings left of the switch] */
speaker_diameter = 23;
speaker_hole_diameter = 23.5;
speaker_center = [30, 22];
microphone_hole_diameter = 5;
microphone_center = [60, 22];
// Provisional internal depths; mounting hardware and wiring are not yet measured.
speaker_body_depth = 10;
microphone_body_depth = 10;

/* [Rear panel Type-C sockets] */
typec_hole_diameter = 12;
typec_hole_spacing = 20;
typec_thread_diameter = 10.5;
typec_thread_length = 14.5;
typec_head_diameter = 13.8;
typec_head_thickness = 2;
typec_nut_outer_size = 14;
typec_nut_thickness = 3;

/* [Optional cable opening: absent in sketch] */
enable_cable_opening = false;
cable_opening = [16, 10];
cable_opening_z = 10;

/* [Hidden] */
eps = 0.02;
screen_top_y = deck_depth;
rear_height = deck_height + sin(slope_angle) * slope_length;
rear_arc_radius = slope_length;
screen_bracket_left = 4.5;
screen_bracket_right = case_width - 4.5;
rear_seam_angle = 20;
rear_seam_gap = 0.5;
rear_hole_stagger = 0;
rear_seam_y = deck_depth + rear_arc_radius * sin(rear_seam_angle);
typec_center_z = 21;
// Conservative envelope if the quoted hex size is across flats rather than corners.
typec_nut_envelope = typec_nut_outer_size / cos(30);
screen_board_gap = screen_stack_above_pcb + screen_front_clearance;
screen_mount_gap = screen_pcb_thickness + screen_board_gap;
screen_mount_normal = -panel_thickness - screen_mount_gap;
screen_window_offset = [(tft_view_side_margins[0] - tft_view_side_margins[1]) / 2, 0];
tft_center = [case_width / 2, 46 + screen_shift_along];
tft_rear_extent = deck_depth - screen_mount_normal;
floor_side_inset = (case_width - esp32_size[0] - floor_board_gap - breadboard_size[0]) / 2;
// Above-floor parts are checked in 3D, rather than wasting their entire XY projection.
esp32_front_y = max(keyboard_center[1] + keyboard_size[1] / 2,
                   joystick_center[1] + joystick_size[1] / 2,
                   middle_mount_y + middle_boss_diameter / 2) + floor_module_clearance;
esp32_center = [floor_side_inset + esp32_size[0] / 2,
                esp32_front_y + esp32_size[1] / 2];
breadboard_center = [case_width - floor_side_inset - breadboard_size[0] / 2,
                    esp32_front_y + breadboard_size[1] / 2];
breadboard_mount_z = floor_thickness;
floor_group_rear = esp32_front_y + max(esp32_size[1], breadboard_size[1]);
esp32_mount_z = floor_thickness + esp32_standoff_height;
case_depth = ceil(max(screen_top_y + rear_arc_radius,
                      tft_rear_extent + 10 + shell_boss_diameter / 2 + module_clearance,
                      floor_group_rear + esp32_rear_clearance + wall));
keyboard_window_offset = [0, (keyboard_window_bottom_margin - keyboard_window_top_margin) / 2];
keyboard_window_center = keyboard_center + keyboard_window_offset;
keyboard_mount_z = deck_height - panel_thickness - keyboard_lid_gap;
keyboard_standoff_height = keyboard_mount_z - floor_thickness;
// Peripheral components remain provisional; the measured opening bounds the tall keys.
keyboard_component_height = keyboard_lid_gap - pcb_thickness - module_clearance;
joystick_hole_center = joystick_center +
    [0, (joystick_hole_bottom_margin - joystick_hole_top_margin) / 2];
joystick_window_center = joystick_center - joystick_size / 2 +
    [joystick_window_from_left, joystick_window_from_bottom];
joystick_mount_z = deck_height - panel_thickness - joystick_lid_gap;
joystick_standoff_height = joystick_mount_z - floor_thickness;
joystick_component_height = joystick_lid_gap - pcb_thickness - module_clearance;
shell_hole_x = [9, case_width - 9];
shell_hole_y = [11, 114, case_depth - 32];
shell_head_diameter = lid_counterbore_diameter;
profile_vertices = [
    [0, 0], [case_depth, 0], [case_depth, deck_height],
    [screen_top_y, rear_height], [deck_depth, deck_height], [0, deck_height]
];
profile_radii = [
    bottom_radius, bottom_radius, rim_radius,
    bend_radius, bend_radius, rim_radius
];
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

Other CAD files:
models/bottom.3mf
models/rear-lid-y-up.stl
models/lid-y-up.stl
models/screen-bracket.3mf
models/bottom.stl
models/lid.stl
models/rear-lid.stl
models/screen-bracket.stl

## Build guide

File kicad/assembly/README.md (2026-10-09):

# 当前载板装配资料

本目录只有当前资料，历史由Git保存，不使用日期revision子目录或旧quote入口。
这些资料仍为工程审核输入，不等于生产批准。

| 文件 | 用途 |
|---|---|
| `bom-all-review.csv` | 全部物理件的精确型号、C编号及单板数量，上传全装配BOM |
| `positions-jlc-review.csv` | 已适配嘉立创库原点/零角的坐标，上传全装配CPL |
| `positions-all-review.csv` | KiCad自身参考中心和角度，不能替代工厂CPL |
| `jlc-placement-review.json` | 原CAD值、工厂修正值、逐孔误差及文件哈希 |
| `jlc-saved-placement.json` | 工厂实际存档刷新读回，仅对绑定的PCB哈希有效 |
| `pin-map.csv` / `assembly-pads.svg` | 逐孔网络与实际装配图 |
| `drc.json` / `manifest.json` | 实际导出门槛、配套哈希和未决审核项 |
| `minibox-assembly-review.zip` | 综合审核包，不作为纯Gerber上传 |
| `bom-smt-review.csv` / `cpl-smt.csv` | 仅贴片部分，不能用于全板焊接 |

修改PCB后运行`..\export_revision.py`同步所有当前输出；
更新渲染或文档后运行`..\package_review.py`刷新审核包及哈希。
布局改变时沿用已验证采购ID及库datum定义，从新PCB重算位置/角度；
不能复制旧工厂快照的绝对坐标。需要重新核对网页，但不应再逐件手调。

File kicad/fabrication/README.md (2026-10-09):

# 当前 PCB CAM 资料

本目录固定保存当前板的Gerber、PTH/NPTH钻孔与钻孔图。
上传PCB使用`minibox-gerber-review.zip`；它仅含CAM，不含BOM或操作文档。
历史版本由Git保存，不创建日期revision目录或并存旧版ZIP。

运行`..\export_revision.py`重新检查实际PCB、四层CAM与钻孔配套。
装配BOM、工厂坐标及哈希清单在`..\assembly`。
零DRC与数字对位不代表工厂叠层、插件工艺、实物配合或生产批准。

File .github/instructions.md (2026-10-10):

# 仓库说明

本文从 `talking-alarm` 的仓库说明调整而来，适用于 Minibox。

## 通用

- 保持修改聚焦，优先选择简单、明确的方案，不顺带重构无关代码。
- 文件和目录使用英文无空格名称；C 源码和头文件使用小写下划线命名。
- 不自动生成 prompt 档案、开发日志或大量测试脚本；用户要求时再写。
- 用户明确要求保持构建简单，不要添加自定义构建框架或过多 Python 测试。
- 不默认创建虚拟环境；ESP-IDF 使用已安装的 Python 环境。

## 目录

- `esp32_idf_s3n16r8/`：独立 ESP-IDF 固件项目。
- `models/`：3D 模型、STL、3MF、机械尺寸说明及模型检查脚本。
- `docs/`：模块参数、接线及其他项目文档。
- `.github/skills/`：构建、开发日志及 PCB 设计布线技能。
- 不依赖 `C:\gitroot\talking-alarm` 运行或构建；该仓库只作参考。

## 固件与硬件

- 使用 ESP-IDF 5.3.5、C 和 FreeRTOS，不引入 Arduino 草图结构。
- 主控为 ESP32-S3 N16R8：16 MB Quad Flash（DIO、80 MHz），
  8 MB Octal PSRAM（40 MHz）；目标固定为 `esp32s3`。
- 屏幕为 ST7796 SPI、横屏 480 × 320，使用乐鑫官方
  `espressif/esp_lcd_st7796` 组件，不套用参考项目的 ST7789 初始化；
  不引入 Arduino 或 TFT_eSPI。
- 屏幕接线：LED=GPIO9、SCK=GPIO10、SDI=GPIO11、DC/RS=GPIO12、
  Reset=GPIO13、CS=GPIO14。
- 当前改版四个机械轴分别接 GPIO4/5/6/7 与 GND，不接 VCC；
  默认低有效并使用内部上拉，可在菜单中切换为高有效。
  摇杆 X=GPIO1、Y=GPIO2 的代码保留，但当前测试不启用。
  摇杆按压不使用，PCB 按压触点保持 NC；GPIO17 悬空 NC。
  RTC SDA=GPIO15、SCL=GPIO16，仅预留配置，当前未实现驱动。
- INMP441 SD=GPIO21、WS=GPIO39、SCK=GPIO40，L/R 接 GND（左声道）；
  模块正面视角左列从上到下为 L/R、WS、SCK，右列为 GND、VCC、SD。
  MAX98357 DIN=GPIO41、LRC=GPIO39、BCLK=GPIO40、SD/MODE=GPIO47、
  GAIN=GPIO42。GPIO47 播放时为高、其余时间为低，GPIO42 默认高阻；
  两模块半双工共用时钟，先释放当前 I2S 通道再切换；
  GPIO5 按住录音（最多 3 秒）、松开回放。
- GPIO48 控制板载 WS2812 RGB LED；启动时发送黑色数据熄灯。
  不要只拉低引脚，也不要误关 GPIO9 的屏幕背光。
- 逻辑电平及摇杆供电为 3.3 V，所有模块共地；屏幕 VCC 和背光驱动须遵守模块规格。
- GPIO19/20 保留给原生 USB，避免使用被 Octal PSRAM 占用的 GPIO35/36/37。
- 接线和参数的权威文档为 `docs/hardware-connections.md`，硬件变化时同步更新。

## PCB 设计与布线

- PCB 设计、布局、布线、包地审查和生产资料准备使用
  [design-route-minibox-pcb](skills/design-route-minibox-pcb/SKILL.md)。
- 嘉立创 PCB、全元件装配询价与下单使用
  [order-jlc-minibox](skills/order-jlc-minibox/SKILL.md)；
  区分贴片、插件与模块组装，数量和最终费用确认后才提交购买。
- 嘉立创工艺能力与项目推荐值见
  [PCB 设计规范](../docs/jlc-pcb-design-spec.md)；生产前核对最新官方参数。
- 工艺文档不代表现有 PCB 已达标；不得把未完成布线或未确认 BOM 的工程
  标记为可生产。`kicad` 原载板与 `kicad_ex` 集成工程分别维护。
- 修改PCB布局、封装、选型或引脚后，必须在同一任务同步实际PCB、
  生成/导出源码、精确型号/C编号BOM、工厂专用CPL、中心/角度修正报告、
  Gerber/钻孔、装配图、manifest及审核包；未通过导出门槛不得声称可下单。
  复用已验证的工厂库原点/零角映射，从新版PCB重算，不靠网页逐件手调。
- 当前载板资料固定在`kicad\assembly`与`kicad\fabrication`，
  不创建日期revision目录或并存旧报价入口；历史由Git提交保存。
  manifest用PCB/文件哈希验证配套，不用日期目录代替版本控制。
  工厂保存快照绑定PCB哈希，布局改变后不得当作新版已验证。
- 下单agent或sub-agent验证过的页面入口、按钮、步骤、失败原因和解决方式
  必须回写下单skill；项目元件ID、坐标/角度及修正值只放BOM/CPL/报告，
  不把具体订单参数、账号、地址或临时element_index写入skill。

## 构建、烧录与验证

- 在已经初始化的 ESP-IDF 5.3.5 PowerShell 中进入 `esp32_idf_s3n16r8`，
  直接执行 `idf.py build`。
- 用户明确要求烧录时执行 `idf.py -p COM8 flash`；当前实板端口为 COM8，
  换机、端口消失或存在歧义时先识别设备。
- 需要日志时使用 `idf.py -p COM8 monitor`，退出后释放串口。
- 优先增量构建，不随意执行 `fullclean`、删除构建缓存或重复 `set-target`。
- 使用最小必要验证。已有模型检查用标准库 unittest，不新增 Python 测试框架。
- 构建成功、烧录成功、初始化成功与肉眼确认屏幕/按键正常是不同结果，不能混为一谈。
- 当前测试无需摇杆校准；观察四个按钮的屏幕状态及 GPIO5 的录放音日志。

## 代码风格

- 沿用现有 C 命名和 `esp_err_t` 错误处理，配置常量集中管理。
- 模块职责清晰，不引入仅用于转发的多层封装。
- 错误通过返回码、ESP-IDF 日志或屏幕明确报告，不静默失败。
- 源码默认 ASCII，注释简短，只解释不明显的逻辑；中文文档保留 UTF-8。
- `sdkconfig.defaults` 保持 ASCII，避免 Windows 配置工具编码问题。

## 文档与版本控制

- 文档保持简洁，包含实际可用的命令和明确的硬件前提。
- 路径或使用方式变化时更新链接；机械模型的命令在 `models` 下执行。
- STL/3MF 及 `font_data/` 下带许可证的字体是需要保留的交付文件，
  不因其是导出产物而删除；普通构建不重新生成字体。
- 不提交 `build/`、生成的 `sdkconfig`、虚拟环境、缓存、临时串口日志或凭据。
- Git commit、push 和烧录需要用户明确请求；不强推，不覆盖他人的改动。

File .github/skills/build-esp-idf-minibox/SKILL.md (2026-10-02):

---
name: build-esp-idf-minibox
description: 'Build, flash, or monitor the Minibox ESP32-S3 N16R8 hardware test using standard ESP-IDF commands on Windows.'
argument-hint: 'Specify build, flash, monitor, or a COM port; the current board is COM8.'
user-invocable: true
disable-model-invocation: false
---

# Build and flash Minibox

Adapted from the `talking-alarm` build skill. Keep the workflow simple:
use standard ESP-IDF commands, without extra build scripts or Python tests.

## Project

- Directory: `esp32_idf_s3n16r8`
- Target: `esp32s3`, fixed in the top-level CMake file
- SDK: ESP-IDF 5.3.5
- Hardware: N16R8, 16 MB Quad Flash and 8 MB Octal PSRAM
- Current serial port: COM8 (CH343 USB-UART)
- LCD: official `espressif/esp_lcd_st7796` 1.4.0, pinned in
  `main/idf_component.yml` and `dependencies.lock`; no Arduino dependency
- Wiring: [hardware-connections.md](../../../docs/hardware-connections.md)

## Environment

Prefer an already initialized ESP-IDF 5.3.5 PowerShell terminal.
Do not assume a plain PowerShell has `idf.py`, CMake or the toolchain on PATH.

The installations used on this computer are:

- SDK: `C:\esp\v5.3.5\esp-idf`
- Tools: `C:\Espressif`
- SDK Python: `C:\Espressif\tools\python\v5.3.5\venv\Scripts\python.exe`

If initialization is needed, use the installed SDK's official `export.ps1`
or `tools\idf_tools.py export` with the matching tools/Python environment.
Do not blindly invoke the old reference repository's missing
`Initialize-Idf.ps1` or hard-coded installation ID.
Keep environment setup and the requested command in the same shell process.

## Commands

From the repository root:

```powershell
Set-Location .\esp32_idf_s3n16r8
idf.py build
```

Only when flashing is explicitly requested:

```powershell
idf.py -p COM8 flash
```

To monitor an already flashed board:

```powershell
idf.py -p COM8 monitor
```

Exit the monitor with `Ctrl+]` and release the serial port.
Do not flash a different device when COM8 is absent or ambiguous.
Avoid `fullclean`, deleting the build directory, or rerunning `set-target`
for routine changes. Use `idf.py reconfigure` only when configuration needs it.

## Outputs and checks

- `build\minibox_hardware_test.bin`
- `build\minibox_hardware_test.elf`
- `build\fonts.bin` (SPIFFS image; included automatically in `idf.py flash`)
- Bootloader and partition data are flashed by `idf.py`; do not hand-code offsets.

Keep generated outputs and local logs out of Git.
The licensed prebuilt assets in `font_data` are an intentional exception:
keep them checked in. Normal builds do not need a font download or conversion.
The first build needs network access to resolve the official LCD component;
later builds reuse the component manager cache.
Keep `sdkconfig.defaults` ASCII-only.
For hardware verification, inspect ST7796 initialization and the displayed
GPIO4/5/6 button states. GPIO5 starts microphone recording while held
(maximum 3 seconds) and plays the recording after release. Buttons default
to active-low with internal pull-ups; use menuconfig for active-high modules.
GPIO48 should receive the black/off RGB command at startup.
Report build, flash and hardware observations separately; serial logs alone
cannot prove the visible display or all physical inputs work.

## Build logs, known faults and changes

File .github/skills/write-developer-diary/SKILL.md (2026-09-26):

---
name: write-developer-diary
description: 'Write or update a developer diary entry for repository work. Use when asked to write a development log, dev diary, work log, implementation notes, change notes, or a dated engineering progress record.'
argument-hint: '描述要记录的工作内容、目标日期，以及是新建还是追加。'
user-invocable: true
disable-model-invocation: false
---

# 编写开发日志

当用户希望记录一条简洁的工程开发日志，用来说明改了什么、为什么改、如何验证，以及还有什么未完成内容时，使用这个 skill。

这个 skill 的长期目标，不只是记录工作过程，还要让这些日志在积累后可以像一本按日期展开的工程手记，方便别人阅读、学习和复盘。

## 输出位置

仅在用户要求开发日志时，将日志写入 `docs/developer_diary/`。

文件命名规则：

- 文件名使用 `docs/developer_diary/YYYY-MM-DD-XX-topic-slug.md`
- `XX` 是当天日志序号，从 `01` 开始递增
- `topic-slug` 使用简短主题名，采用小写加连字符，不使用空格
- 同一天可以有多篇日志，通过序号和主题区分，而不是把所有内容都堆进同一个文件
- 文件名和文件夹名不得包含空格

使用 [entry_template.md](./assets/entry_template.md) 作为模板。
模板是起点，不是硬性格式。写日志时应根据当天工作的类型自由取舍小节，不要求每篇都套成同一种八股文结构。

## 操作步骤

1. 确定目标日期。如果用户没有指定日期，则使用当前本地日期。
2. 在写日志前，先检查仓库改动、相关文件、验证结果及当前任务的实际用户要求。若已有相关 prompt 记录可参考，但不要为写日志创建 `copilot_notebook/` 或复制全部会话。
3. 只总结这个仓库里真实完成的工作，不要虚构进展。
4. 先判断当天工作的类型，再决定日志结构。例如：
   - 硬件调试可以写接线、供电、设备地址、上传结果
   - ESP-IDF 固件开发可以写目标芯片、构建、串口、烧录与启动日志
   - 文档整理可以写结构调整、命名规则、链接更新、写作意图
5. 在适用时包含以下部分：
   - 给智能体的提示词
   - 概要
   - 变更内容
   - 验证情况
   - 遗留问题
   - 下一步
   - 其他更贴合任务的自定义小节，例如：背景、概念补充、接线步骤、参数设计、数据处理流程、设计考虑、经验记录
6. 语气保持直接、偏工程记录风格，避免营销式表达和空泛状态描述。
7. 确定当天的日志序号和主题短名，按 `YYYY-MM-DD-XX-topic-slug.md` 命名新文件。
8. 如果当天已经有其他日志，不要强行追加到旧文件；只有在用户明确要求续写同一主题时，才追加到原文件。
9. 如果工作未完成或被阻塞，要明确写出阻塞点。

## 内容规则

- 优先使用简短段落或单层项目列表
- 在有帮助时写出具体文件路径
- 记录实际执行过的命令或测试
- 明确区分“已完成工作”和“计划中的工作”
- 不要写入密钥、凭据或无关的终端噪声
- 默认假设未来读者并不了解当前上下文，因此在必要时补充简短背景
- 除了记录“做了什么”，也尽量写清“为什么这么做”以及“从中学到了什么”
- 让单篇日志可以独立阅读，同时又能和同一天或后续日期的日志自然衔接
- 小节应服务于内容，不要为了形式把不相关的段落硬塞进日志里
- 如果存在相关的用户 prompt 记录，优先把这些记录提炼进“给智能体的提示词”小节，并将该小节放在日志较靠前的位置
- 没有相关 prompt 记录时，可以基于实际完成的工作补写可复用提示词，但不要伪造原始 prompt 文本
- Minibox 的接线参数引用 `docs/hardware-connections.md`，模型参数引用 `models/module-dimensions.md`，不复制一份容易过期的接线表
- 区分编译成功、烧录校验、串口初始化日志及实物现象；不能把日志输出当作肉眼验收
- 如果当天是软件开发日志，就不要机械加入“接线步骤”之类无关内容
- 如果当天是硬件调试日志，也不必硬写“参数设计”之类无关内容

## 面向长期分享的写法

如果用户希望这些日志未来能整理成类似一本书的内容，写作时应额外满足下面几点：

- 开头先交代问题背景，让不了解项目的人也能跟上
- 重要改动要写明设计取舍，而不是只列结果
- 遇到错误、返工或修正时，记录原因和调整过程
- 在结尾补一小段“经验”或“教训”，方便后续汇编时复用
- 保持真实，不为了可读性去虚构顺利过程
- 章节感来自清晰取舍和稳定叙事，不来自每篇都使用完全相同的小节标题

## 示例触发语

- 给今天写一篇开发日志
- 记录今天的实现日志
- 为这次改动追加一条开发记录
- 创建一篇带日期的工程开发日志

## 参考资料

- [entry_template.md](./assets/entry_template.md)
- [diary_style.md](./references/diary_style.md)

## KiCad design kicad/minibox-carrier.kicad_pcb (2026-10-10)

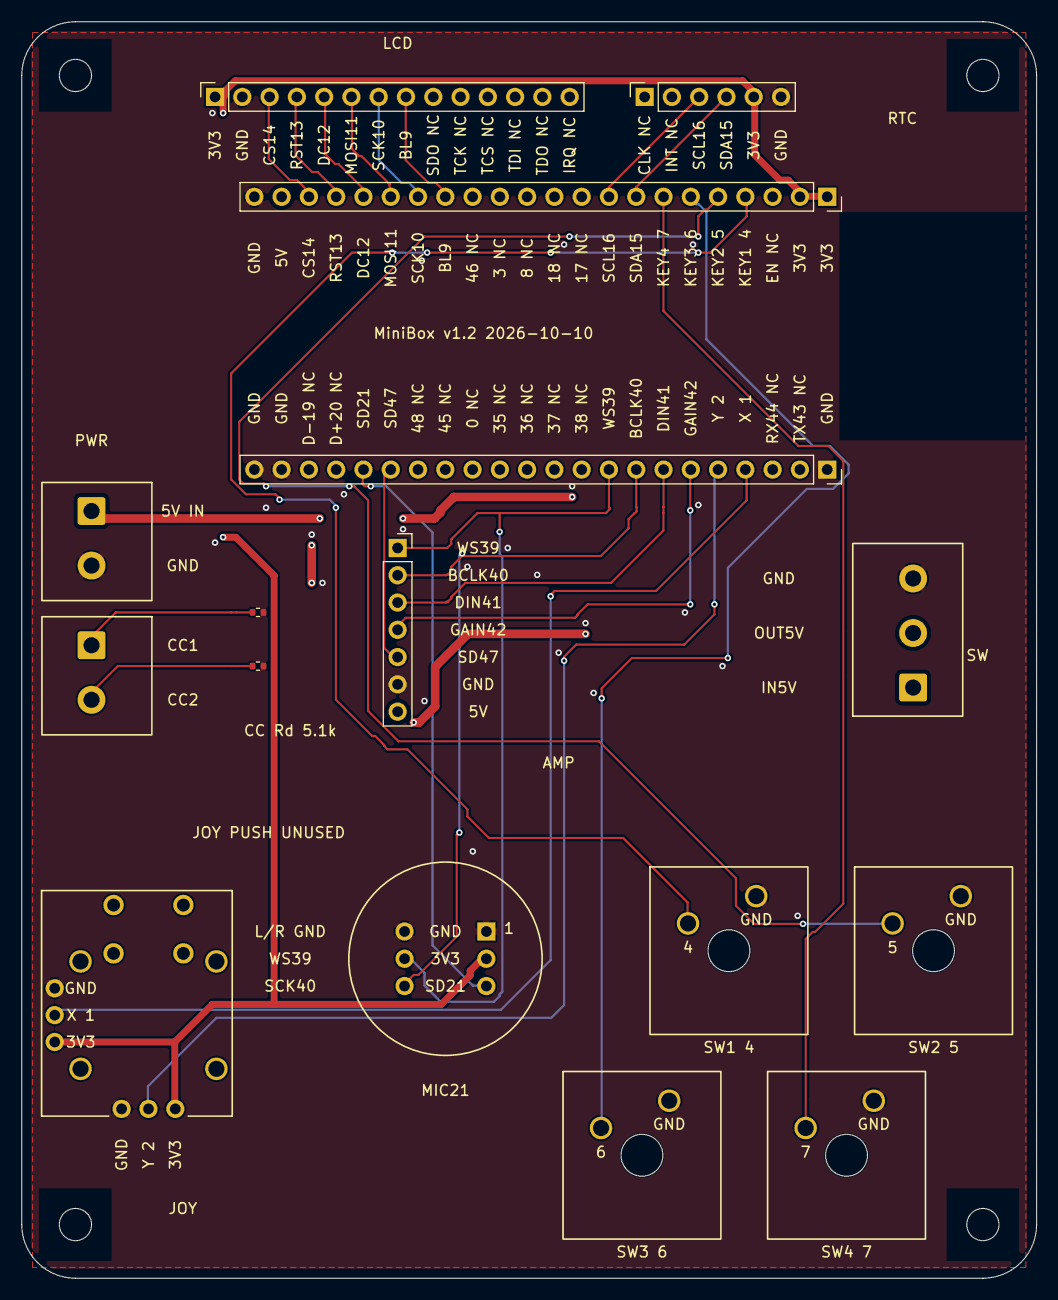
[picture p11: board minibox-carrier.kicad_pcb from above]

Board: 4 copper layers, 94.5 x 117.0 mm, 20 parts (0 on the bottom side), 26 nets.

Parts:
H1, H2, H3, H4: M3 NPTH; MountingHole_3mm
J1: ESP32-S3 J1 - USB LEFT; PinSocket_1x22_P2.54mm_Vertical
J2: ESP32-S3 J3 - USB LEFT; PinSocket_1x22_P2.54mm_Vertical
J3: INMP441 two 1x3 sockets; INMP441_2x03_Row7.62mm
J4: MAX98357A module socket; PinSocket_1x07_P2.54mm_Vertical
J5: PCF8563T upright module; PinSocket_1x06_P2.54mm_Vertical
J6: ST7796 14-pin display; PinSocket_1x14_P2.54mm_Vertical
J7: WJ500V-5.08-03P-14-00A; WJ500V_5.08_3P
J8, J9: WJ500V-5.08-2P; WJ500V_5.08_2P
JS1: YV13S-L7.85-B10Ka(60)-0-DL01; YV13S_L7.85_B10Ka_60_0_DL01
R1, R2: 5.1k 1%; R_0402_1005Metric
SW1, SW2, SW3, SW4: CPG151101D13

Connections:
3V3: J1.1, J1.2, J3.3, J5.5, J6.1, JS1.X3, JS1.Y3
5V_IN: J7.1, J8.1
5V_SW: J1.21, J4.7, J7.2
AMP_GAIN: J2.6, J4.4
AMP_SD: J2.17, J4.5
AUDIO_DIN: J2.7, J4.3
BUTTON1: J1.4, SW1.1
BUTTON3: J1.6, SW3.1
BUTTON4: J1.7, SW4.1
GND: J1.22, J2.1, J2.21, J2.22, J3.1, J3.2, J4.6, J5.6, J6.2, J7.3, J8.2, JS1.X1, JS1.Y1, R1.2, R2.2, SW1.2, SW2.2, SW3.2, SW4.2
GPIO1: J2.4, JS1.X2
GPIO2: J2.5, JS1.Y2
I2S_BCLK: J2.8, J3.6, J4.2
I2S_WS: J2.9, J3.4, J4.1
LCD_BL: J1.15, J6.8
LCD_CS: J1.20, J6.3
LCD_DC: J1.18, J6.5
LCD_MOSI: J1.17, J6.6
LCD_RST: J1.19, J6.4
LCD_SCK: J1.16, J6.7
MIC_SD: J2.18, J3.5
RECORD: J1.5, SW2.1
RTC_SCL: J1.9, J5.3
RTC_SDA: J1.8, J5.4
USB_CC1: J9.1, R1.1
USB_CC2: J9.2, R2.1

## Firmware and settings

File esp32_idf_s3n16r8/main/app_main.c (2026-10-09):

#include "app_config.h"
#include "audio_test.h"
#include "joystick_logic.h"
#include "st7796.h"
#include "test_screen.h"

#include "driver/gpio.h"
#include "driver/rmt_tx.h"
#include "esp_check.h"
#include "esp_psram.h"
#include "esp_timer.h"
#include "freertos/FreeRTOS.h"
#include "freertos/queue.h"
#include "freertos/task.h"

static const char *TAG = "minibox";
static QueueHandle_t s_button_states;

typedef struct {
    bool pressed[BUTTON_COUNT];
} button_snapshot_t;

static void onboard_led_off(void) {
    rmt_channel_handle_t channel;
    rmt_encoder_handle_t encoder;
    const rmt_tx_channel_config_t config = {
        .gpio_num = ONBOARD_LED_PIN,
        .clk_src = RMT_CLK_SRC_DEFAULT,
        .resolution_hz = 10000000,
        .mem_block_symbols = 64,
        .trans_queue_depth = 1,
    };
    ESP_ERROR_CHECK(rmt_new_tx_channel(&config, &channel));
    const rmt_copy_encoder_config_t copy = {};
    ESP_ERROR_CHECK(rmt_new_copy_encoder(&copy, &encoder));
    ESP_ERROR_CHECK(rmt_enable(channel));
    /* WS2812 retains its color when the pin is merely pulled low. Send black. */
    rmt_symbol_word_t black[24];
    for (unsigned i = 0; i < 24; ++i) {
        black[i] = (rmt_symbol_word_t){
            .level0 = 1, .duration0 = 3,
            .level1 = 0, .duration1 = 9,
        };
    }
    const rmt_transmit_config_t transmit = {.flags.eot_level = 0};
    ESP_ERROR_CHECK(rmt_transmit(channel, encoder, black, sizeof(black), &transmit));
    ESP_ERROR_CHECK(rmt_tx_wait_all_done(channel, 100));
    vTaskDelay(pdMS_TO_TICKS(1));
    ESP_ERROR_CHECK(rmt_disable(channel));
    ESP_ERROR_CHECK(rmt_del_encoder(encoder));
    ESP_ERROR_CHECK(rmt_del_channel(channel));
    ESP_ERROR_CHECK(gpio_set_direction(ONBOARD_LED_PIN, GPIO_MODE_OUTPUT));
    ESP_ERROR_CHECK(gpio_set_level(ONBOARD_LED_PIN, 0));
}

static void sample_buttons(void *arg) {
    (void)arg;
    const gpio_num_t pins[] = {BUTTON_1_PIN, RECORD_BUTTON_PIN, BUTTON_3_PIN, BUTTON_4_PIN};
    joystick_button_t buttons[BUTTON_COUNT] = {0};
    TickType_t last_wake = xTaskGetTickCount();
    for (;;) {
        button_snapshot_t snapshot;
        int64_t now_ms = esp_timer_get_time() / 1000;
        for (int i = 0; i < BUTTON_COUNT; ++i) {
            bool pressed = gpio_get_level(pins[i]) ==
#ifdef CONFIG_MINIBOX_BUTTON_ACTIVE_LOW
                           0;
#else
                           1;
#endif
            bool before = buttons[i].pressed;
            joystick_button_update(&buttons[i], pressed, now_ms);
            snapshot.pressed[i] = buttons[i].pressed;
            if (before != buttons[i].pressed) {
                ESP_LOGI(TAG, "GPIO%d %s", pins[i], buttons[i].pressed ? "pressed" : "released");
            }
        }
        audio_test_submit(&buttons[1]);
        xQueueOverwrite(s_button_states, &snapshot);
        xTaskDelayUntil(&last_wake, pdMS_TO_TICKS(10));
    }
}

void app_main(void) {
    onboard_led_off();
    ESP_LOGI(TAG, "ESP32-S3 N16R8 microphone test; PSRAM=%u bytes",
             (unsigned)esp_psram_get_size());
    ESP_ERROR_CHECK(st7796_init());
    ESP_ERROR_CHECK(test_screen_audio_init());
    const gpio_config_t inputs = {
        .pin_bit_mask = (1ULL << BUTTON_1_PIN) |
                        (1ULL << RECORD_BUTTON_PIN) |
                        (1ULL << BUTTON_3_PIN) |
                        (1ULL << BUTTON_4_PIN),
        .mode = GPIO_MODE_INPUT,
#ifdef CONFIG_MINIBOX_BUTTON_ACTIVE_LOW
        .pull_up_en = GPIO_PULLUP_ENABLE,
#else
        .pull_down_en = GPIO_PULLDOWN_ENABLE,
#endif
    };
    ESP_ERROR_CHECK(gpio_config(&inputs));
    s_button_states = xQueueCreate(1, sizeof(button_snapshot_t));
    ESP_ERROR_CHECK(s_button_states ? ESP_OK : ESP_ERR_NO_MEM);
    ESP_ERROR_CHECK(audio_test_start());
    BaseType_t created = xTaskCreate(sample_buttons, "buttons", 4096,
                                     NULL, 5, NULL);
    ESP_ERROR_CHECK(created == pdPASS ? ESP_OK : ESP_ERR_NO_MEM);
    ESP_LOGI(TAG, "Buttons " BUTTON_GPIO_LABELS " ready; hold " RECORD_GPIO_LABEL
             " to record (max 3s)");
    for (;;) {
        button_snapshot_t snapshot;
        if (xQueueReceive(s_button_states, &snapshot, pdMS_TO_TICKS(1000)) != pdTRUE) {
            ESP_LOGE(TAG, "Button sampling stopped");
            ESP_ERROR_CHECK(test_screen_message("BUTTON ERROR", "CHECK " BUTTON_GPIO_LABELS));
            return;
        }
        ESP_ERROR_CHECK(test_screen_audio_update(snapshot.pressed, audio_test_phase()));
    }
}

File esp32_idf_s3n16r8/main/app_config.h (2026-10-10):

#pragma once

#include "sdkconfig.h"

#define LCD_WIDTH 480
#define LCD_HEIGHT 320
#define LCD_LED_PIN 9
#define LCD_SCK_PIN 10
#define LCD_SDI_PIN 11
#define LCD_DC_PIN 12
#define LCD_RESET_PIN 13
#define LCD_CS_PIN 14
#define LCD_SPI_HZ (CONFIG_MINIBOX_LCD_SPI_MHZ * 1000000)
#define ONBOARD_LED_PIN 48
#define AUDIO_BCLK_PIN 40
#define AUDIO_WS_PIN 39
#define MIC_SD_PIN 21
#define SPEAKER_DIN_PIN 41
#define SPEAKER_SD_MODE_PIN 47
#define SPEAKER_GAIN_PIN 42
#define AUDIO_SAMPLE_RATE 16000
#define AUDIO_MAX_SECONDS 3
#define BUTTON_1_PIN 4
#define RECORD_BUTTON_PIN 5
#define BUTTON_3_PIN 6
#define BUTTON_4_PIN 7
#define BUTTON_COUNT 4
#define RTC_SDA_PIN 15
#define RTC_SCL_PIN 16

#define MINIBOX_STRINGIFY_INNER(value) #value
#define MINIBOX_STRINGIFY(value) MINIBOX_STRINGIFY_INNER(value)
#define BUTTON_GPIO_LABELS "GPIO" MINIBOX_STRINGIFY(BUTTON_1_PIN) "/" \
                          MINIBOX_STRINGIFY(RECORD_BUTTON_PIN) "/" \
                          MINIBOX_STRINGIFY(BUTTON_3_PIN) "/" \
                          MINIBOX_STRINGIFY(BUTTON_4_PIN)
#define RECORD_GPIO_LABEL "GPIO" MINIBOX_STRINGIFY(RECORD_BUTTON_PIN)

#define JOYSTICK_X_PIN CONFIG_MINIBOX_JOYSTICK_X_PIN
#define JOYSTICK_Y_PIN CONFIG_MINIBOX_JOYSTICK_Y_PIN
#define JOYSTICK_K_PIN (-1)
#ifdef CONFIG_MINIBOX_JOYSTICK_K_ACTIVE_LOW
#define JOYSTICK_K_ACTIVE_LEVEL 0
#else
#define JOYSTICK_K_ACTIVE_LEVEL 1
#endif

_Static_assert(JOYSTICK_X_PIN != JOYSTICK_Y_PIN &&
               JOYSTICK_X_PIN != JOYSTICK_K_PIN &&
               JOYSTICK_Y_PIN != JOYSTICK_K_PIN,
               "Joystick pins must be distinct");
_Static_assert(JOYSTICK_X_PIN >= 1 && JOYSTICK_X_PIN <= 10 &&
               JOYSTICK_Y_PIN >= 1 && JOYSTICK_Y_PIN <= 10,
               "ESP32-S3 joystick axes require ADC1 GPIO1-10, not GPIO40/41");
_Static_assert(JOYSTICK_X_PIN != BUTTON_1_PIN &&
               JOYSTICK_X_PIN != RECORD_BUTTON_PIN &&
               JOYSTICK_X_PIN != BUTTON_3_PIN &&
               JOYSTICK_X_PIN != BUTTON_4_PIN &&
               JOYSTICK_Y_PIN != BUTTON_1_PIN &&
               JOYSTICK_Y_PIN != RECORD_BUTTON_PIN &&
               JOYSTICK_Y_PIN != BUTTON_3_PIN &&
               JOYSTICK_Y_PIN != BUTTON_4_PIN &&
               JOYSTICK_K_PIN != BUTTON_1_PIN &&
               JOYSTICK_K_PIN != RECORD_BUTTON_PIN &&
               JOYSTICK_K_PIN != BUTTON_3_PIN &&
               JOYSTICK_K_PIN != BUTTON_4_PIN,
               "Joystick pins must not conflict with keypad pins");
_Static_assert(MIC_SD_PIN != RTC_SDA_PIN && MIC_SD_PIN != RTC_SCL_PIN &&
               SPEAKER_SD_MODE_PIN != BUTTON_4_PIN &&
               SPEAKER_GAIN_PIN != RTC_SDA_PIN && SPEAKER_GAIN_PIN != RTC_SCL_PIN &&
               SPEAKER_SD_MODE_PIN != RTC_SDA_PIN && SPEAKER_SD_MODE_PIN != RTC_SCL_PIN,
               "Revised carrier GPIOs must not share peripheral functions");
_Static_assert(JOYSTICK_X_PIN != SPEAKER_SD_MODE_PIN &&
               JOYSTICK_Y_PIN != SPEAKER_SD_MODE_PIN &&
               JOYSTICK_K_PIN != SPEAKER_SD_MODE_PIN &&
               JOYSTICK_X_PIN != SPEAKER_GAIN_PIN &&
               JOYSTICK_Y_PIN != SPEAKER_GAIN_PIN &&
               JOYSTICK_K_PIN != SPEAKER_GAIN_PIN,
               "Joystick pins must not conflict with amplifier control pins");
_Static_assert(JOYSTICK_K_PIN != AUDIO_BCLK_PIN &&
               JOYSTICK_K_PIN != AUDIO_WS_PIN &&
               JOYSTICK_K_PIN != MIC_SD_PIN &&
               JOYSTICK_K_PIN != SPEAKER_DIN_PIN &&
               JOYSTICK_K_PIN != RTC_SDA_PIN &&
               JOYSTICK_K_PIN != RTC_SCL_PIN,
               "Joystick button must not share I2S or RTC pins");

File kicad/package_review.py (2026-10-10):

"""Package current review outputs only after their PCB/CAM/CPL hashes agree."""

import hashlib
import json
from pathlib import Path
import zipfile


HERE = Path(__file__).resolve().parent
ROOT = HERE.parent
ASSEMBLY = HERE / "assembly"
FABRICATION = HERE / "fabrication"


def digest(path):
    return hashlib.sha256(path.read_bytes()).hexdigest()


def package_review():
    manifest_path = ASSEMBLY / "manifest.json"
    manifest = json.loads(manifest_path.read_text(encoding="utf-8"))
    board = HERE / "minibox-carrier.kicad_pcb"
    cam = FABRICATION / "minibox-gerber-review.zip"
    if manifest["board_sha256"] != digest(board):
        raise RuntimeError("PCB changed: run export_revision.py before packaging")
    if manifest.get("render_source_board_sha256") != digest(board):
        raise RuntimeError("Render provenance differs: run the full export_revision.py")
    if manifest["drc_violations"] or manifest["unconnected_items"]:
        raise RuntimeError("Cannot package a board with DRC or connectivity failures")
    if manifest["gerber_sha256"] != digest(cam):
        raise RuntimeError("CAM differs from the verified export")
    placement = json.loads((ASSEMBLY / "jlc-placement-review.json").read_text(encoding="utf-8"))
    if (placement["board_sha256"] != manifest["board_sha256"] or
            placement["cpl_sha256"] != digest(ASSEMBLY / "positions-jlc-review.csv")):
        raise RuntimeError("JLC placements differ from the saved PCB or verified CPL")
    with zipfile.ZipFile(cam) as archive:
        if archive.testzip() is not None:
            raise RuntimeError("Corrupt CAM archive")
        for name in archive.namelist():
            if Path(name).name != name or archive.read(name) != (FABRICATION / name).read_bytes():
                raise RuntimeError(f"CAM archive entry differs from current file: {name}")
    paths = set()
    for directory in (ASSEMBLY, FABRICATION, HERE / "renders", HERE / "Minibox.pretty"):
        paths.update(path for path in directory.iterdir()
                     if path.is_file() and path != manifest_path and path.suffix != ".zip")
    paths.update([
        board, HERE / "minibox-carrier.kicad_pro", HERE / "fp-lib-table",
        HERE / "README.md", HERE / "carrier-revision.html", HERE / "layout-revision-plan.md",
        HERE / "generate_board.py", HERE / "route_board.py", HERE / "export_revision.py",
        HERE / "add_render_legends.py",
        HERE / "routing_checks.py",
        HERE / "prune_ground_vias.py",
        HERE / "export_jlc_positions.py", HERE / "package_review.py", cam,
        ROOT / "docs" / "hardware-connections.md",
        ROOT / "docs" / "jlc-pcb-design-spec.md",
        ROOT / "hardware_references" / "carrier-revision-references.md",
        ROOT / ".github" / "instructions.md",
        ROOT / ".github" / "skills" / "design-route-minibox-pcb" / "SKILL.md",
        ROOT / ".github" / "skills" / "order-jlc-minibox" / "SKILL.md",
    ])
    datasheets = ROOT / "hardware_references" / "datasheets"
    paths.update(datasheets / name for name in (
        "cpg151101d13.pdf", "yv13s-l7.85-b10ka-60-0-dl01.pdf",
        "wj500v-5.08-series-candidate.pdf",
        *[f"lail-pm2.54-{count}p-l.pdf" for count in (3, 6, 7, 14, 22)]))
    missing = [str(path) for path in paths if not path.is_file()]
    if missing:
        raise RuntimeError(f"Missing review files: {missing}")
    manifest.pop("revision", None)
    manifest["version_control"] = "Git history; current outputs use fixed paths"
    manifest["jlc_placement"] = {
        "file": "positions-jlc-review.csv", "report": "jlc-placement-review.json",
        "physical_components": placement["physical_components"],
        "cpl_sha256": placement["cpl_sha256"], "status": placement["status"],
    }
    manifest["artifact_sha256"] = {
        path.relative_to(ROOT).as_posix(): digest(path) for path in sorted(paths)}
    manifest_path.write_text(json.dumps(manifest, ensure_ascii=False, indent=2) + "\n",
                             encoding="utf-8")
    paths.add(manifest_path)
    destination = ASSEMBLY / "minibox-assembly-review.zip"
    temporary = destination.with_suffix(".tmp")
    try:
        with zipfile.ZipFile(temporary, "w", zipfile.ZIP_DEFLATED) as archive:
            for path in sorted(paths):
                archive.write(path, path.relative_to(ROOT).as_posix())
        with zipfile.ZipFile(temporary) as archive:
            if archive.testzip() is not None:
                raise RuntimeError("Corrupt review archive")
            for path in paths:
                if archive.read(path.relative_to(ROOT).as_posix()) != path.read_bytes():
                    raise RuntimeError(f"Review archive entry differs: {path}")
        temporary.replace(destination)
    finally:
        if temporary.exists():
            temporary.unlink()
    print(f"Verified {len(paths)} current review files")


if __name__ == "__main__":
    package_review()

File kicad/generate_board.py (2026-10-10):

"""Generate the explicitly requested 2026-10-10 carrier revision.

Run only after backing up the routed PCB. This creates an unrouted board;
route_board.py and KiCad DRC are separate, mandatory steps.
"""

import argparse
from pathlib import Path
from math import sqrt

import pcbnew as pcb


HERE = Path(__file__).resolve().parent
LIB = Path(r"C:\Program Files\KiCad\10.0\share\kicad\footprints")
BOARD_FILE = HERE / "minibox-carrier.kicad_pcb"
LEFT, TOP, RIGHT, BOTTOM = 5, 3, 99.5, 120
ANTENNA = (81, 20.6, RIGHT, 42.1)
HOLES = ((10, 8), (RIGHT - 5, 8), (10, BOTTOM - 5), (RIGHT - 5, BOTTOM - 5))
CONTROL_BOUNDARY = 76
KEY_PITCH = 19.05
KEY_CENTERS = ((70.85, 89.5), (70.85 + KEY_PITCH, 89.5),
               (62.75, 89.5 + KEY_PITCH), (81.8, 89.5 + KEY_PITCH))
J1_NAMES = [
    "3V3", "3V3", "EN NC", "KEY1 4", "KEY2 5", "KEY3 6", "KEY4 7",
    "SDA15", "SCL16", "17 NC", "18 NC", "8 NC", "3 NC", "46 NC",
    "BL9", "SCK10", "MOSI11", "DC12", "RST13", "CS14", "5V", "GND",
]
J1_NETS = [
    "3V3", "3V3", None, "BUTTON1", "RECORD", "BUTTON3", "BUTTON4",
    "RTC_SDA", "RTC_SCL", None, None, None, None, None,
    "LCD_BL", "LCD_SCK", "LCD_MOSI", "LCD_DC", "LCD_RST", "LCD_CS", "5V_SW", "GND",
]
J2_NAMES = [
    "GND", "TX43 NC", "RX44 NC", "X 1", "Y 2", "GAIN42", "DIN41",
    "BCLK40", "WS39", "38 NC", "37 NC", "36 NC", "35 NC", "0 NC",
    "45 NC", "48 NC", "SD47", "SD21", "D+20 NC", "D-19 NC", "GND", "GND",
]
J2_NETS = [
    "GND", None, None, "GPIO1", "GPIO2", "AMP_GAIN", "AUDIO_DIN", "I2S_BCLK", "I2S_WS",
    None, None, None, None, None, None, None, "AMP_SD", "MIC_SD", None, None, "GND", "GND",
]


def point(x, y):
    return pcb.VECTOR2I(pcb.FromMM(x), pcb.FromMM(y))


parser = argparse.ArgumentParser(description=__doc__)
parser.add_argument("--replace-routed", action="store_true",
                    help="Explicitly authorize replacing the saved board after backup")
args = parser.parse_args()
if BOARD_FILE.exists() and list(pcb.LoadBoard(str(BOARD_FILE)).GetTracks()) and not args.replace_routed:
    raise RuntimeError("Refusing to overwrite routed PCB: back it up, then use --replace-routed")

board = pcb.BOARD()
board.SetCopperLayerCount(4)
board.SetLayerType(pcb.In1_Cu, pcb.LT_POWER)
board.SetLayerType(pcb.In2_Cu, pcb.LT_POWER)
board.GetDesignSettings().SetAuxOrigin(point(LEFT, BOTTOM))
board.GetDesignSettings().m_SolderMaskExpansion = pcb.FromMM(0.02)
board.GetDesignSettings().m_SolderMaskMinWidth = pcb.FromMM(0.1)
nets = {}


def net(name):
    if name not in nets:
        nets[name] = pcb.NETINFO_ITEM(board, name)
        board.Add(nets[name])
    return nets[name]


def load(reference, library, name, x, y, labels, value, angle=0):
    directory = HERE / "Minibox.pretty" if library == "Minibox" else LIB / (library + ".pretty")
    fp = pcb.FootprintLoad(str(directory), name)
    if fp is None:
        raise RuntimeError(f"Missing footprint: {directory / name}")
    fp.SetFPIDAsString(f"{library}:{name}")
    fp.SetReference(reference)
    fp.SetValue(value)
    fp.SetPosition(point(x, y))
    fp.SetOrientationDegrees(angle)
    fp.Reference().SetVisible(False)
    fp.Value().SetVisible(False)
    for pad in fp.Pads():
        if pad.GetAttribute() != pcb.PAD_ATTRIB_NPTH:
            pad.SetLocalClearance(pcb.FromMM(0.3))
        label = labels.get(pad.GetNumber())
        if label:
            pad.SetNet(net(label))
        if label in ("5V_IN", "5V_SW"):
            pad.SetLocalClearance(pcb.FromMM(0.5))
    board.Add(fp)
    return fp


def socket(reference, count, x, y, labels, value, angle=0):
    return load(reference, "Connector_PinSocket_2.54mm",
                f"PinSocket_1x{count:02d}_P2.54mm_Vertical", x, y,
                {str(i + 1): label for i, label in enumerate(labels)}, value, angle)


def terminal(reference, count, x, y, labels, angle=0):
    return load(reference, "Minibox", f"WJ500V_5.08_{count}P",
                x, y, {str(i + 1): label for i, label in enumerate(labels)},
                "WJ500V-5.08-2P" if count == 2 else "WJ500V-5.08-03P-14-00A", angle)


def text(value, x, y, angle=0, layer=pcb.F_SilkS, size=1):
    item = pcb.PCB_TEXT(board)
    item.SetText(value)
    item.SetPosition(point(x, y))
    item.SetTextSize(point(size, size))
    item.SetTextThickness(pcb.FromMM(0.15))
    item.SetLayer(layer)
    item.SetTextAngle(pcb.EDA_ANGLE(angle, pcb.DEGREES_T))
    board.Add(item)


def shape(start, end, layer=pcb.Dwgs_User, width=0.12, kind=pcb.SHAPE_T_SEGMENT):
    item = pcb.PCB_SHAPE(board)
    item.SetShape(kind)
    item.SetStart(point(*start))
    item.SetEnd(point(*end))
    item.SetLayer(layer)
    item.SetWidth(pcb.FromMM(width))
    board.Add(item)


def envelope(bounds, label):
    x1, y1, x2, y2 = bounds
    shape((x1, y1), (x2, y2), kind=pcb.SHAPE_T_RECT)
    text(label, (x1 + x2) / 2, (y1 + y2) / 2, layer=pcb.Dwgs_User)


def keepout(bounds, allow_pads=False):
    for layer in (pcb.F_Cu, pcb.In1_Cu, pcb.In2_Cu, pcb.B_Cu):
        area = pcb.ZONE(board)
        area.SetLayer(layer)
        area.SetIsRuleArea(True)
        area.SetDoNotAllowPads(not allow_pads)
        area.SetDoNotAllowTracks(True)
        area.SetDoNotAllowVias(True)
        area.SetDoNotAllowZoneFills(True)
        area.Outline().NewOutline()
        x1, y1, x2, y2 = bounds
        for x, y in ((x1, y1), (x2, y1), (x2, y2), (x1, y2)):
            area.Outline().Append(pcb.FromMM(x), pcb.FromMM(y))
        board.Add(area)
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

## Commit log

2026-09-20 Add rounded OpenSCAD enclosure with reinforced module mounts
    Copilot-Session: 726f04ae-9a36-410b-a187-cd5eb1ecf661
    [minibox-enclosure.scad]
2026-09-24 Document module dimensions and enclosure specifications
    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
2026-09-24 Finalize enclosure geometry and export separate printable STL parts
    Add raised screen and audio/switch ports, spherical base corners, counterbored lid fasteners, and a continuous 1.5 mm support rim. Document dimensions and add mesh and clearance regression checks.
    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
    [bottom.stl, lid.stl, minibox-enclosure.scad]
2026-09-25 Compact ESP32 and breadboard layout with smooth rear supports
    Rotate ESP32 beside the breadboard while retaining the 120 mm case width, tighten front and rear clearances, and shorten rear lid mounts with printable curved braces. Update dimensions, regression checks, and separate STL exports.
    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
    [bottom.stl, lid.stl, minibox-enclosure.scad]
2026-09-25 Increase rear clearance and steepen enclosure braces to 75 degrees
    Provide at least 20 mm behind ESP32, lengthen all six braces, and raise the screen to preserve module clearance. Update dimensions, regression checks, and validated bottom and lid STL exports.
    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
    [bottom.stl, lid.stl, minibox-enclosure.scad]
2026-09-25 Correct TFT aperture alignment and measured mounting clearance
    Lower the enclosure, retain R6 aperture corners, and export fn32 printable parts. Shift the TFT window left 2.26 mm with 1 mm straight-edge margins; use a 2 mm PCB and 3 mm display with 6 mm normal mounting clearance. Update dimensions and geometry regression checks.
    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
    [bottom.stl, lid.stl, minibox-enclosure.scad]
2026-09-25 Add Y-up STL exports for website orientation compatibility
    Rotate export coordinates -90 degrees around X while preserving the original Z-up files. Document both conventions and verify mesh topology, volume, bounds and bottom/rear face orientation.
    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
    [bottom-y-up.stl, lid-y-up.stl, minibox-enclosure.scad]
2026-09-25 Add original-coordinate 3MF enclosure exports
    Preserve Z-up assembly placement and millimeter units. Package validated STL meshes without the native 3MF writer's coordinate truncation and verify exact mesh round trips.
    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
    [bottom.3mf, lid.3mf]
2026-09-25 Repair degenerate enclosure faces and strengthen mesh validation
    Unify spherical corners and vertical walls, remove duplicate lower contours, stabilize tangent points, and overlap mounting bridges. Regenerate all STL and 3MF deliverables. Validate zero-area faces, edge-connected shells, vertex links, normals and rounded-coordinate topology; split clearance checks into named groups with progress.
    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
    [bottom-y-up.stl, bottom.3mf, bottom.stl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]
2026-09-26 Add ESP32-S3 hardware test and organize Minibox project
    Move enclosure assets into models, document module wiring, add ST7796 and XYK tests with GPIO48 LED shutdown, and adapt repository instructions and skills.
    [bottom-y-up.stl, bottom.3mf, bottom.stl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]
2026-09-26 Improve bilingual display fonts, partial refresh, and joystick mapping
    Store licensed antialiased CJK/Latin font assets in SPIFFS and preload them into PSRAM. Correct display mirroring, update only changed pixel regions, rate-limit numeric readouts, and adjust X/K behavior from hardware feedback.
    [partitions.csv]
2026-09-26 Stabilize native joystick display readout
    Show normalized X/Y to two decimals instead of noisy ADC counts, with center hysteresis and rate-limited updates. Keep the ESP-IDF ST7796 driver and existing SPIFFS font without Arduino dependencies.
    [test_screen.c]
2026-09-26 Use official Espressif ST7796 LCD component
    Pin espressif/esp_lcd_st7796 1.4.0 for ESP-IDF 5.3, retain the 480x320 wiring and RGB565 orientation at 40 MHz, and skip rendering/transfers when joystick display state is unchanged.
    [app_main.c, st7796.c, test_screen.c]
2026-09-26 Add ESP32-S3 half-duplex audio hardware test
2026-09-27 Add radio playback and GPIO button microphone test
2026-10-01 Redesign enclosure with vertical display and split curved back
    Add printable screen bracket, open guide slots, four-part exports, and hardware reference assets.
    [bottom-y-up.stl, bottom.3mf, bottom.stl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]
2026-10-01 Add provisional KiCad module carrier project
    [minibox-carrier.kicad_pcb]
2026-10-01 Route Minibox carrier and document module pinouts
    [minibox-carrier.kicad_pcb]
2026-10-01 Tighten KiCad carrier rules for JLCPCB fabrication
    [minibox-carrier.kicad_pcb]
2026-10-01 Rotate carrier, clear antenna and export JLCPCB Gerbers
    [minibox-carrier.kicad_pcb]
2026-10-02 Refine two-layer carrier routing, GPIO silk and solderable pads
    Export front and back PNG previews with material legends and refresh two-layer Gerbers.
    [minibox-carrier.kicad_pcb]
2026-10-02 Increase power terminal pad clearance to 0.5 mm
    Refresh two-layer Gerbers and board previews while preserving existing routing and ground thermal relief.
    [minibox-carrier.kicad_pcb]
2026-10-02 Allocate GPIOs by carrier layout and move cable interfaces upward
    Keep joystick axes on ADC1 GPIO1/2, keypad on GPIO4/5/6, local I2S on GPIO39/40/41 and RTC on GPIO47/21. Synchronize firmware, labels, two-layer Gerbers and PNG legends.
    [minibox-carrier.kicad_pcb]
2026-10-02 Align switch body and eliminate right-angle trace elbows
    Preserve vias and branch connectivity while easing short fanout and anchored corners. Confirm switched amplifier supply and atomically refresh matched PNG previews and two-layer Gerbers.
    [minibox-carrier.kicad_pcb]
2026-10-03 Compact MiniBox carrier and add manufacturing identification
    Stack LCD, switch and keypad on a 100x112 mm two-layer board. Add microphone socket models, mechanical dimensions, socket inventory and v1.0 silkscreen. Enlarge safe diagonal routing and refresh fabr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
    [minibox-carrier.kicad_pcb]
2026-10-08 Convert MiniBox carrier to four layers with continuous I2S ground reference
    [bom-quote.csv, minibox-carrier.kicad_pcb, pin-map-quote.csv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]
2026-10-08 docs: add JLC PCB manufacturing and routing guidance
2026-10-09 Redesign Minibox carrier layout and synchronize firmware
    Add four directly soldered keyboard switches, the exact joystick footprint, and Type-C CC pull-downs. Release GPIO42 and synchronize wiring and firmware. Include part references, renders, and engineering-review fabrication and assembly deliverables; production approval remains pending.
    Copilot-Session: e98879a8-1dff-48d4-a7f7-1d056a166875
    [bom-all-review.csv, bom-smt-review.csv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]
2026-10-09 Refine carrier layout and remove redundant ground stitching
    Update pin silkscreen, swap RTC SDA/SCL to GPIO16/15, refine control placement and pad clearance, retain 23 ground vias, and refresh aligned CAM and engineering-review artifacts.
    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
    [minibox-carrier-B_Cu.gbl, minibox-carrier-B_Mask.gbs, minibox-carrier-B_Silkscreen.gbo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]
2026-10-09 Save carrier sourcing and reproducible JLC placement corrections
    Preserve exact part IDs, factory-saved placement readback and datum-aware CPL export. Adapt selected terminal footprints and archive matching manufacturing review files. Document reusable domestic ordering routes and controls separately from board-specific parameters.
    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
    [bom-all-review.csv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]
2026-10-09 Use Git history and stable PCB submission paths
    Require synchronized PCB, BOM, factory placements and manufacturing exports. Preserve verified browser and subagent workflow lessons in skills. Move current artifacts to fixed assembly/fabrication paths, retire obsolete quote files, and integrate hash-checked review packaging into the exporter.
    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
    [bom-all-review.csv, bom-quote.csv, bom-smt-review.csv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]
2026-10-10 Correct carrier GPIO wiring and regenerate JLC review files
    Correct RTC signal identities without changing routed geometry; move amplifier GAIN to42 and microphone SD to21; leave17 NC. Correct microphone pin order, revise controls and power terminal placement, and keep joystick pad copper1.22mm from the left pour boundary. Prune18 redundant ground vias and regenerate all CAM, factory placements, renders and hash-verified review packages. Record official44-pad GPIO audit and the pending JLC submission/factory checks.
    Copilot-Session: d5123da0-77f3-46dc-9275-266fb44de942
    [minibox-carrier-B_Cu.gbl, minibox-carrier-B_Mask.gbs, minibox-carrier-B_Silkscreen.gbo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]
2026-10-10 Record tested INMP441 module without additional pull-down
    Synchronize wiring documentation, export metadata and the assembly review package with the user's confirmed module behavior.
    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
2026-10-10 docs(models): add enclosure section review and reference drawings
    Copilot-Session: be4d3782-cb6c-4313-87c4-bb25fa9460d0
2026-10-11 Refine carrier enclosure for easier printing
    Use a compact upright profile, a clearance-aware shared keyboard opening, two top screws and a recessed speaker grille. Refresh printable meshes, renders and hardware references; use a purchased joystick cap.
    Copilot-Session: 3ebed324-54c3-4b07-bd8d-7ad160e6a0f7
2026-10-11 Correct staggered keyboard opening and PCB installation path
    Accommodate updated microphone and amplifier stack heights, preserve staggered keyboard shoulders, and extend front-seat relief for the verified tilted PCB insertion route. Refresh printable meshes, render gallery, hardware specifications and interactive assembly diagrams.
    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
2026-10-13 Fix enclosure control-edge membranes and refresh render report
    Copilot-Session: 215eb910-a316-4b66-8120-774258ff938e
2026-10-14 Fix integral hollow speaker mounts in enclosure lid
    Include printed speaker sleeves in the lid mesh, reuse M2.5 insert pockets, and provide speaker-frame relief. Refresh verified STL/3MF exports, reports, renders, and checks.
    Copilot-Session: 99478c6d-1a16-4166-b611-7ae7a8771f3c
2026-10-16 Add PCB hardware tests and Donggan 101 speaker mode
    Enable joystick calibration, PCF8563 calendar/ticking checks, combined hardware display, and startup microphone playback. Add optional Donggan 101 Wi-Fi streaming with reconnect and playback status, keeping credentials local and microphone I2S exclusive.
    Audio noise has been reported and remains under investigation; successful I2S output does not verify audible quality.
    Copilot-Session: db391c98-7479-4564-843f-59b0708b3971
2026-10-17 Migrate Talking Alarm features to Minibox LVGL apps
    Preserve Minibox hardware wiring, add private SPIFFS configuration, and move the audio ring to PSRAM to retain radio DMA headroom.
    Copilot-Session: 8333dafd-ffc0-4515-aa40-f869ab00138b
2026-10-17 Swap joystick axes for screen navigation
    Map physical Y to horizontal navigation and X to vertical navigation without changing wiring or axis inversion.
    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
2026-10-17 Correct joystick X direction and use A B X Y button labels
    Update app and diagnostic UI labels, document navigation, and clarify minimal validation guidance.
    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
2026-10-20 Improve NES scaling and stabilize audio playback
    Scale indexed video to 426x320 through LVGL, synchronize APU synthesis with CPU cycles, and pace emulation using complete low-latency audio DMA blocks.
    Copilot-Session: 10094ad5-d005-4510-900d-12ec4c921123
2026-10-20 Optimize NES scaled video and prioritize audio playback
    Move scaling to the display task through an indexed frame mailbox, refresh changed regions, and skip drawing when audio reserves are low. Document the app-only device update and pending hardware acceptance.
    Copilot-Session: 682a64af-c33b-4fca-91ee-d764b8519240
2026-10-24 Track user-supplied ROM set for reproducible device setup
    Allowlist the ten named NES files while keeping credentials, saves and generated images ignored. Document setup from a fresh checkout.
    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
2026-10-25 Add low-profile model-v2 enclosure and final design report
2026-10-29 Reduce font footprint and add verbose BIOS-style startup
2026-10-31 Restore internal DMA headroom for radio playback
    Move temporary boot pixels and radio decoder I/O buffers to PSRAM while retaining existing I2S DMA settings. Release boot pixels after LVGL initialization and propagate speaker startup errors directly.
2026-10-31 Handle intermittent DNS failures in chat alarm
    Retain DHCP DNS and fill an empty backup resolver slot. Retry agent requests once only on pre-request DNS failure and distinguish resolution errors in chat and chime status.
